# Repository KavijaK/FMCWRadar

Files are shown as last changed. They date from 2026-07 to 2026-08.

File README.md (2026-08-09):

# 6 GHz FMCW Radar

A custom Frequency-Modulated Continuous-Wave radar project for contactless distance, velocity, and breathing-rate measurement.

The project combines a mixed-signal RF PCB, STM32-based high-speed data acquisition, USB streaming, and host-side radar signal processing. The board generates a swept 6 GHz-class RF signal, receives reflections, converts them into a lower-frequency beat signal, digitizes that signal, and sends the raw samples to a computer for analysis.

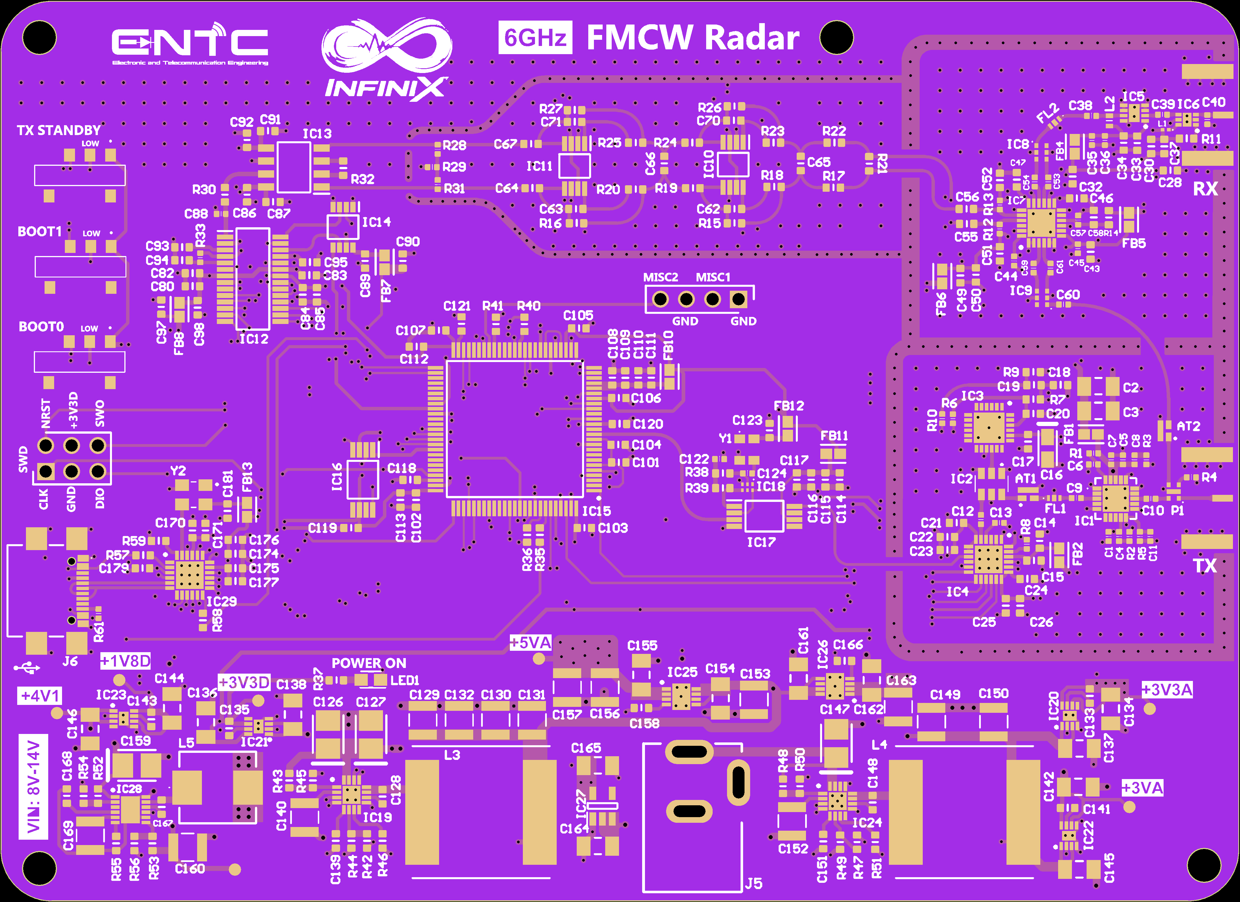
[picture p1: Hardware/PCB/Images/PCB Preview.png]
FMCW radar PCB preview


## What Is FMCW Radar?

FMCW stands for Frequency-Modulated Continuous-Wave.

Instead of transmitting a short pulse, an FMCW radar continuously sends a signal whose frequency changes over time. This frequency sweep is called a chirp. When the transmitted signal reflects from a target and returns to the receiver, the radar mixes the received signal with a copy of the transmitted signal.

The difference between those two frequencies becomes a beat signal. That beat signal can be processed to estimate target distance. By comparing multiple chirps over time, the same radar can also estimate velocity and small periodic motion such as breathing.

```text
Swept RF chirp -> target reflection -> receiver -> mixer beat signal
               -> filtering -> ADC -> USB -> host signal processing
```

## Project Overview

This project is built as a complete radar acquisition platform:

- The RF front end transmits and receives the 6 GHz-class radar signal.
- The mixer converts the received RF signal into an IF beat signal.
- The analog filtering chain prepares the IF signal for digitization.
- A 12-bit high-speed ADC samples the IF waveform.
- An STM32F429 captures the ADC data using hardware peripherals.
- USB High Speed streams raw radar frames to a host computer.
- Host-side DSP can perform range FFTs, velocity estimation, and breathing-rate experiments.
- Custom 15 dBi welded stainless steel horn antenna array with a 3D-printed tripod mount for high-directivity 5.8 GHz FMCW RF capture.

The main design goal is to keep acquisition deterministic. The STM32 does not manually sample the ADC in a software loop. Instead, the radar uses clocked hardware capture, DMA buffering, and USB streaming so the raw waveform can be moved to the computer reliably.

## PCB Design

The board combines RF, analog, digital, power, USB, and debug sections on one PCB.

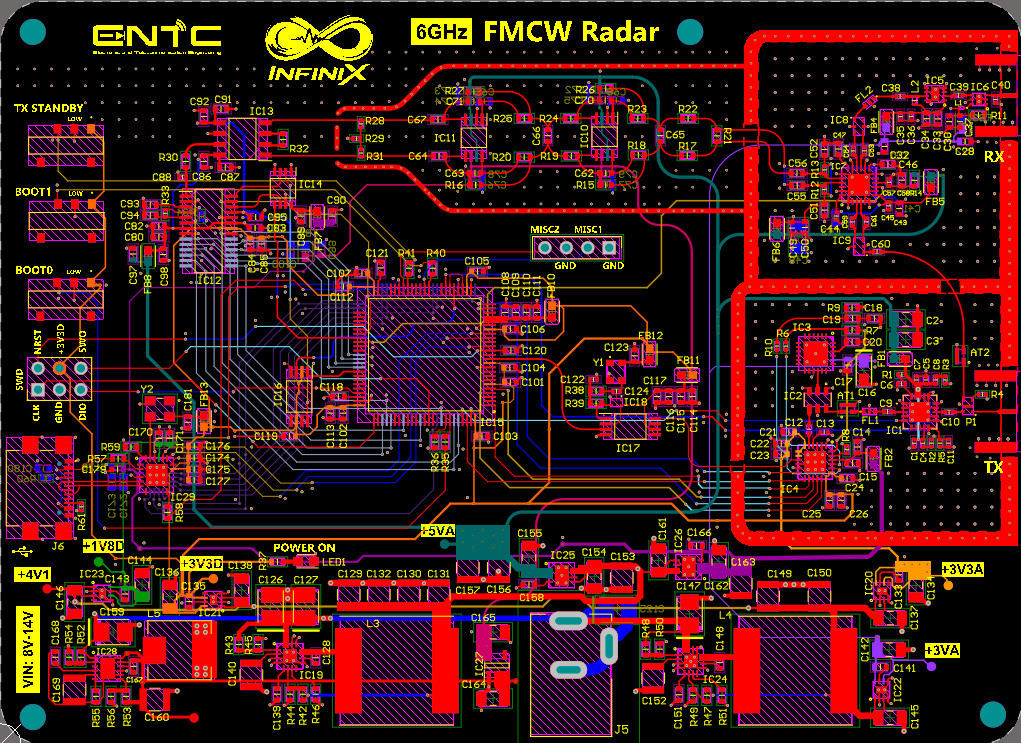
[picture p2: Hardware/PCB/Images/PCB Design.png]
FMCW radar PCB design


The RF transmit and receive sections are separated on the right side of the board. The STM32, ADC, clocking, and digital capture path sit closer to the center. The lower section contains the power supplies and USB-C interface.

## Key Specifications

| Category | Specification |
| --- | --- |
| Radar type | FMCW radar |
| RF class | 6 GHz |
| Main use cases | Distance, velocity, and breathing-rate measurement |
| Chirp / PLL device | ADF4158 |
| ADC | LTC1420 |
| ADC resolution | 12-bit |
| ADC sample rate target | 10 MSps |
| Controller | STM32F429VET6TR |
| Main acquisition interface | DCMI parallel capture |
| Data movement | DMA into SRAM frame buffers |
| USB PHY | USB3317 ULPI |
| Host link | USB 2.0 High Speed |
| Raw payload target | About 20 MB/s |
| Debug interface | SWD and SWO/SWV |
| Host processing | Python / DSP pipeline |

## Hardware Blocks

| Block | Purpose |
| --- | --- |
| Transmitter | Generates and amplifies the swept RF signal. |
| Receiver | Captures and conditions reflected RF energy. |
| Mixer | Converts RF return information into a lower-frequency IF signal. |
| IF filtering | Filters and scales the beat signal for the ADC. |
| ADC | Converts the analog IF waveform into 12-bit digital samples. |
| STM32 controller | Aligns capture timing, frames samples, and streams data. |
| USB interface | Sends raw frames to the host computer. |
| Power system | Generates the analog, digital, RF, ADC, and support rails. |

## Schematic

The full PCB schematic is available here:

[Hardware/PCB/Schematics/FMCWRadar.pdf](Hardware/PCB/Schematics/FMCWRadar.pdf)

The schematic is organized into functional pages:

| Page | Section | Description |
| --- | --- | --- |
| 1 | Transmitter | PLL, VCO, PA, coupler, detector, and RF transmit path. |
| 2 | Receiver | RF receive input, filtering, and gain chain. |
| 3 | Mixer | LO/RF mixing into differential IF outputs. |
| 4 | IF filtering | Differential IF filtering and amplification. |
| 5 | ADC | LTC1420 ADC input stage, clocking, overflow, and parallel data bus. |
| 6 | MCU | STM32F429, clock routing, DCMI bus, debug, and control signals. |
| 7 | Power supply | Regulators and analog/digital power rails. |
| 8 | USB | USB3317 ULPI PHY and USB-C connection. |
| 9 | PCB composite | Board routing and placement overview. |
| 10 | Assembly view | Component placement and reference designators. |
| 11 | BOM | Exported bill of materials. |

## What Has Been Implemented

The hardware design and firmware architecture have been brought together into a working acquisition plan:

- ADF4158-based FMCW chirp generation.
- 10 MHz ADC/DCMI sample-clock path.
- STM32 DCMI capture of the 12-bit ADC bus.
- DMA buffering for continuous high-speed sample movement.
- USB High-Speed streaming to the host computer.
- SWO/SWV debug logs for bring-up.
- Host-side frame parsing and raw capture support.

## Current Status

The project is in firmware bring-up and acquisition validation. The main staged checks are:

1. Power rail validation.
2. Clock validation.
3. USB enumeration.
4. ADF4158 chirp and MUXOUT validation.
5. ADC/DCMI sample capture validation.
6. Continuous USB streaming.
7. Range/velocity/breathing DSP experiments.

One important timing item is still under review: the acquisition architecture assumes one radar slope maps cleanly to one ADC frame. The final ADF4158 slope timing and firmware frame size must be kept consistent before using the captured data for final measurements.

## Repository Areas

| Folder | Contents |
| --- | --- |
| `CAD/` | Mechanical 3D models, horn antenna array, crossbar mounts, and STEP export files. |
| `Docs/` | Supporting documentation and project notes. |
| `DSP/` | Signal-processing work for range, velocity, and breathing-rate estimation. |
| `Firmware/` | STM32 acquisition firmware and host capture tools. |
| `Hardware/` | PCB design, schematic, BOM, and hardware design assets. |

## Goal

The goal is a clear, modular, and debuggable radar platform where each subsystem can be tested independently:

- RF transmit and receive chain
- Mixer and IF path
- ADC sampling
- STM32 capture timing
- USB data streaming
- Host-side radar DSP

That structure makes the project easier to debug, easier to optimize, and easier to hand off for future development.

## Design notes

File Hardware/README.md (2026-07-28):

# Hardware

This directory contains all hardware design files for the FMCW Radar unit.

## Sub-directories

| Directory | Description |
|---|---|
| [`PCB/`](PCB/) | PCB design files including schematics, layout, and bill of materials |
| [`Enclosure/`](Enclosure/) | Mechanical enclosure design files and renderings |
| [`Testing/`](Testing/) | Hardware testing procedures and validation documentation |

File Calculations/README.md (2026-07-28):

## 1. Distance (Range) Measurements and Resolution

In an FMCW radar, distance is measured by calculating the beat frequency ($f_b$) between the transmitted and received signals. To perform this range extraction, the system captures **512 samples per chirp** to build the first dimension of the 2D range-Doppler matrix using a Fast Fourier Transform (FFT).

The system operates with a triangular waveform, sweeping from 5.7 GHz to 5.9 GHz. This provides a total sweep bandwidth ($B$) of 200 MHz. The chirp duration ($T_c$) is 2 ms (0.002 seconds).

**Range Derivation ($R$)**

The target distance is directly proportional to the measured beat frequency. By substituting the speed of light ($c = 3 \times 10^8$ m/s), the 2 ms chirp duration, and the 200 MHz bandwidth into the standard FMCW range equation:

$$
R = \frac{c \cdot T_c \cdot f_b}{2B}
$$

$$
R = \frac{(3 \times 10^8) \cdot 0.002}{2 \cdot (200 \times 10^6)} \cdot f_b
$$

$$
R = 0.0015 \cdot f_b
$$

This coefficient dictates that for every 1 Hz of beat frequency detected by the FFT, the target is 0.0015 meters away. 

**Range Resolution ($\Delta R$)**

The range resolution defines the radar's ability to distinguish between two closely spaced targets in traffic. It is dictated entirely by the 200 MHz bandwidth:

$$
\Delta R = \frac{c}{2B}
$$

$$
\Delta R = \frac{3 \times 10^8}{400 \times 10^6} = 0.75
$$

The system provides a strict range resolution of **0.75 meters**.

**Maximum ADC Limit**

Because the transmitted bandwidth sweeps from 5.7 GHz to 5.9 GHz over 2 ms, the maximum expected beat frequency ($f_b$) for typical traffic targets maxes out at approximately 200 kHz. Since the external ADC operates at a massive 10 MHz sampling frequency, the Nyquist limit (5 MHz) is vastly higher than the 200 kHz beat signal. Therefore, the ADC limit does not constrain or affect the range calculations; the maximum detectable range is strictly limited by the physical transmitting power and environmental losses.

---

## 2. Velocity (Doppler) Measurements and Resolution

Velocity tracking in this architecture employs a dual-method approach to ensure precise slow-speed resolution while accommodating high-speed traffic. The system builds a 2D matrix using **128 chirps** ($N_c$) and 512 samples per chirp to perform a 2D Doppler FFT. For these calculations, the wavelength ($\lambda$) at 5.8 GHz is 0.0517 meters.

**Doppler Velocity Derivation ($v$)**

For micro-Doppler and fine speed measurements, velocity is extracted by analyzing the phase shift ($\Delta \phi$) of the beat signal across consecutive chirps:

$$
v = \frac{\lambda \cdot \Delta \phi}{4\pi T_c}
$$

$$
v = \frac{0.0517 \cdot \Delta \phi}{4\pi \cdot 0.002}
$$

$$
v \approx 2.057 \cdot \Delta \phi
$$

**Velocity Resolution ($\Delta v$)**

The resolution defines the minimum speed difference required to separate two targets moving at the exact same distance. It is defined by the total observation frame time (128 chirps $\times$ 2 ms = 0.256 seconds):

$$
\Delta v = \frac{\lambda}{2 N_c T_c}
$$

$$
\Delta v = \frac{0.0517}{2 \cdot 128 \cdot 0.002}
$$

$$
\Delta v \approx 0.101
$$

The 2D matrix yields a highly sensitive velocity resolution of **0.101 m/s**.

**Maximum Unambiguous Doppler Velocity ($v_{max}$) and Range-Rate Tracking**

To prevent velocity aliasing in the Doppler phase, the phase shift between chirps must remain under 180 degrees. Using the 2 ms chirp time, the theoretical limit is:

$$
v_{max} = \frac{\lambda}{4 T_c} = \frac{0.0517}{4 \cdot 0.002} = 6.4625
$$

Because standard traffic routinely exceeds this **6.46 m/s** Doppler limit, the system utilizes **Range-Rate Tracking** to measure high-speed vehicles. By tracking the absolute movement of a target's range bin ($\Delta R$) across consecutive radar frames ($\Delta t$), the processing backend extracts the true absolute velocity ($v = \frac{\Delta R}{\Delta t}$). This completely bypasses the Doppler aliasing constraint, allowing accurate tracking of vehicles traveling at 20 m/s and beyond.

---

## 3. Power Propagation and The Radar Equation

The physical limit of the radar's detection capabilities relies on how much of the transmitted power makes it back to the receiver. The system transmits at an output power of **23 dBm**, which equates to **0.2 Watts** of linear power. 

**Deriving the Radar Equation**

The journey of the RF signal is mapped using the standard radar range equation:
1.  **Transmission:** The 0.2 W signal is focused by the directional gain ($G$) of the antenna, creating a power density at the target of $\frac{P_t G}{4\pi R^2}$.
2.  **Target Reflection:** The target (e.g., a pedestrian with a Radar Cross Section $\sigma$ of 1 square meter) reflects a portion of this energy back: $\frac{P_t G \sigma}{4\pi R^2}$.
3.  **Capture:** The receiving antenna captures this energy based on its effective aperture ($A_e = \frac{G \lambda^2}{4\pi}$). 

Combining these gives the total received power ($P_r$):

$$
P_r = \frac{P_t G^2 \lambda^2 \sigma}{(4\pi)^3 R^4}
$$

**Real-World Losses and the 100m Detection Threshold**

Power drops off as the inverse fourth power of the distance ($\frac{1}{R^4}$), meaning the returning signal weakens rapidly. Given real-world thermal losses, atmospheric spreading, and a realistic thermal noise floor of roughly -103 dBm for the active bandwidth, we can map the power at the receiver for a 1 square meter target using a 10 dBi antenna.

**Received Power vs. Distance Chart (1 square meter Target)**

| Distance | Received Power (Watts) | Received Power (dBm) |
| :--- | :--- | :--- |
| **10 m** | $2.694 \times 10^{-9}$ | **-55.69 dBm** |
| **20 m** | $1.684 \times 10^{-10}$ | **-67.73 dBm** |
| **30 m** | $3.326 \times 10^{-11}$ | **-74.78 dBm** |
| **40 m** | $1.052 \times 10^{-11}$ | **-79.77 dBm** |
| **50 m** | $4.310 \times 10^{-12}$ | **-83.65 dBm** |
| **60 m** | $2.078 \times 10^{-12}$ | **-86.82 dBm** |
| **70 m** | $1.121 \times 10^{-12}$ | **-89.50 dBm** |
| **80 m** | $6.577 \times 10^{-13}$ | **-91.82 dBm** |
| **90 m** | $4.106 \times 10^{-13}$ | **-93.86 dBm** |
| **100 m** | $2.694 \times 10^{-13}$ | **-95.69 dBm** |

At 100 meters, the returning power is -95.69 dBm. This sits safely above the thermal noise floor, providing a mathematically viable signal-to-noise ratio to detect a person at that distance before requiring extensive digital frame averaging to pull the signal out of the clutter.

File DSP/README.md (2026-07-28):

#  Digital Signal Processing (DSP) Core

This directory contains the complete signal processing pipeline for the FMCW Radar. It transforms raw, time-domain Intermediate Frequency (IF) signals sampled by the ADC into actionable spatial data (Range, Velocity, and Micro-displacement).

## 📂 Sub-Directory Architecture

| Module | Core Function | Output Data Type |
| :--- | :--- | :--- |
| [`/DistanceMeasurement`](DistanceMeasurement/) | Fast-Time 1D-FFT | Range Profile (Spatial distance) |
| [`/VelocityEstimation`](VelocityEstimation/) | Slow-Time 2D-FFT | Range-Doppler Map (Macro-velocity) |
| [`/BreathingPaceMeasurement`](BreathingPaceMeasurement/) | Phase Unwrapping | Micro-Doppler displacement (Vibration/Vitals) |
| [`/Utils`](Utils/) | CFAR, Filters, Windowing | Threshold masks & Filtered arrays |

## 🔄 The Data Processing Pipeline

In FMCW radar, data is processed in a 2D matrix format known as **Fast-Time** (samples within a single chirp) and **Slow-Time** (successive chirps over time).

```text
[Raw ADC Stream] ──(De-interleave)──> M x N Matrix (M chirps, N samples)
                                              │
                                              ▼
┌─────────────────────────────────────────────────────────────┐
│ 1. DISTANCE MEASUREMENT (Fast-Time Processing)              │
│    - DC Offset Removal & Hamming Windowing                  │
│    - 1D FFT across N samples                                │
│    - Output: Range Bins (Where are the targets?)            │
└─────────────────────────────┬───────────────────────────────┘
                              │
                              ▼
┌─────────────────────────────────────────────────────────────┐
│ 2. VELOCITY ESTIMATION (Slow-Time Processing)               │
│    - 1D FFT across M chirps (for each Range Bin)            │
│    - Measures Phase Rotation (Δφ) between chirps            │
│    - Output: Range-Doppler Map (How fast are they moving?)  │
└─────────────────────────────┬───────────────────────────────┘
                              │
                              ▼
┌─────────────────────────────────────────────────────────────┐
│ 3. TARGET EXTRACTION & MICRO-DOPPLER                        │
│    - CFAR (Constant False Alarm Rate) Target Detection      │
│    - Phase Extraction on specific target bins               │
│    - Output: Object Tracking & Sub-millimeter vibrations    │
└─────────────────────────────────────────────────────────────┘
- All algorithms are designed to run on the host processing system receiving data from the STM32 firmware over USB/UART.
- Python (NumPy / SciPy) is the recommended language for prototyping; C/C++ for embedded deployment.

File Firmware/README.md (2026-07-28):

# FMCW Radar Acquisition Firmware

This repository implements the architecture in `c:\Users\karun\Downloads\fmcw_architecture.html` for the STM32F429VET6TR + LTC1420 + ADF4158 + USB3317 board. The CubeMX project at `C:\Users\karun\OneDrive\Desktop\FMCWRadarFirmware` was used as the board pin source for this merge.

The firmware is built as an STM32Cube/HAL project with register-level setup for the timing-critical path:

- HSE 20 MHz bypass clock, PLL to 168 MHz, MCO1 = HSE / 2 = 10 MHz
- DCMI in 12-bit continuous mode with PA4 held as static active-high HSYNC
- DMA2 Stream 1 Channel 1 in double-buffer mode, extended to a 4-frame SRAM ring
- TIM9 input capture/reset mode on PE5 for one-shot alignment and MUXOUT diagnostics
- USB OTG HS ULPI vendor-specific bulk IN endpoint with internal DMA enabled
- Host-side Python receiver/parser with resync, stats, raw save, and optional FFT preview

## Start Here

Read these in order:

1. `README.md` for the system overview and build commands.
2. `docs/board_configuration.md` for board-specific pins and options.
3. `docs/bringup.md` for the scope/checklist sequence.
4. `firmware/Core/Inc/fmcw_board_config.h` for the actual pins compiled into firmware.
5. `firmware/Core/Src/main.c`, then `fmcw_hardware.c`, then `fmcw_capture.c` for the runtime flow.

## Layout

- `firmware/` - STM32F429 firmware sources, linker script, and CMake build metadata.
- `host/` - Python host receiver and protocol parser.
- `tests/` - Host-side protocol tests that run without USB hardware.
- `docs/` - Bring-up notes and board-configuration notes.

## Build Firmware

Install Arm GNU Toolchain and STM32CubeF4, then configure with:

```powershell
cmake -S firmware -B build/firmware `
  -DCMAKE_TOOLCHAIN_FILE=firmware/cmake/arm-none-eabi-gcc.cmake `
  -DSTM32_CUBE_F4_PATH=C:/Users/karun/STM32Cube/Repository/STM32Cube_FW_F4_V1.28.3
cmake --build build/firmware
```

The project expects the standard STM32CubeF4 layout containing `Drivers/` and `Middlewares/ST/STM32_USB_Device_Library/`.

## Board Configuration

All PCB-dependent choices live in `firmware/Core/Inc/fmcw_board_config.h`. Review that file before flashing:

- DCMI pins imported from CubeMX: D0=PA9, D1=PC7, D2=PC8, D3=PC9, D4=PC11, D5=PD3, D6=PB8, D7=PB9, D8=PC10, D9=PC12, D10=PD6, D11=PD2, PIXCLK=PA6, VSYNC=PB7, HSYNC drive=PA4, HSYNC feedback=PA7.
- ULPI pins imported from CubeMX: CK=PA5, STP=PC0, DIR=PC2, NXT=PC3, D0=PA3, D1=PB0, D2=PB1, D3=PB10, D4=PB11, D5=PB12, D6=PB13, D7=PB5.
- USB3317 reset is `USB_RESET` on PE13, active low.
- ADF4158 pins imported from CubeMX: SPI4 SCK=PE2, MOSI=PE6, LE=PA1, CE=PE1, MUXOUT=PE5.
- RF transmit control: `TX_STDBY` on PE11 is active high. When it is high, firmware drives `MIXER_EN` on PD13 and `PA_EN` on PE0 high. When it is low, both outputs are driven low.
- Whether capture waits for USB enumeration before enabling TIM9/alignment

Two generated CubeMX choices were intentionally not copied:

- CubeMX generated `SYSCLK=180 MHz`; the firmware keeps `168 MHz` because the architecture's TIM9 alignment uses 13 ticks at a 42 MHz timer count rate, approximately the LTC1420 3-cycle/300 ns pipeline delay.
- DCMI now samples on the falling PIXCLK edge per board bring-up request, while keeping active-high HSYNC with PA4 driven high once after the first MUXOUT alignment event. PA7 is read back as the routed HSYNC feedback signal.

The ADF4158 frequency/ramp register values are necessarily board/application-specific. The driver and call order are implemented, but the register table must be filled with the final PLL plan for your RF center frequency and deviation.

## Firmware Flow

- `main.c`: Initializes HAL, clocks, GPIO, USB, DCMI, DMA, TIM9, then continuously services TX standby, USB streaming, and the MUXOUT watchdog.
- `fmcw_hardware.c`: Owns clocks, GPIO modes, USB PHY reset, DCMI, DMA2 Stream 1, TIM9, NVIC, and TX standby gating.
- `fmcw_capture.c`: Owns the 4-buffer SRAM ring, slope sequence numbers, MUXOUT timestamps, DMA completion handling, and USB queue handoff.
- `fmcw_adf4158.c`: Optional SPI programming path for ADF4158. It is disabled until `FMCW_ENABLE_ADF4158_AUTOPROGRAM` is set and real register values are added.
- `usb_stream.c` and `usbd_vendor_stream.c`: Expose a vendor-specific USB HS bulk IN stream.

## Host Capture

```powershell
pip install -r host/requirements.txt
python host/fmcw_capture.py --frames 1000 --raw out_frames.bin --stats
```

Run protocol tests:

```powershell
python -m unittest discover -s tests
```

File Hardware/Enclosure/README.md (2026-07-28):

# Enclosure Design

This directory contains all mechanical enclosure design files for the FMCW Radar unit.

## Sub-directories

| Directory | Description |
|---|---|
| [`CAD/`](CAD/) | 3D CAD model files (e.g., `.step`, `.stl`, `.f3d`, FreeCAD projects) |
| [`Renders/`](Renders/) | Rendered images of the enclosure design |

## Design Notes

- The enclosure is designed to house the FMCW Radar PCB
- Provisions for antenna apertures and cable routing are included
- Suitable for 3D printing or CNC fabrication

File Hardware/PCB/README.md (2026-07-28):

# PCB Design

This directory contains all PCB design files for the FMCW Radar unit based on the STM32 microcontroller.

## Sub-directories

| Directory | Description |
|---|---|
| [`Schematics/`](Schematics/) | Circuit schematics (e.g., KiCad `.sch` / `.kicad_sch` files, PDF exports) |
| [`Layout/`](Layout/) | PCB layout files (e.g., KiCad `.kicad_pcb`, Gerber files) |
| [`BOM/`](BOM/) | Bill of Materials (component lists and part references) |

## Design Notes

- Target MCU: STM32
- RF front-end interfaces with the STM32 via ADC/SPI
- Radar transmit and receive paths are on-board

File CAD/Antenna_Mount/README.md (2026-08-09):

# Antenna & Mount Mechanical Assembly

This directory contains the CAD models, part files, and physical specifications for the dual 5.8 GHz FMCW pyramidal horn antenna array and crossbar mount assembly.

---

## Design & Physical Hardware Preview

| CAD Model Render | Real-World Field Setup |
| :---: | :---: |
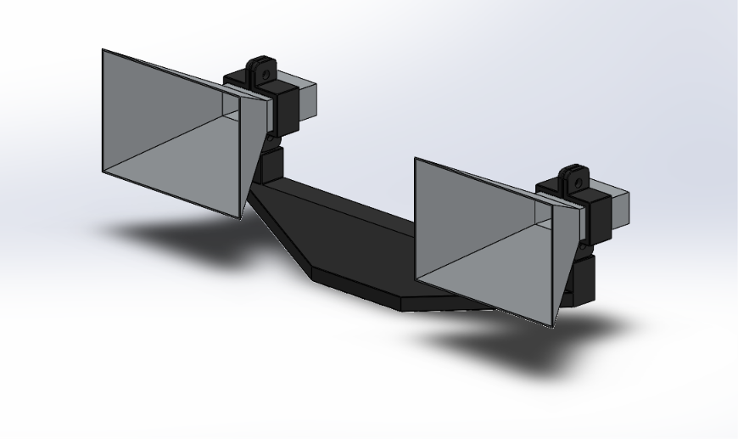
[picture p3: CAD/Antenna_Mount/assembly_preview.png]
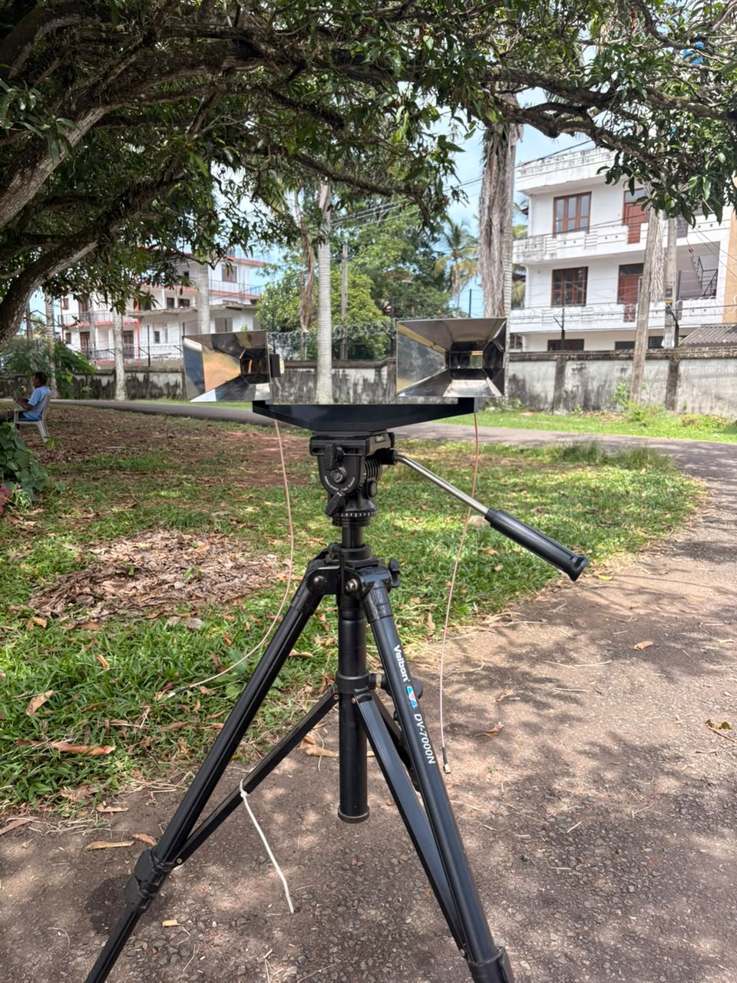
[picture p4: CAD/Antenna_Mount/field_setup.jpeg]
|  |  |
| *Figure 1: SolidWorks CAD assembly model.* | *Figure 2: Physical hardware mounted on tripod during outdoor testing.* |
---

## Assembly & Mounting Setup

* **Fasteners:** Waveguide clips and crossbar attachments are securely fastened using standard **nuts and bolts** for rigid mechanical alignment.
* **Support Base:** The crossbar assembly features a tripod adapter mount, allowing the entire dual-horn structure to be mounted on a **Velbon DV-7000N tripod** for flexible height and tilt adjustments during field testing.

---

## File Inventory

### 1. SolidWorks Native Files (`.SLDASM` / `.SLDPRT`)
* **`Final_Assy.SLDASM`** – Full dual-antenna array and crossbar assembly.
* **`Horn_Antenna_Single_Assy.SLDASM`** – Sub-assembly for a single horn antenna with waveguide mount clip.
* **`Horn_Antenna_15dBi.SLDPRT`** – 15 dBi pyramidal horn antenna body.
* **`Antenna_Mount_Crossbar.SLDPRT`** – Main structural crossbar mounting frame.
* **`Waveguide_Mount_Clip.SLDPRT`** – Waveguide retaining clip for mechanical stability.

### 2. Universal Formats (`.STEP`)
* **`STEP/Final_Assy.STEP`** – Universal AP214 / AP242 STEP export for cross-platform CAD software and manufacturing.

---

## Fabrication & Manufacturing Specs

| Component | Fabrication Method / Material | Key Notes |
| :--- | :--- | :--- |
| **Horn Antenna Body** | Handmade (Welded Stainless Steel) | Custom sheet metal fabrication; designed for **15 dBi target gain** @ 5.8 GHz |
| **Crossbar Mount** | 3D-Printed (PLA/PETG) | Structural frame aligning dual horn antennas with fixed spacing |
| **Waveguide Mount Clip** | 3D-Printed (PLA/PETG) | Custom clip securing stainless steel horns to crossbar support via nuts & bolts |

---

## Usage Notes
1. **Opening in SolidWorks:** Open **`Final_Assy.SLDASM`** directly. Keep all `.SLDPRT` files in the same directory to prevent missing component references.
2. **Cross-Platform / Viewing:** Open **`STEP/Final_Assy.STEP`** in non-SolidWorks software (such as Fusion 360, FreeCAD, or web viewers) to inspect 3D geometry and colors.

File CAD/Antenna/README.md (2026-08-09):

# Antenna Mechanical Models

This folder contains the CAD files, and physical specifications for the antenna.

## Design Preview & Dimensions

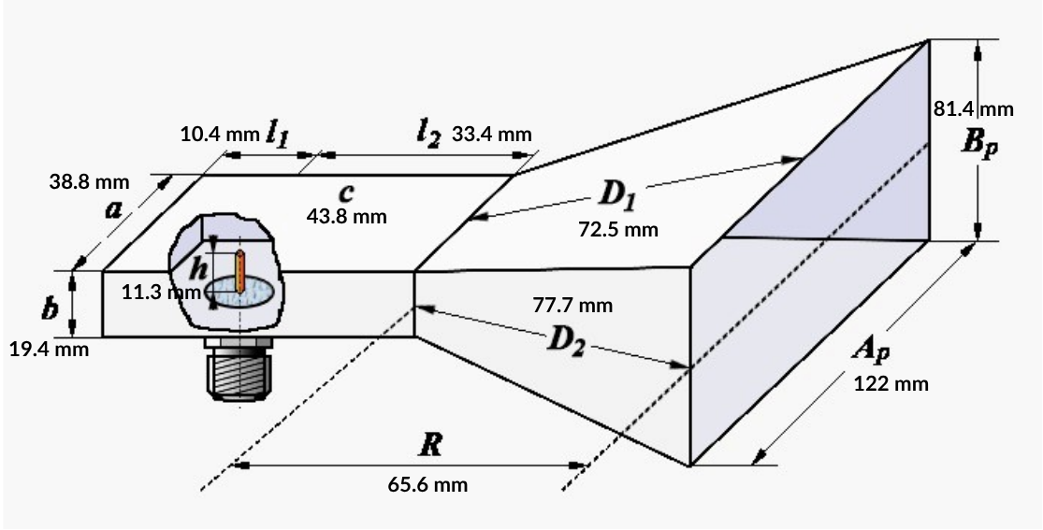
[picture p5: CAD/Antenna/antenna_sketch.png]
Antenna Design Sketch

*Figure 1: Antenna geometry and key dimensions.*

---

## Files
* `Horn_Antenna_15dBi.SLDPRT` – Native SolidWorks part file.
* `Horn_Antenna_15dBi.STEP` – Universal CAD format for cross-platform compatibility.

## Manufacturing Specs
* **Material:** Stainless Steel
* **Feed Point Location:** 11.3 mm from edge

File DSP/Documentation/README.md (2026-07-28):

## 1. The High-Bandwidth Bottleneck & USB Bulk Transfer Design

**The Engineering Challenge:**
The radar utilizes a 10 MHz sampling rate. At 16 bits per sample, the ADC generates 20 Megabytes of data per second. Traditional microcontroller-to-PC interfaces (such as Virtual COM/CDC over Full-Speed USB) are physically limited to roughly 1.5 MB/s and rely on unstructured, continuous byte streams. This causes OS-level buffer overflows, dropped bytes, and catastrophic phase misalignment in the radar data.

**The Design Choice: Packetized USB Bulk Transfers**
To guarantee zero data loss, the architecture abandons Virtual COM ports entirely in favor of raw USB High-Speed (480 Mbps) Bulk Transfers. Rather than streaming data continuously, the STM32 microcontroller's Direct Memory Access (DMA) accumulates an exact predefined block of data (e.g., 20,480 bytes). The USB hardware then transmits this entire block as one atomic "packet." The host operating system guarantees that USB Bulk packets arrive exactly as packaged, meaning the host software never has to guess where a radar sweep begins or ends. The physical packet boundary *is* the sweep boundary.

## 2. Hardware-Level Synchronization & Header Processing

**The Engineering Challenge:**
A triangular FMCW radar alternates between sweeping the frequency UP and sweeping it DOWN. To process this mathematically, the host computer must perfectly separate the UP sweeps from the DOWN sweeps. Relying on software to analyze the analog wave to find the turning point is computationally expensive and highly susceptible to noise.

**The Design Choice: Explicit Hardware State Injection**
Synchronization is handled entirely on the silicon. Before the STM32 transmits a 20,000-byte ADC payload, it prefixes it with a 64-byte metadata header. This header contains two critical pieces of information:

*   **The Magic Word (`0x52444152`):** A static 32-bit hexadecimal anchor. If the host PC does not see this exact sequence at the start of a packet, the packet is instantly discarded. This makes the system immune to cable noise or initialization glitches.
*   **The Slope ID:** A binary state indicator (`0` for UP, `1` for DOWN) generated directly by the hardware timer that controls the radar's VCO.

By injecting the hardware's internal state machine directly into the data stream, the host computer performs zero alignment calculations. It simply reads the Slope ID, routes the attached payload to the corresponding UP or DOWN memory bank, and waits for a matching pair.

## 3. Data Unpacking and Analog Signal Reconstruction

**The Engineering Challenge:**
The ADC generates 12-bit samples. Storing a 12-bit sample in a standard 16-bit integer wastes 4 bits (25% of the total bandwidth). Furthermore, radar beat signals are AC waveforms (swinging above and below a central zero-point). The ADC outputs these as raw unsigned values (e.g., 0 to 4095), which distorts the mathematical phase required for Fourier analysis.

**The Design Choice: 32-bit Bit-Packing and Two's Complement Extension**
To maximize the 20 MB/s USB bandwidth, the STM32 packs two 12-bit ADC samples into a single 32-bit word before transmission.

On the host side, extracting this data requires high-speed bitwise manipulation:
*   **Masking:** A bitmask isolates the lower 12 bits for Sample A, and a right-shift isolates the upper 12 bits for Sample B.
*   **Sign Extension:** Because the 12-bit ADC values represent an alternating current, the 12th bit is actually the "sign bit." The host software uses arithmetic bit-shifting to force this 12th bit into the 16th-bit position. This mathematically converts the raw unsigned ADC readings into perfect signed 16-bit integers, restoring the true negative and positive voltage swings of the physical waveform without requiring heavy floating-point math during extraction.

## 4. Matrix Arrangement: Fast-Time vs. Slow-Time

To extract a target's velocity, a single radar sweep is insufficient. The radar must observe the target over a Coherent Processing Interval (CPI).

**The Design Choice: The Radar Data Cube (2D Matrix)**
The host collects exactly 128 UP/DOWN pairs to form one CPI (representing ~256 milliseconds of observation). The data is arranged into two distinct matrices (one for UP sweeps, one for DOWN sweeps).
*   **The X-Axis (Fast-Time):** Contains the 10,000 samples collected during a single 1 ms sweep. This axis captures the instantaneous beat frequency, which corresponds to the target's distance.
*   **The Y-Axis (Slow-Time):** Contains the 128 individual sweeps. This axis captures how the target moves from one sweep to the next, which corresponds to the target's velocity.

## 5. The Mathematics of the Dual 2D Fourier Transform

The core of the digital signal processing pipeline transforms these matrices from the time domain into the frequency domain to isolate targets.

**Step A: Windowing (Suppressing Spectral Leakage)**
Because the radar only observes the target for finite intervals (1 ms sweeps), the edges of the time-domain signal are abruptly cut off. In the frequency domain, this sudden cut-off convolves with the signal, creating a Sinc function ($\frac{\sin(x)}{x}$) that leaks noise across the spectrum. Before processing, the data is multiplied by a **Hann Window**—a bell-shaped curve that smoothly tapers the edges of the signal to zero, ensuring sharp, narrow frequency peaks.

**Step B: The Range FFT (Fast-Time Analysis)**
A 1D FFT is applied across the X-axis of the matrix. For a transmitted frequency $f_T$ and received frequency $f_R$, the beat frequency $f_b = |f_T - f_R|$. The FFT identifies the dominant beat frequencies in the sweep, yielding the target's apparent range.

**Step C: The Doppler FFT (Slow-Time Analysis)**
As a target moves a microscopic distance $\Delta d$ between sweeps, the reflected wave undergoes a phase shift:
$$ \Delta\phi = \frac{4\pi \Delta d}{\lambda} $$
A second 1D FFT is applied vertically across the Y-axis. This mathematical operation isolates the rate of change of $\Delta\phi$ across the 128 sweeps, separating targets based entirely on their radial velocity.

**Step D: The Zero-Velocity Shift**
Because standard FFT algorithms output frequencies starting from zero and wrapping around, the matrix is mathematically shifted to place $0$ Hz in the exact center. This maps approaching vehicles to the positive upper-half of the matrix, and receding vehicles to the negative lower-half.

## 6. Target Detection and Range-Doppler Decoupling

**The Engineering Challenge (Range-Doppler Coupling):**
In FMCW radar, a target's velocity imposes a Doppler shift on the returning wave.
*   If a vehicle is driving towards the radar, the wave is compressed (higher frequency).
*   During an UP sweep, this higher frequency makes the vehicle appear *closer* than it is.
*   During a DOWN sweep, this same higher frequency makes the vehicle appear *further* than it is.

**The Design Choice: Triangular Averaging**
This is the primary reason the system utilizes a triangular waveform and processes two separate matrices. By running the 2D FFT on both the UP matrix and the DOWN matrix, the system generates two separate Range-Doppler heatmaps.

The detection algorithm identifies the target's peak frequency in the UP heatmap ($f_{up}$) and its peak in the DOWN heatmap ($f_{down}$). Because the Doppler shift pushes these two peaks in exactly opposite directions by the exact same amount, the true, error-free range frequency ($f_{true}$) is isolated by simply averaging them:
$$ f_{true} = \frac{f_{up} + f_{down}}{2} $$

**Final Physical Conversion:**
With the exact, uncoupled beat frequency isolated, the absolute distance to the target ($R$) is calculated using the speed of light ($c$), the sweep bandwidth ($BW$), and the sweep duration ($T_c$):
$$ R = f_{true} \times \left( \frac{c \cdot T_c}{2 \cdot BW} \right) $$
The velocity ($v$) is extracted directly from the target's Y-axis position (the Doppler bin) on the heatmap, calculated as:
$$ v = f_{doppler} \times \frac{\lambda}{2} $$

Through this architecture, hardware-enforced synchronization and dual-matrix fourier mathematics combine to produce a high-resolution, uncoupled telemetry feed capable of tracking multiple high-speed targets simultaneously.

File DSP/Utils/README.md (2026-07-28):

#  DSP Utilities & Helper Functions

This directory contains shared mathematical and structural tools utilized across the DSP pipeline. Centralizing these functions ensures consistency between the Range and Doppler processing stages.

## Core Components

### 1. CFAR (Constant False Alarm Rate)
Simple thresholding (e.g., "detect any peak over 50 dB") fails in dynamic environments due to fluctuating noise floors. We implement **CA-CFAR (Cell-Averaging CFAR)**:
* The algorithm slides a window across the FFT output.
* It calculates the average noise level in the "Training Cells" surrounding the "Target Cell."
* A detection is only triggered if the Target Cell exceeds the local noise average by a predefined threshold factor ($\alpha$).

### 2. Windowing Functions
Wrappers for standard DSP windows applied to raw data to mitigate spectral leakage.
* **Hamming Window:** Used for Range processing to suppress strong sidelobes from large targets (e.g., walls) that might mask smaller targets (e.g., pedestrians).

### 3. I/Q Matrix Reshaping
Functions to correctly slice the raw 1D serial byte-stream from the STM32 ADC into the proper $M \times N$ (Chirps $\times$ Samples) matrices required for 2D processing.

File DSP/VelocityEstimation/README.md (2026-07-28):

#  Velocity Estimation (Doppler FFT)

This module processes the **Slow-Time** data. It uses the "Double FFT" architecture to extract velocity information independently of the range measurement.

##  The Mathematics

The Doppler frequency ($f_d$) is the derivative of the phase over time:
$$f_d = \frac{1}{2\pi} \cdot \frac{d\phi}{dt}$$

Once $f_d$ is extracted via the second FFT, radial velocity ($v$) is calculated as:
$$v = \frac{f_d \cdot \lambda}{2}$$

### The Nyquist Velocity Limit ($v_{max}$)
If a target moves so fast that the phase rotates more than $180^\circ$ ($\pi$ radians) between two chirps, the system experiences velocity aliasing. The maximum measurable speed is constrained by the Chirp Repetition Interval ($T_{pri}$):
$$v_{max} = \frac{\lambda}{4 \cdot T_{pri}}$$

To measure faster targets (e.g., highway traffic), $T_{pri}$ must be minimized in the hardware configuration.

##  The "Phase Shift" Concept
The Range FFT (Fast-Time) is not precise enough to measure the tiny distance a target moves during a single chirp ($T_c$). However, because the radar wavelength ($\lambda$) is very small, even a millimeter of movement causes a massive shift in the **Phase ($\phi$)** of the reflected signal.

By analyzing the same Range Bin across $M$ consecutive chirps, we track the rate of phase rotation.

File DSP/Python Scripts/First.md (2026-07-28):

import serial
import numpy as np
import time
from multiprocessing import Process, Queue
from queue import Full
import matplotlib.pyplot as plt

# physical parameters
C = 3e8                   # Speed of light
FC = 5.8e9                # Carrier frequency (5.8 GHz)
BW = 200e6                # Bandwidth (200 MHz)
TC = 1e-3                 # Chirp time (1 ms)
IDLE_TIME = 0.1e-3
CHIRP_PERIOD = TC + IDLE_TIME
LAMBDA = C / FC           # Wavelength

# Hardware & Radar Constants
SAMPLING_FREQ = 5e6
SAMPLES_PER_CHIRP = int(SAMPLING_FREQ * TC)
CHIRPS_PER_FRAME = 256
BYTES_PER_CHIRP = SAMPLES_PER_CHIRP * 2       # 16 bit samples

def data_producer(queue, port, baud):
    """Thread 1: Hunts for the Sync Header and pushes complete single chirps."""

    # 1. Define the connection loop inside the producer
    def connect_to_radar():
        while True:
            try:
                # Timeout must stay 0.1 for the sliding window buffer to work smoothly
                s = serial.Serial(port, baud, timeout=0.1) 
                print("\n[PRODUCER] Radar Hardware Detected and Connected.")
                return s
            except serial.SerialException:
                print("[PRODUCER] Waiting for Radar PCB to be plugged in...")
                time.sleep(2)
    
    # 2. Initial Connection
    ser = connect_to_radar()

    SYNC_WORD = b'\xff\xff\xff\xff' 
    buffer = bytearray()

    while True:
        try:
            # Try to read incoming bytes
            incoming = ser.read(max(1, ser.in_waiting))
            if incoming:
                buffer.extend(incoming)
            
            # --- The rest of your Sync Hunter logic remains exactly the same ---
            sync_index = buffer.find(SYNC_WORD)
            if sync_index != -1:
                target_length = sync_index + len(SYNC_WORD) + BYTES_PER_CHIRP
                if len(buffer) >= target_length:
                    start_data = sync_index + len(SYNC_WORD)
                    end_data = start_data + BYTES_PER_CHIRP
                    pure_data = buffer[start_data:end_data]
                    
                    try:
                        queue.put_nowait(pure_data)
                    except Full:
                        pass
                    
                    buffer = buffer[end_data:]
            else:
                if len(buffer) > BYTES_PER_CHIRP * 3:
                    buffer = buffer[-BYTES_PER_CHIRP:] 
                    
        # 3. Handle Mid-Operation Disconnections
        except serial.SerialException:
            print("\n[PRODUCER] ERROR: Connection lost! (Cable unplugged?)")
            ser.close()             # Close the broken port
            buffer.clear()          # Delete partial/corrupt data
            ser = connect_to_radar() # Block and wait until it's plugged back in
            
        except KeyboardInterrupt:
            break
            
    if ser.is_open:
        ser.close()

def data_consumer(queue):
    """Thread 2: Stacks chirps into a Matrix and performs the 2D FFT."""
    
    # Pre-compute windows for efficiency
    range_window = np.hanning(SAMPLES_PER_CHIRP)
    doppler_window = np.hanning(CHIRPS_PER_FRAME)
    
    # Reshape doppler window to column vector for matrix multiplication
    doppler_window = doppler_window.reshape(-1, 1) 

    # ----- NEW CODE: SETUP THE VISUAL MAP (Run once before the loop) ----------------
    plt.ion() 
    fig, ax = plt.subplots(figsize=(8, 6))
    
    range_step = (SAMPLING_FREQ / SAMPLES_PER_CHIRP) * (C * TC / (2 * BW))
    max_range = (SAMPLES_PER_CHIRP // 2) * range_step
    vel_step = ((1 / CHIRP_PERIOD) / CHIRPS_PER_FRAME) * (LAMBDA / 2)
    max_vel = (CHIRPS_PER_FRAME // 2) * vel_step
    
    plot_extent = [0, max_range, -max_vel, max_vel]
    empty_data = np.zeros((CHIRPS_PER_FRAME, SAMPLES_PER_CHIRP // 2))
    
    # --- CHANGED: 'turbo' colormap and 'gaussian' blending for realistic radar look ---
    img = ax.imshow(empty_data, extent=plot_extent, aspect='auto', origin='lower', 
                    cmap='turbo', interpolation='gaussian')
    
    ax.set_title("Live Range-Doppler Heatmap")
    ax.set_xlabel("Range (Meters)")
    ax.set_ylabel("Velocity (m/s)")
    
    # --- LIMIT THE X-AXIS TO 100 METERS ---
    ax.set_xlim(0, 100) 
    
    fig.colorbar(img, ax=ax, label="Magnitude (dB)")
    plt.show()
    # -----------------------------------------------------------------------

    while True:
        frame_data = []
        
        # 1. Collect enough chirps to build one Frame (Matrix)
        while len(frame_data) < CHIRPS_PER_FRAME:
            raw_bytes = queue.get()
            # signal = np.frombuffer(raw_bytes, dtype=np.uint16)
            signal = np.frombuffer(raw_bytes, dtype=np.uint16).astype(np.float32)
            
            # Remove DC offset immediately
            signal = signal - np.mean(signal)
            frame_data.append(signal)
            
        # 2. Convert list of arrays into a 2D Numpy Matrix # Shape: (128 rows, 500 columns)
        radar_matrix = np.vstack(frame_data) 
        
        # 3. RANGE FFT (Horizontal) # Apply window to every row, then FFT along the rows (axis=1)
        matrix_windowed_1d = radar_matrix * range_window
        range_fft = np.fft.fft(matrix_windowed_1d, axis=1)
        
        # Take only the positive frequencies (first half of columns)
        range_fft = range_fft[:, :SAMPLES_PER_CHIRP // 2]
        
        # 4. DOPPLER FFT (Vertical) # Apply window to every column, then FFT down the columns (axis=0)
        matrix_windowed_2d = range_fft * doppler_window
        doppler_fft = np.fft.fft(matrix_windowed_2d, axis=0)
        
        # 5. Shift Zero-Velocity to the center
        # By default, FFT puts 0 Hz at index 0. For velocity, we want # negative speeds on the left, 0 in the middle, positive on the right.
        range_doppler_map = np.fft.fftshift(doppler_fft, axes=0)
        
        # 6. Extract Magnitude for Visualization/Detection
        rd_magnitude = np.abs(range_doppler_map)

        # -----NEW CODE: PUSH DATA TO THE MAP (Runs every frame) -------------
        rd_db = 20 * np.log10(rd_magnitude + 1e-10) # Convert to decibels
        img.set_data(rd_db)                         # Push to graph
        img.set_clim(vmin=np.max(rd_db) - 60, vmax=np.max(rd_db)) # Adjust colors
        fig.canvas.flush_events()                   # Redraw screen
        #----------------------------------------------------------------------

        # --- DETECTION LOGIC ---
        # Find the coordinates (row, col) of the brightest pixel in the 2D map
        target_idx = np.unravel_index(np.argmax(rd_magnitude), rd_magnitude.shape)
        doppler_bin = target_idx[0]
        range_bin = target_idx[1]
        
        # Convert bins to actual physical units
        range_res = C / (2 * BW)
        range_freq = range_bin * (SAMPLING_FREQ / SAMPLES_PER_CHIRP)
        target_range = range_freq * (C * TC / (2 * BW))
        
        # Velocity = (Lambda / 2) * (Doppler_Freq)  # Doppler bin ranges from -128 to +128 (because of fftshift)
        doppler_shifted_idx = doppler_bin - (CHIRPS_PER_FRAME // 2)
        prf = 1 / CHIRP_PERIOD              # Pulse Repetition Frequency
        doppler_freq = doppler_shifted_idx * (prf / CHIRPS_PER_FRAME)
        target_velocity = doppler_freq * (LAMBDA / 2)
        
        print(f"Target Detected -> Range: {target_range:.2f} m | Velocity: {target_velocity:.2f} m/s")

if __name__ == '__main__':
    data_queue = Queue(maxsize=512) 
    producer_process = Process(target=data_producer, args=(data_queue, 'COM3', 115200))
    producer_process.start()
    
    try:
        data_consumer(data_queue)
    except KeyboardInterrupt:
        producer_process.terminate()

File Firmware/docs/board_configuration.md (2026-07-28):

# Board Configuration Notes

The implementation keeps PCB-specific choices in `firmware/Core/Inc/fmcw_board_config.h`. The current values were merged from the CubeMX project at `C:\Users\karun\OneDrive\Desktop\FMCWRadarFirmware`.

## CubeMX Pin Choices

The active DCMI data map is:

| Signal | Pin |
| --- | --- |
| DCMI_PIXCLK | PA6 |
| DCMI_HSYNC | PA4 GPIO output, driven high by TIM9 alignment ISR |
| DCMI_HSYNC feedback | PA7 GPIO input, routed from PA4 on the PCB |
| DCMI_VSYNC | PB7 AF13, expected tied to GND |
| D0..D4 | PA9, PC7, PC8, PC9, PC11 |
| D5..D7 | PD3, PB8, PB9 |
| D8..D9 | PC10, PC12 |
| D10..D11 | PD6, PD2 |
| MUXOUT | PE5 AF3 TIM9_CH1 |

The default ULPI map is:

| Signal | Pin |
| --- | --- |
| CK | PA5 |
| STP | PC0 |
| DIR | PC2 |
| NXT | PC3 |
| D0..D2 | PA3, PB0, PB1 |
| D3..D7 | PB10, PB11, PB12, PB13, PB5 |

The RF control map is:

| Signal | Pin | Firmware behavior |
| --- | --- | --- |
| TX_STDBY | PE11 input | Active high TX-enable request |
| MIXER_EN | PD13 output | High when TX_STDBY is high |
| PA_EN | PE0 output | High when TX_STDBY is high |
| USB_RESET | PE13 output | Active-low USB3317 reset pulse at boot |
| PLL_LE | PA1 output | ADF4158 latch enable, low when idle |
| PLL_CE | PE1 output | ADF4158 chip enable, high by default |
| PLL_CLK / PLL_DATA | PE2 / PE6 | SPI4 SCK/MOSI when autoprogramming is enabled |

## Intentional CubeMX Overrides

The CubeMX-generated `main.c` is useful as a pin reference, but the acquisition firmware intentionally overrides these generated settings:

- `SYSCLK` stays at 168 MHz instead of the generated 180 MHz so TIM9's `PSC=3, CCR2=13` alignment delay remains about 309 ns.
- DCMI uses falling PIXCLK per bring-up request and active-high HSYNC because PA4 is held high after the first MUXOUT alignment event. PA7 is the routed-back HSYNC feedback check.
- PE5 is configured as `TIM9_CH1 AF3`, not a plain GPIO input, because MUXOUT must reset/capture TIM9.
- USB HS internal DMA is enabled for zero-copy bulk transfers; CubeMX generated it disabled.

## Header Correction

The HTML architecture document says the USB header struct is 64 bytes, but its sample C struct uses `reserved[2]`, which makes it 56 bytes. The implementation uses `reserved[4]` and enforces the real 64-byte header in both C and Python tests.

## ADF4158

The SPI driver and register write order are implemented, but autoprogramming is disabled by default because the final center frequency, INT/FRAC values, deviation words, and exact SPI pins are not in the HTML handoff. To enable it:

1. Set `FMCW_ENABLE_ADF4158_AUTOPROGRAM` to `1`.
2. Confirm or change the SPI/LE/CE pin macros.
3. Replace `FMCW_ADF4158_INIT_REGISTERS` with the final R7-to-R0 register words.

If the PLL is programmed externally during bring-up, leave autoprogramming disabled. TIM9 still aligns on the first MUXOUT pulse.

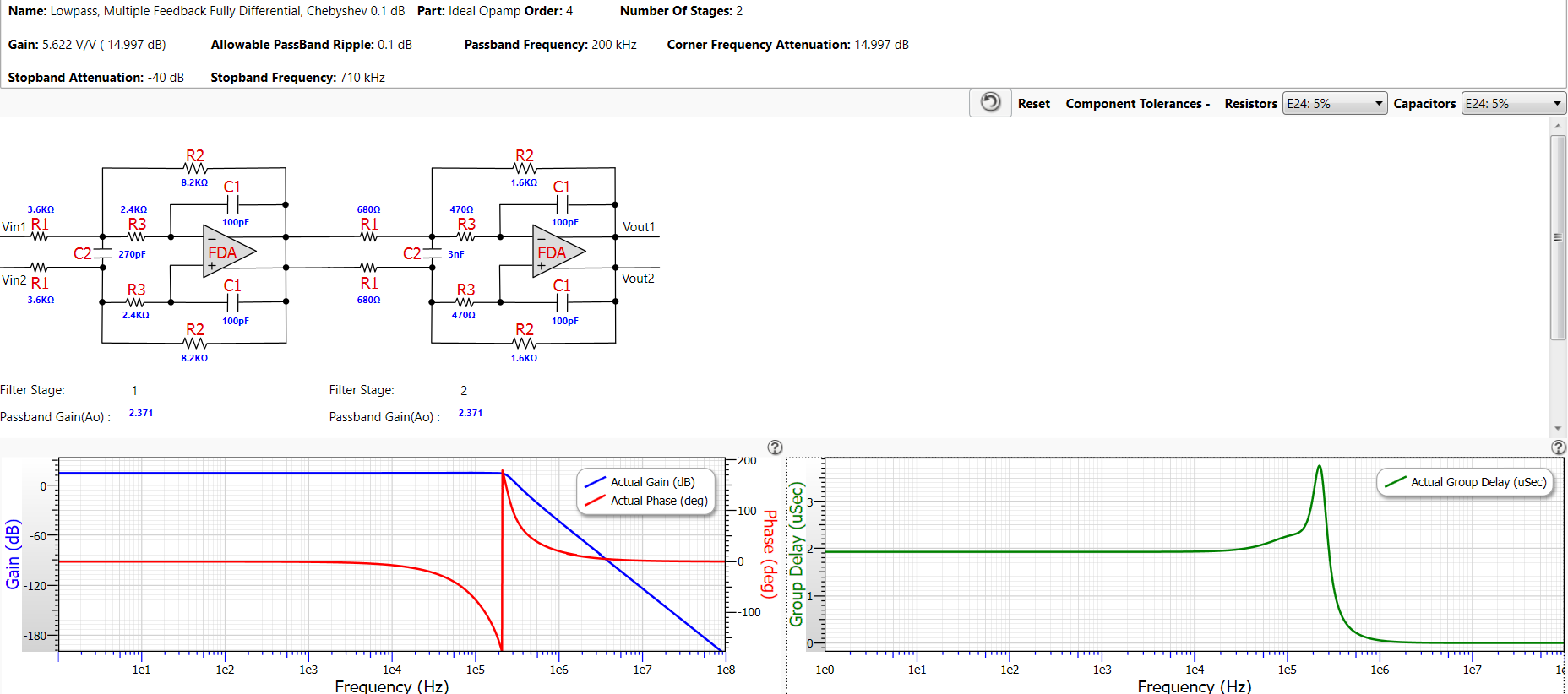
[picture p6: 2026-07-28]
Simulations/Video Filtering/images/Low_pass_filter_design.png

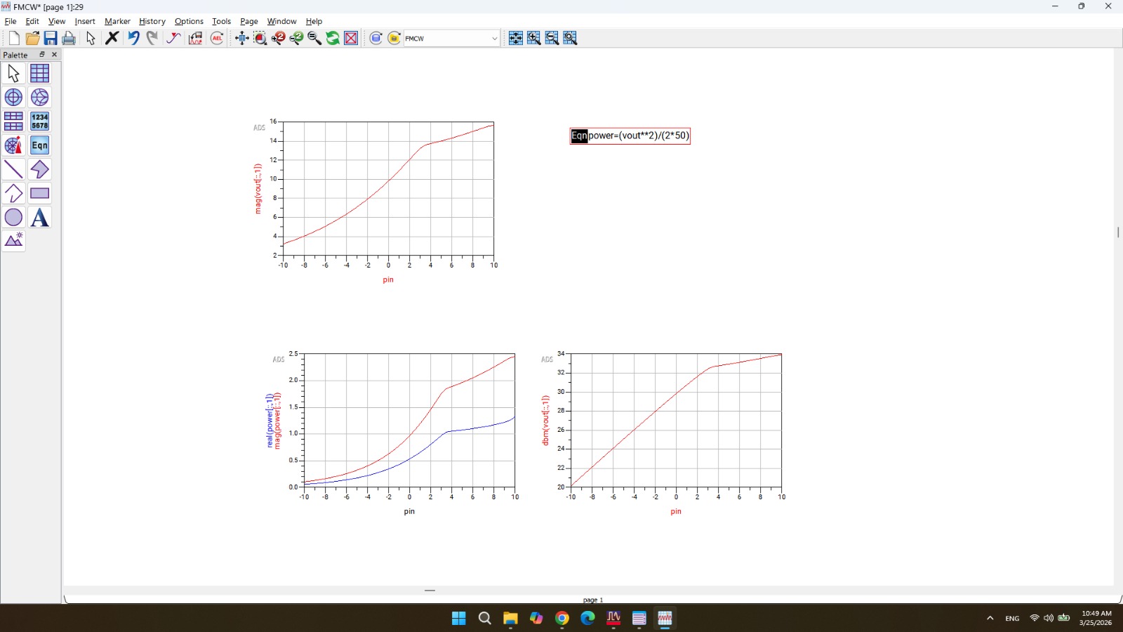
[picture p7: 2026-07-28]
Simulations/Keysight ADS Simulations/Images/Power Input vs Power Output from Cascaded badpass filter-power amplifier- splitter -antenna.jpeg

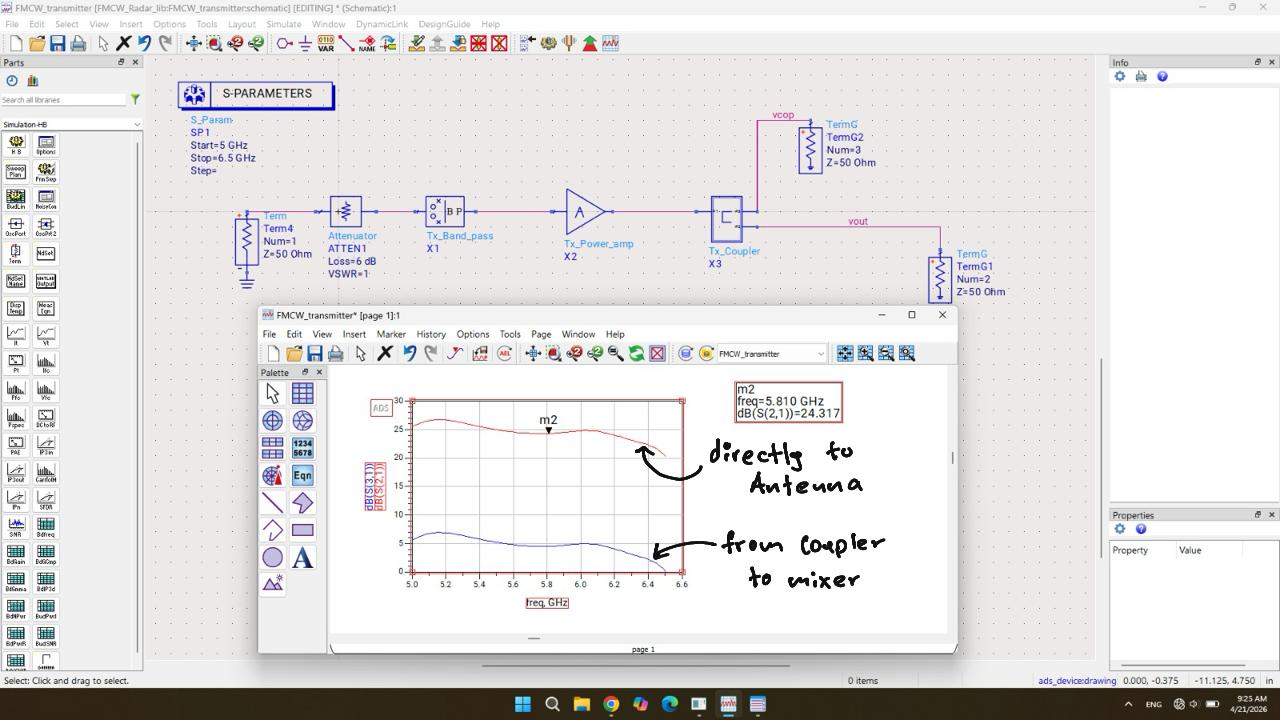
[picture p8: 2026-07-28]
Simulations/Keysight ADS Simulations/Images/Transmitter.jpeg

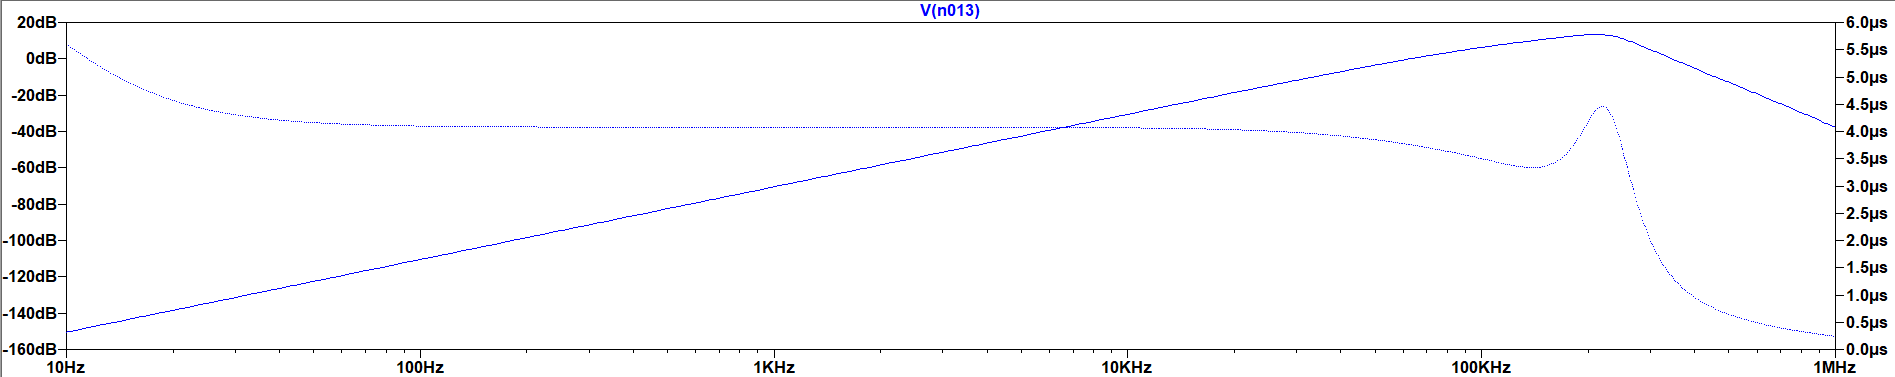
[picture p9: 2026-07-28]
Simulations/Video Filtering/images/freq_and_phase_response.png

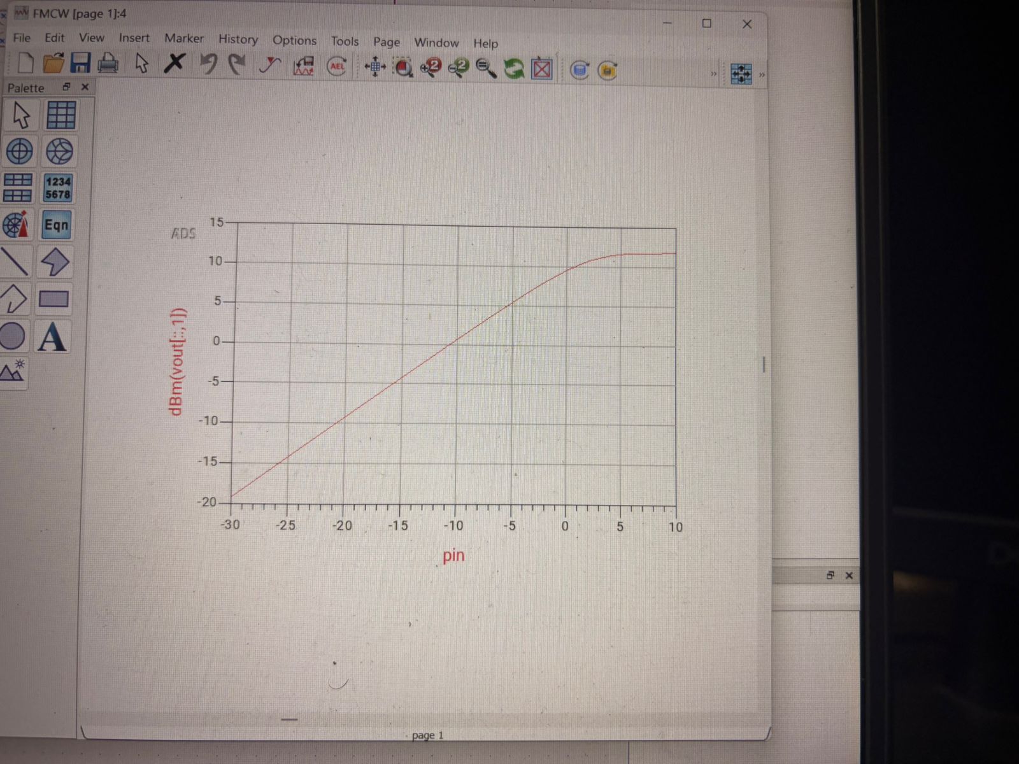
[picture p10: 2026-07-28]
Simulations/Keysight ADS Simulations/Images/LNA amplifier.jpeg

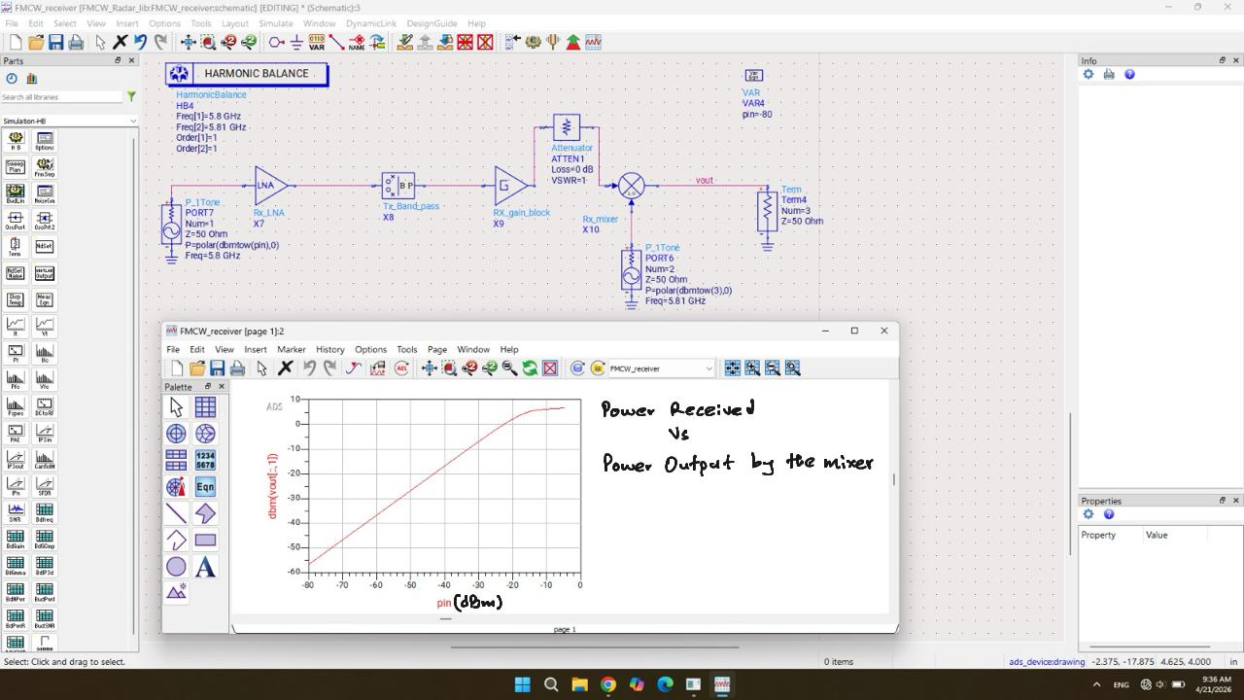
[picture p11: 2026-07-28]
Simulations/Keysight ADS Simulations/Images/Reciever.jpeg

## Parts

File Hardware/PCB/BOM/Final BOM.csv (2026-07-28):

Designator | Mouser Part No | Manufacturer Part No | Quantity
AT1 | 588-TFA16C06DBER | TFA16C06DBER | 1
AT2 | 588-TFA16C03DBER | TFA16C03DBER | 1
C1, C5 | 581-04024D106MAT2A | 04024D106MAT2A | 2
C2, C3, C48, C134, C136, C137, C138, C142, C144, C145, C146, C154, C155, C161, C162, C164, C165 | 603-CC1206KFX7R9B475 | CC1206KFX7R9BB475 | 17
C4, C8, C11 | 77-VJ0402A221KXAAC | VJ0402A221KXAAC | 3
C6, C7 | 581-04023C104KAT2A62 | 04023C104KAT2A-62 | 2
C9, C10, C12, C38, C39, C53, C54, C59, C60, C61 | 81-GJM1555C1H1R8CB1J | GJM1555C1H1R8CB01J | 10
C13, C44, C45, C57 | 581-0402X7R101KT2AT | 0402X7R101KT2AT | 4
C14, C21, C22, C24, C25, C28, C30, C32, C37, C42, C43, C46, C47, C51, C52, C58, C74, C75, C78, C79, C82, C83, C84, C86, C89, C92, C95, C101, C102, C103, C104, C105, C106, C107, C108, C109, C116, C117, C119, C120, C123, C128, C148, C167, C171, C173, C175, C177, C179, C181 | 791-0603X104K250CT | 0603X104K250CT | 50
C15, C23, C26 | 77-VJ0603A100JXBAP | VJ0603A100JXBAP | 3
C16 | 80-T491A475K020 | T491A475K020AT | 1
C17, C133, C135, C141, C143 | 77-V0603Y103KXJAC31X | VJ0603Y103KXJAC31X | 5
C18 | 80-C0603C123F4TACTU | C0603C123F4TACTU | 1
C19 | 581-0603ZC154JAT2A | 0603ZC154JAT2A | 1
C20 | 581-06033C562J | 06033C562JAT2A | 1
C27, C29, C31, C34, C41, C49, C50, C72, C73, C76, C77, C114, C115, C118, C121, C170, C172, C176, C180 | 77-VJ0603G225KXQCWBC | VJ0603G225KXQCW1BC | 19
C33, C62, C63, C70, C71 | 581-06033A101GAT2A | 06033A101GAT2A | 5
C35 | 603-CQ0402FRNPO9BN10 | CQ0402FRNPO9BN100 | 1
C36, C88, C122 | 77-VJ0402Y103JXJAC | VJ0402Y103JXJAC | 3
C40 | 581-04025A0R5BAT4A | 04025A0R5BAT4A | 1
C55, C56 | 80-C0603C823J3R | C0603C823J3RACTU | 2
C64, C67 | 77-VJ0603Y332JXBAC | VJ0603Y332JXBAC | 2
C65 | 80-C0603C271J1GAUTO | C0603C271J1GACAUTO | 1
C66 | 80-C0603C302K5G | C0603C302K5GACTU | 1
C68, C69, C80, C81, C85, C87, C91, C93, C94, C96, C110, C111, C174, C178 | 581-0603YC105KAZ2A | 0603YC105KAZ2A | 14
C90, C97, C98, C99, C100 | 581-06033D475KAT2A | 06033D475KAT2A | 5
C112, C113 | 80-C0603C475K8P7867 | C0603C475K8PAC7867 | 2
C124 | 81-GRM155R71E223KA6D | GRM155R71E223KA61D | 1
C125, C126 | 581-TAJB106K020SNJ | TAJB106K020SNJ | 2
C127, C147, C159 | 581-TAJB475K020 | TAJB475K020RNJ | 3
C129, C130, C131, C132, C149, C150, C153, C156, C157, C160, C163 | 80-C1210C106K6P | C1210C106K6PACTU | 11
C139, C151, C168 | 77-V0603Y153KXJAC31X | VJ0603Y153KXJAC31X | 3
C140, C152, C169 | 80-C1210C225J1RAUTO | C1210C225J1RACAUTO | 3
C158, C166 | 581-06035C102J4T4A | 06035C102J4T4A | 2
FB1, FB5 | 710-742792625 | 742792625 | 2
FB2, FB6, FB7, FB8, FB9 | 710-742792662 | 742792662 | 5
FB3, FB4 | 81-BLM18PG181SN1D | BLM18PG181SN1D | 2
FB10, FB11, FB12, FB13 | 710-742863122 | 742863122 | 4
FL1, FL2 | 810-DEA16555BT223C2H | DEA165550BT-2230C2-H | 2
IC1 | 772-QPA9501TR13 | QPA9501TR13 | 1
IC2 | 139-SCN-2-65 | SCN-2-65+ | 1
IC3 | 584-HMC431LP4E | HMC431LP4E | 1
IC4 | 584-ADF4158CCPZ | ADF4158CCPZ-RL7 | 1
IC5 | 595-TRF37A73IDSGR | TRF37A73IDSGR | 1
IC6 | 873-SKY65404-31 | SKY65404-31 | 1
IC7 | 584-ADL5801ACPZ-R7 | ADL5801ACPZ-R7 | 1
IC8, IC9 | 609-5400BL15B0050001 | 5400BL15B0050001E | 2
IC10, IC11 | 595-THS4561IDGKT | THS4561IDGKT | 2
IC12 | 584-LTC1420IGN#PBF | LTC1420IGN#PBF | 1
IC13 | 595-INA849DR | INA849DR | 1
IC14 | 771-AHCT2G125DP125 | 74AHCT2G125DP,125 | 1
IC15 | 511-STM32F429VET6TR | STM32F429VET6TR | 1
IC16, IC17 | 595-LMK1C1102PWR | LMK1C1102PWR | 2
IC18 | 595-SN74LVC1G04DRY2 | SN74LVC1G04DRY2 | 1
IC19 | 700-MAX17632CATE+ | MAX17632CATE+ | 1
IC20, IC21, IC22, IC23 | 700-MAX38902AATA+T | MAX38902AATA+T | 4
IC24 | 700-MAX17630CATE+ | MAX17630CATE+ | 1
IC25 | 584-ADM7172ACPZ5.0R7 | ADM7172ACPZ-5.0-R7 | 1
IC26 | 584-ADM7170ACPZ5.0R7 | ADM7170ACPZ-5.0-R7 | 1
IC27 | 584-ADP7182AUJZ5.0R7 | ADP7182AUJZ-5.0-R7 | 1
IC28 | 700-MAX17579ATC+ | MAX17579ATC+ | 1
IC29 | 886-USB3317C-CP-TR | USB3317C-CP-TR | 1
J1, J2 | 710-60312202114514 | 60312202114514 | 2
J3 |  | PZ254V-11-04P | 1
J4 | 200-HTSW10307GD | HTSW-103-07-G-D | 1
J5 | 710-694106301002 | 694106301002 | 1
J6 | 640-USB4940-00-A | USB4940-00-A | 1
L1 | 81-LQP03HQ0N6C02D | LQP03HQ0N6C02D | 1
L2 | 81-LQW15AN9N9J80D | LQW15AN9N9J80D | 1
L3 | 70-IHLP5050FDR7R8M5A | IHLP5050FDER7R8M5A | 1
L4 | 70-IHLP5050FDR4R7M5A | IHLP5050FDER4R7M5A | 1
L5 | 810-SPM7054VC-6R8M-D | SPM7054VC-6R8M-D | 1
LED1 | 859-LTST-C171KRKT | LTST-C171KRKT | 1
P1 | 620-X4C60J1-20G | X4C60J1-20G | 1
R1 | 71-CRCW0402J-27-E3 | CRCW040227R0JNED | 1
R2, R3 | 667-ERJ-PA2J2R0X | ERJ-PA2J2R0X | 2
R4, R12, R13, R28, R29, R31 | 603-RT0402BRE0749R9L | RT0402BRE0749R9L | 6
R5 | 667-ERA-2VPB2742X | ERA-2VPB2742X | 1
R6 | 71-CRCW040245R3FKEDC | CRCW040245R3FKEDC | 1
R7 | 603-RC0603FR-10200RL | RC0603FR-10200RL | 1
R8, R60, R61 | 71-CRCW0402-5.1K-E3 | CRCW04025K10FKED | 3
R9, R11 | 710-560112116009 | 560112116009 | 2
R10 | 71-CRCW0402J-27 | CRCW040227R0JNTD | 1
R14 | 603-RT0603BRD07665RL | RT0603BRD07665RL | 1
R15, R26 | 652-CR0603FX-8201ELF | CR0603-FX-8201ELF | 2
R16, R27 | 603-RT0603BRE071K6L | RT0603BRE071K6L | 2
R17, R22 | 71-CRCW0603-3.6K | CRCW06033K60FKTA | 2
R18, R23 | 603-RC0603FR-7W2K4L | RC0603FR-7W2K4L | 2
R19, R24 | 652-CR0603JW-681ELF | CR0603-JW-681ELF | 2
R20, R25 | 652-CR0603JW-471ELF | CR0603-JW-471ELF | 2
R21 | 652-CR0603JW-361ELF | CR0603-JW-361ELF | 1
R30 | 603-RT0603BRD0727RL | RT0603BRD0727RL | 1
R32 | 652-CR0603-JW-152ELF | CR0603-JW-152ELF | 1
R33, R34 | 603-AC0402JR-7D0RL | AC0402JR-7D0RL | 2
R35, R36, R40, R41 | 603-AT0603BRD0740KL | AT0603BRD0740KL | 4
R37 | 71-TNPW06031K00FHTA | TNPW06031K00FHTA | 1
R38, R39 | 652-CR0603JW-474ELF | CR0603-JW-474ELF | 2
R42, R47 | 652-CR0603FX-7502ELF | CR0603-FX-7502ELF | 2
R43, R48, R52 | 603-AF0603FR-073M3L | AF0603FR-073M3L | 3
R44 | 603-RT0603BRE0713K7L | RT0603BRE0713K7L | 1
R45, R50, R54 | 71-CRCW0603511KFKEAC | CRCW0603511KFKEAC | 3
R46 | 603-AF0603FR-0733K2L | AF0603FR-0733K2L | 1
R49 | 652-CR0603FX-2102ELF | CR0603-FX-2102ELF | 1
R51 | 603-RT0603DRE0719K6L | RT0603DRE0719K6L | 1
R53, R59 | 279-RN73C1J8K06BTDF | RN73C1J8K06BTDF | 2
R55 | 603-RT0603DRE0743K2L | RT0603DRE0743K2L | 1
R56 | 71-CRCW0603-44.2K | CRCW060344K2FKTA | 1
R57 | 652-CRT0603FY1002ELF | CRT0603-FY-1002ELF | 1
R58 | 71-CRCW060339R0FKEAC | CRCW060339R0FKEAC | 1
S1, S2, S3 | 113-SS3NPMSVT/R | SS3NP-MS-V-T/R | 3
Y1 | 732-TG252S2MCGNNM3 | TG2520SMN 20.0000M-MCGNNM3 | 1

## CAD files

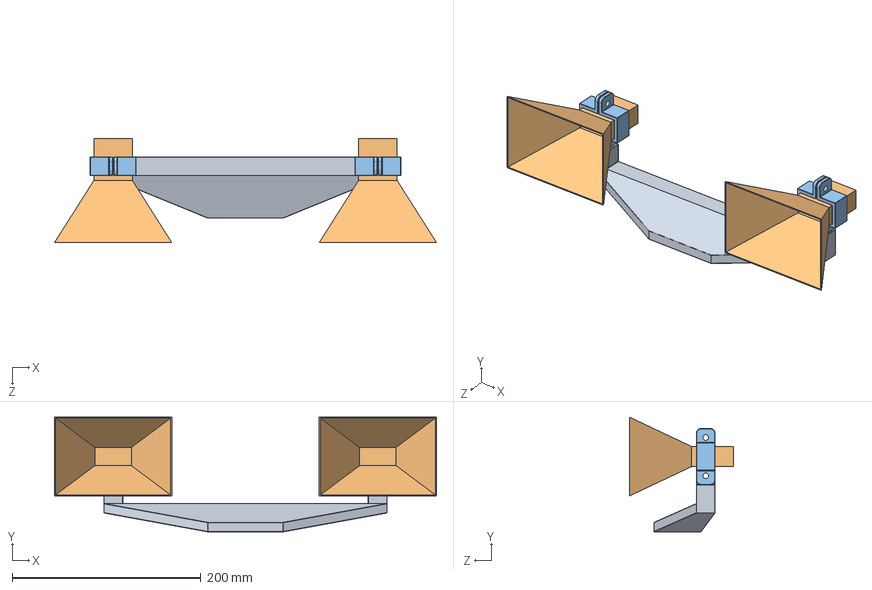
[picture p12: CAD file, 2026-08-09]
CAD/Antenna_Mount/STEP/Final_Assy.SLDASM
405.2 x 121.7 x 110.4 mm
Antenna_Mount_Crossbar
Horn_Antenna_15dBi x 2
Waveguide_Mount_Clip x 4

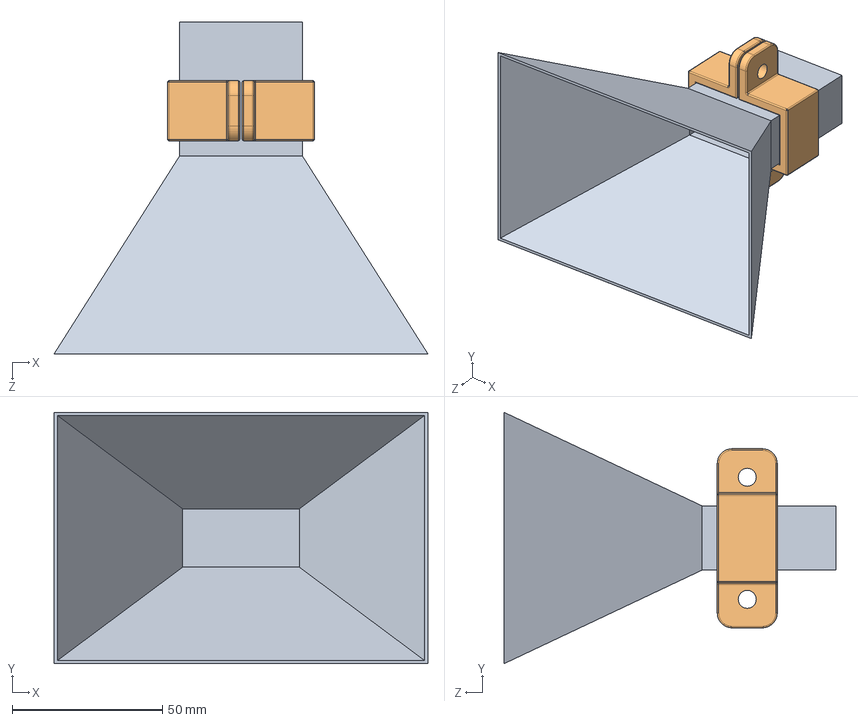
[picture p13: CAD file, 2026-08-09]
CAD/Antenna_Mount/Horn_Antenna_Single_Assy.SLDASM
124.4 x 83.6 x 110.4 mm
Horn_Antenna_15dBi
Waveguide_Mount_Clip x 2

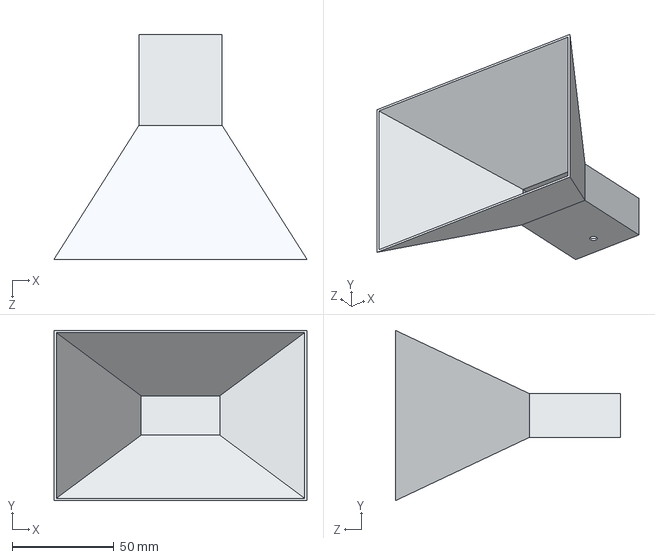
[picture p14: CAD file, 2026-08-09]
CAD/Antenna/STEP/Horn_Antenna_15dBi.STEP
124.4 x 83.6 x 110.4 mm

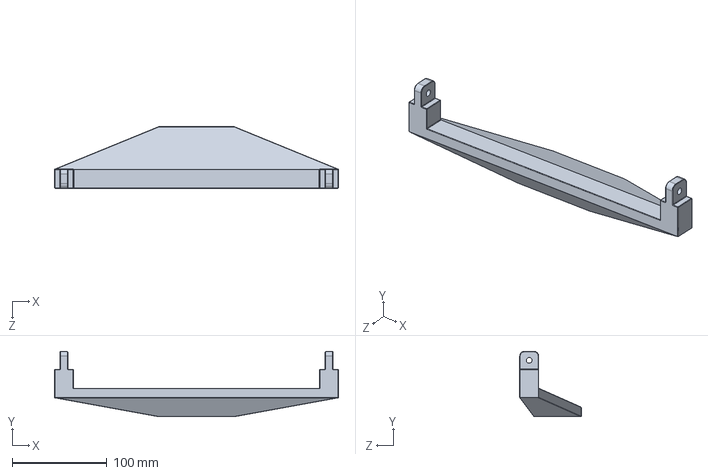
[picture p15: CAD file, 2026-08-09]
CAD/Antenna_Mount/Antenna_Mount_Crossbar.SLDPRT
300.0 x 69.0 x 65.0 mm

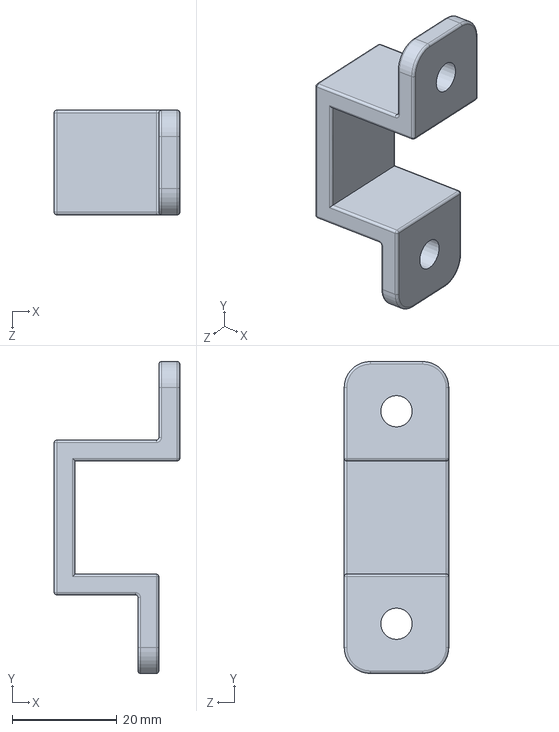
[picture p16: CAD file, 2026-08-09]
CAD/Antenna_Mount/Waveguide_Mount_Clip.SLDPRT
24.0 x 59.6 x 20.0 mm

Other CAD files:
FinalEnclosure.SLDASM
CAD/Antenna_Mount/Horn_Antenna_15dBi.SLDPRT
CAD/Antenna/Horn_Antenna_15dBi.SLDPRT
CAD/Antenna_Mount/Final_Assy.SLDASM

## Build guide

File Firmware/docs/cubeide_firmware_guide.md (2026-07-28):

---
title: "FMCW Radar Firmware Guide"
subtitle: "CubeIDE build, flash, and source-code map"
author: "Generated for the STM32F429 FMCW radar firmware"
date: "2026-05-19"
geometry: margin=0.8in
fontsize: 10pt
---

# 1. What You Have

This firmware is for an STM32F429VETx board that captures FMCW radar ADC samples and streams them to a PC over USB High Speed.

The important hardware chain is:

```text
ADF4158 ramp + RF chain
        -> LTC1420 12-bit ADC
        -> STM32 DCMI peripheral
        -> DMA2 Stream 1 double-buffer capture
        -> SRAM frame ring
        -> USB OTG HS bulk IN endpoint
        -> Host PC
```

The CubeMX project at `C:\Users\karun\OneDrive\Desktop\FMCWRadarFirmware` was used as the pin map source. The actual firmware you should build is in:

```text
C:\Users\karun\Downloads\FMCWCode\firmware
```

# 2. Can You Use STM32CubeIDE?

Yes. You can open the `firmware` folder in CubeIDE.

This repo is not a normal CubeMX-generated project where CubeMX owns `main.c`. It is a hand-written firmware project that uses STM32 HAL/CMSIS, plus a small `Makefile` wrapper so CubeIDE can build it.

Do not press "Generate Code" from CubeMX into this folder. CubeMX would overwrite important architecture choices.

The important CubeMX choices that were intentionally overridden are:

| CubeMX generated | Firmware uses | Why |
| --- | --- | --- |
| 180 MHz SYSCLK | 168 MHz SYSCLK | Keeps TIM9 alignment math simple and matched to the architecture |
| DCMI HSYNC low | DCMI HSYNC high | PA4 is held high after alignment |
| DCMI falling PIXCLK | Falling PIXCLK | Updated per board bring-up request |
| PE5 as GPIO input | PE5 as TIM9_CH1 AF3 | Needed to align capture to ADF4158 MUXOUT |
| USB DMA disabled | USB DMA enabled | Needed for high-speed streaming |

# 3. The File You Build and Flash

Build from:

```text
C:\Users\karun\Downloads\FMCWCode\firmware
```

CubeIDE or `make` will produce:

```text
C:\Users\karun\Downloads\FMCWCode\build\firmware-cubeide\fmcw_radar_f429.elf
C:\Users\karun\Downloads\FMCWCode\build\firmware-cubeide\fmcw_radar_f429.bin
C:\Users\karun\Downloads\FMCWCode\build\firmware-cubeide\fmcw_radar_f429.hex
```

For CubeIDE debug/flash, use the `.elf` file:

```text
build\firmware-cubeide\fmcw_radar_f429.elf
```

The ELF contains both the program and debug symbols, so CubeIDE can step through source code if you create a debug configuration.

# 4. CubeIDE Build Steps

## Option A: Build After Importing the Firmware Folder

1. Open STM32CubeIDE.
2. Use `File -> Import`.
3. Choose an existing C/C++ project or Makefile project.
4. Select:

```text
C:\Users\karun\Downloads\FMCWCode\firmware
```

5. Build the project.

The `firmware\Makefile` runs CMake/Ninja behind the scenes and writes output to `build\firmware-cubeide`.

## Option B: Build From CubeIDE Terminal

In a CubeIDE terminal, run:

```powershell
cd C:\Users\karun\Downloads\FMCWCode\firmware
make all
```

To flash with ST-LINK from the wrapper:

```powershell
make flash
```

The flash target uses STM32CubeProgrammer CLI and writes the ELF through SWD.

# 5. Folder Map

| Path | Purpose |
| --- | --- |
| `firmware\Makefile` | CubeIDE-friendly wrapper. Runs CMake configure/build and optional flash. |
| `firmware\CMakeLists.txt` | The real firmware build recipe: source files, HAL files, include paths, linker script. |
| `firmware\cmake\arm-none-eabi-gcc.cmake` | CMake toolchain file for ARM GCC. |
| `firmware\linker\STM32F429VETx_FLASH.ld` | Linker memory map. Places code in Flash and buffers in SRAM. |
| `firmware\startup\startup_stm32f429xx.s` | Reset vector and interrupt vector table startup code. |
| `firmware\Core\Inc` | Firmware header files. |
| `firmware\Core\Src` | Firmware C source files. |
| `host` | Python PC-side capture/parser tools. |
| `tests` | Host protocol tests. |
| `docs` | Bring-up and board configuration notes. |

# 6. Important Header Files

| File | What it contains |
| --- | --- |
| `Core\Inc\main.h` | Minimal global include for STM32 HAL. |
| `Core\Inc\fmcw_board_config.h` | Board-specific pins and build-time options. Start here when checking hardware mapping. |
| `Core\Inc\fmcw_protocol.h` | USB frame format: magic number, header size, payload size, sample rate, flags. |
| `Core\Inc\fmcw_capture.h` | Capture buffer sizes and capture-state function declarations. |
| `Core\Inc\fmcw_hardware.h` | Hardware initialization and TX standby function declarations. |
| `Core\Inc\fmcw_adf4158.h` | Optional ADF4158 SPI programming API. |
| `Core\Inc\usb_stream.h` | USB streaming API. |
| `Core\Inc\usbd_vendor_stream.h` | Vendor-specific USB class declarations. |
| `Core\Inc\stm32f4xx_hal_conf.h` | Enables the HAL modules used by this firmware. |

# 7. Important Source Files

## `Core\Src\main.c`

This is the application entry point.

It does this in order:

1. Calls `HAL_Init()`.
2. Configures clocks with `fmcw_clock_config()`.
3. Starts the microsecond timestamp system.
4. Initializes capture state.
5. Configures GPIO pins.
6. Resets the USB3317 PHY.
7. Initializes DCMI, DMA, USB, TIM9, and interrupts.
8. Optionally waits for USB enumeration.
9. Optionally programs the ADF4158.
10. Starts TIM9 alignment.
11. Runs the forever loop.

The forever loop calls:

```c
fmcw_tx_service();
usb_stream_poll();
fmcw_capture_watchdog_poll();
```

So the main loop keeps TX enable updated, feeds USB frames to the host, and checks that ADF4158 MUXOUT pulses are still arriving.

## `Core\Src\fmcw_hardware.c`

This file owns direct hardware setup.

Important functions:

| Function | What it does |
| --- | --- |
| `fmcw_clock_config()` | Sets HSE bypass, PLL, bus clocks, and MCO1 = HSE / 2 = 10 MHz. |
| `fmcw_gpio_init()` | Applies the CubeMX pin map, sets safe output levels, and samples TX_STDBY. |
| `fmcw_usb_phy_reset()` | Pulses USB3317 reset on PE13. |
| `fmcw_tx_service()` | Reads TX_STDBY on PE11. If high, sets MIXER_EN PD13 and PA_EN PE0 high. |
| `fmcw_dcmi_init()` | Configures DCMI for 12-bit continuous capture. |
| `fmcw_dma2_stream1_init()` | Configures DMA2 Stream 1 Channel 1 double-buffer capture. |
| `fmcw_tim9_init()` | Configures TIM9 to watch ADF4158 MUXOUT on PE5. |
| `fmcw_nvic_init()` | Enables DMA, DCMI, USB, and TIM9 interrupts. |

## `Core\Src\fmcw_capture.c`

This file owns the capture buffer ring.

The firmware has four frame buffers. DMA writes into two of them using hardware double-buffer mode. The other two are used as spare/USB buffers.

When DMA finishes one slope:

1. The DMA interrupt calls `fmcw_capture_dma_tc_isr()`.
2. The completed buffer gets a 64-byte frame header.
3. The buffer is queued for USB.
4. A free buffer is attached back to DMA.
5. The slope sequence number increments.

## `Core\Src\stm32f4xx_it.c`

This file contains interrupt handlers.

| Interrupt | What happens |
| --- | --- |
| `DMA2_Stream1_IRQHandler` | One slope buffer has completed, or DMA fault occurred. |
| `DCMI_IRQHandler` | DCMI overrun/sync errors become frame flags. |
| `TIM1_BRK_TIM9_IRQHandler` | First MUXOUT starts aligned capture; later MUXOUT edges update heartbeat count. |
| `OTG_HS_IRQHandler` | USB HAL interrupt handler. |
| `SysTick_Handler` | HAL tick. |

## `Core\Src\usb_stream.c`

This file moves completed frame buffers to USB.

It checks whether USB is configured and whether EP1 IN is idle. If a frame is ready, it starts one bulk IN transfer. When USB reports completion, the buffer is returned to the free pool.

## `Core\Src\usbd_vendor_stream.c`

This is the vendor-specific USB class.

It creates one interface and one bulk IN endpoint:

```text
Endpoint: 0x81
Direction: IN, device to host
High-speed packet size: 512 bytes
```

## `Core\Src\fmcw_frame.c`

This writes the 64-byte frame header before each ADC payload.

The host uses the header to read:

- frame magic
- protocol version
- slope sequence
- triangle sequence
- slope direction id
- error flags
- sample rate
- timestamp
- MUXOUT count

## `Core\Src\fmcw_adf4158.c`

This is optional ADF4158 SPI programming support.

Right now autoprogramming is disabled:

```c
#define FMCW_ENABLE_ADF4158_AUTOPROGRAM 0u
```

That is intentional because the real ADF4158 register values for center frequency and ramp settings must be filled in first.

# 8. Board Pin Summary

## TX Control

| Signal | Pin | Behavior |
| --- | --- | --- |
| TX_STDBY | PE11 input | Active high TX-enable request |
| MIXER_EN | PD13 output | High when TX_STDBY is high |
| PA_EN | PE0 output | High when TX_STDBY is high |

If TX_STDBY is normally high on your board, the firmware starts transmitting after GPIO initialization.

## ADF4158

| Signal | Pin |
| --- | --- |
| PLL_CLK / SPI4_SCK | PE2 |
| PLL_DATA / SPI4_MOSI | PE6 |
| PLL_LE | PA1 |
| PLL_CE | PE1 |
| PLL_MUXOUT | PE5 / TIM9_CH1 |

## DCMI ADC Bus

| Signal | Pin |
| --- | --- |
| D0 | PA9 |
| D1 | PC7 |
| D2 | PC8 |
| D3 | PC9 |
| D4 | PC11 |
| D5 | PD3 |
| D6 | PB8 |
| D7 | PB9 |
| D8 | PC10 |
| D9 | PC12 |
| D10 | PD6 |
| D11 | PD2 |
| PIXCLK | PA6 |
| HSYNC | PA4, driven by firmware |
| HSYNC feedback | PA7, routed from PA4 on the PCB |
| VSYNC | PB7, expected tied low |

# 9. How Capture Starts

At boot, DCMI is configured but not capturing yet.

TIM9 watches MUXOUT from the ADF4158 on PE5. On the first MUXOUT edge, TIM9 waits a small delay for the LTC1420 pipeline offset. Then the TIM9 interrupt drives PA4 HSYNC high, checks the routed PA7 feedback signal, and sets the DCMI capture bit.

After that, HSYNC stays high. The firmware does not toggle HSYNC every slope.

One DMA buffer equals one slope:

```text
10,000 samples per slope
2 samples packed per 32-bit DCMI word
5,000 DMA words per slope
20,000 payload bytes per slope
64 header bytes per USB frame
20,064 total bytes per frame
```

# 10. What To Check On The Board

Start with these checks:

1. PA8 should output 10 MHz MCO1.
2. USB3317 should have its 26 MHz reference and ULPI 60 MHz clock.
3. USB should enumerate as a vendor-specific device.
4. PE11 TX_STDBY high should make PD13 MIXER_EN and PE0 PA_EN go high.
5. PE5 should receive ADF4158 MUXOUT pulses every slope.
6. PA4 HSYNC should go high after the first MUXOUT alignment event.
7. PA7 should also read high because it is the routed-back HSYNC feedback signal.
8. Host capture should receive frames with valid magic and increasing slope sequence.

# 11. Common Beginner Mistakes

Do not edit generated files in the CubeMX folder and expect this firmware to change. The active firmware is under `C:\Users\karun\Downloads\FMCWCode\firmware`.

Do not regenerate CubeMX code into this folder unless you are ready to manually re-merge the architecture.

Do not flash the CubeMX-generated empty application from `C:\Users\karun\OneDrive\Desktop\FMCWRadarFirmware`. It configures pins, but it does not implement the radar pipeline.

Do not flash the `.bin` from an arbitrary address unless you know the flash base address. In CubeIDE, use the `.elf`.

# 12. Quick Reference

Build:

```powershell
cd C:\Users\karun\Downloads\FMCWCode\firmware
make all
```

Flash through ST-LINK:

```powershell
make flash
```

ELF to use in CubeIDE debug configuration:

```text
C:\Users\karun\Downloads\FMCWCode\build\firmware-cubeide\fmcw_radar_f429.elf
```

Most important source files to read first:

```text
firmware\Core\Src\main.c
firmware\Core\Src\fmcw_hardware.c
firmware\Core\Src\fmcw_capture.c
firmware\Core\Src\stm32f4xx_it.c
firmware\Core\Inc\fmcw_board_config.h
```

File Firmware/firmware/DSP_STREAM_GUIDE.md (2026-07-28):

# FMCW Stream DSP Guide

This firmware streams one USB frame per FMCW slope. The PC-side DSP should
parse fixed-size frames, verify sequence continuity, decode 12-bit ADC samples,
then run range/Doppler processing.

## Current Stream

- USB VID/PID: `1209:4158`
- Bulk IN endpoint: `0x81`
- Start stream command: vendor control request `bmRequestType=0x40`, `bRequest=0x30`
- Frame size: `20480` bytes
- Header size: `64` bytes
- ADC payload: `20000` bytes
- Padding: `416` bytes, ignore
- ADC sample rate: `10 MHz`
- Samples per slope: `10000`
- DCMI words per slope: `5000`
- ADC format: 12-bit two's-complement, 1 LSB = 1 mV

## Header

Little-endian Python format:

```python
HEADER = struct.Struct("<IHHIIIHHIIHHIIIIIII")
```

| Field | Meaning |
|---|---|
| `magic` | Must be `0x52444152` |
| `version` | Currently `1` |
| `header_len` | Must be `64` |
| `frame_len` | Must be `20480` |
| `slope_seq` | Monotonic slope counter |
| `triangle_seq` | `slope_seq / 2` |
| `slope_id` | Alternates `0, 1, 0, 1...` |
| `flags` | Stream health flags |
| `sample_rate_hz` | `10000000` |
| `samples_per_slope` | `10000` |
| `adc_bits` | `12` |
| `words_per_slope` | `5000` |
| `timestamp_us` | Coarse firmware timestamp |
| `muxout_count` | ADF4158 MUXOUT edge count |
| `dropped_frames` | Cumulative firmware drops |
| `dcmi_risr` | DCMI status snapshot |
| `dma_lisr` | DMA status snapshot |

Flags:

```text
0x0001  dropped frame occurred
0x0002  USB/host was late returning buffers
0x0004  MUXOUT alignment timeout
0x0008  DMA error
0x0010  DCMI error
0x0020  DCMI overrun
```

## ADC Decode

Each 32-bit payload word contains two ADC samples:

```python
word = uint32_little_endian
sample0_raw = word & 0x0FFF
sample1_raw = (word >> 16) & 0x0FFF
```

Sign extension:

```python
def sign_extend_12(x):
    x &= 0x0FFF
    return x - 0x1000 if x & 0x0800 else x
```

Voltage:

```python
sample_mV = sign_extend_12(raw)
sample_V = sample_mV / 1000.0
```

## Current RF Preset

Normal firmware preset:

- One-way chirp time: `1.000 ms`
- Triangle period: `2.000 ms`
- Start frequency: `5.700000000 GHz`
- Stop frequency: `5.900271606 GHz`
- Center frequency: `5.800135803 GHz`
- One-way bandwidth: `200.271606 MHz`
- Chirp slope: `200.271606 GHz/s`

Range conversion from beat frequency:

```python
range_m = c * beat_freq_hz / (2 * chirp_slope_hz_per_s)
```

With the current preset:

```python
chirp_slope_hz_per_s = 200.271606e6 / 1.0e-3
```

## Recommended DSP Workflow

1. **Frame validation**
   - Check `magic`, `version`, `header_len`, and `frame_len`.
   - Check `slope_seq` increments by 1. If it jumps, mark missing slopes.
   - Check `flags == 0` for clean data.

2. **ADC decode**
   - Decode 5000 words into 10000 signed samples.
   - Convert to volts if needed.
   - Remove DC offset per chirp.

3. **Range FFT per chirp**
   - Apply a Hann or Blackman window.
   - Use `rfft` on the real ADC samples.
   - Convert FFT bin frequency to range using chirp slope.
   - Keep only useful range bins.

4. **Slope handling**
   - `slope_id` alternates between the two halves of the triangle.
   - Initially process only one `slope_id` for a stable range-time plot.
   - Once verified, compare both slope phases for range/Doppler refinement.

5. **Range-time visualization**
   - Stack range FFT magnitudes over time.
   - This shows stationary targets as horizontal bright bands.

6. **Doppler processing**
   - For each range bin, collect complex or magnitude values across many chirps.
   - Run a slow-time FFT across chirps.
   - If using only real ADC magnitude spectra, Doppler sign/quality is limited.
   - For better Doppler, preserve complex FFT bins from each chirp before taking magnitude.

7. **Calibration**
   - Measure known target distances.
   - Verify slope polarity for `slope_id=0` and `slope_id=1`.
   - Estimate/remove static clutter from range bins.
   - Apply range-bin scaling and any front-end gain calibration.

## Visualization Tool

Install dependencies:

```powershell
python -m pip install pyusb libusb-package numpy matplotlib
```

Run:

```powershell
python .\tools\fmcw_dsp_view.py
```

Useful options:

```powershell
python .\tools\fmcw_dsp_view.py --slope-id 0 --max-range-m 100 --process-every 10
python .\tools\fmcw_dsp_view.py --slope-id all --max-range-m 200
python .\tools\fmcw_dsp_view.py --save-raw capture.bin
```

The live viewer is intentionally decimated. It is for visual bring-up, not
lossless DSP validation.

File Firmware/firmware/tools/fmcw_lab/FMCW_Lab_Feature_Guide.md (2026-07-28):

# FMCW Lab Feature Guide

Project: STM32 FMCW radar PC-side processing tools  
Application folder: `tools/fmcw_lab`  
Firmware stream used: existing USB HS stream, VID/PID `1209:4158`, bulk IN endpoint `0x81`

## 1. What Was Built

The `tools/fmcw_lab` application is a PC-side radar workbench. It does not change
the STM32 firmware. It connects to the radar over the same USB stream that was
already tested with `fmcw_stream_read.py`, decodes each streamed ADC slope frame,
and runs the radar DSP on the PC.

The implemented modules are:

| File | Purpose |
|---|---|
| `usb_stream.py` | Opens the USB HS device, starts streaming, parses frame headers, and decodes 12-bit ADC samples. |
| `dsp.py` | Range FFT, range-Doppler, peak range detection, phase tracking, breathing/heartbeat analysis. |
| `sar.py` | Experimental SAR aperture FFT and monostatic backprojection helpers. |
| `app.py` | PyQtGraph GUI with connect/disconnect control and live visualizations. |
| `run.py` | Launch script for the app. |

Run:

```powershell
python .\tools\fmcw_lab\run.py
```

Dependencies:

```powershell
python -m pip install pyusb libusb-package numpy pyqtgraph PyQt6
```

Only one PC program can own the USB interface at a time. Close other readers
before opening this app.

## 2. Input Data Format

The current firmware sends one USB frame per captured DCMI/DMA slope frame.

Important constants from `Core/Inc/fmcw_stream.h`:

| Field | Value |
|---|---:|
| USB frame size | `20480` bytes |
| Header size | `64` bytes |
| ADC payload | `5000` 32-bit DCMI words |
| ADC samples per frame | `10000` samples |
| ADC sample rate | `10 MHz` |
| ADC format | 12-bit two's-complement |

Each 32-bit DCMI word contains two ADC samples:

```text
sample0 = word[11:0]
sample1 = word[27:16]
```

The PC app sign-extends each 12-bit value. Since the LTC1420 was treated as
4.096 V reference bipolar output, the current convention is:

```text
1 ADC code ~= 1 mV
full-scale input range ~= +/-2.048 V
```

## 3. Range Measurement

### How It Is Produced

For each selected chirp/slope frame:

1. Decode `10000` ADC samples.
2. Remove the per-chirp mean to suppress DC/leakage.
3. Apply a Hann window.
4. Run a real FFT.
5. Convert FFT beat frequency to range.

The range equation is:

```text
range_m = c * beat_frequency_hz / (2 * chirp_slope_hz_per_s)
chirp_slope_hz_per_s = bandwidth_hz / chirp_time_s
```

For the normal preset:

```text
bandwidth = 200.271606 MHz
chirp time = 1.000 ms
slope = 200.271606 GHz/s
```

Range resolution is approximately:

```text
delta_R = c / (2 * bandwidth)
```

For 200.271606 MHz, this is about `0.75 m`.

### Suitable Chirp Settings

| Goal | Recommended Chirp |
|---|---|
| General range bring-up | 1 ms, 200 MHz |
| Better range resolution | Increase bandwidth |
| Lower noise floor per FFT bin | Longer chirp, if hardware timing supports it |
| Very close-range debugging | 1 ms is fine; reduce displayed range window |
| Fast motion experiments | Shorter chirp can help, but must match firmware capture length |

For range measurement, bandwidth mainly sets range resolution. Chirp time mainly
sets beat-frequency scaling, FFT bin width, and how much time you integrate per
range profile.

## 4. Range-Doppler Processing

### How It Is Produced

The app processes one slope direction at a time, usually `slope_id = 0`.

1. Run range FFT for many consecutive selected-slope chirps.
2. Keep the complex range FFT values, not just magnitudes.
3. Stack them into a CPI.
4. Optionally subtract the slow-time mean to suppress stationary clutter.
5. Apply a slow-time window.
6. Run FFT across chirps for each range bin.
7. Display Doppler bins versus range.

Velocity is estimated from Doppler frequency:

```text
velocity_m_s = doppler_hz * wavelength_m / 2
```

At 5.8 GHz:

```text
wavelength ~= 51.7 mm
```

### Suitable Chirp Settings

| Goal | Recommended Chirp |
|---|---|
| Slow human/body motion | 1 ms chirp, CPI 128-512 selected slopes |
| Faster targets | Shorter chirp or shorter triangle period |
| Better Doppler resolution | More chirps per CPI |
| Less latency | Fewer chirps per CPI |

The tradeoff is simple:

```text
Doppler resolution improves with longer CPI time.
Maximum unambiguous velocity improves with faster chirp repetition.
```

Because the firmware alternates slope directions, processing only one slope means
the slow-time spacing is approximately one triangle period.

## 5. Range Waterfall

### How It Is Produced

The waterfall is an integrated range profile history.

1. Collect recent complex range FFT frames.
2. Average power across a short CPI.
3. Convert to dB.
4. Append each integrated profile as a new row.

This is useful for seeing targets moving over range without needing to interpret
Doppler velocity.

### Suitable Chirp Settings

Use the same settings as ordinary range measurement. For human motion and indoor
debugging, the normal 1 ms / 200 MHz chirp is a good starting point.

## 6. Phase-Based Micromotion

### How It Is Produced

Micromotion uses the phase of one complex range FFT bin. It does not use raw ADC
time-domain samples directly.

Pipeline:

```text
ADC chirp -> range FFT -> choose target range bin -> complex phase
-> unwrap phase over slow time -> convert phase to displacement
```

The displacement equation is:

```text
displacement_m = unwrapped_phase_rad * wavelength_m / (4*pi)
```

This is why the app needs a stable range bin. If the selected bin jumps between
clutter and the body, the phase becomes meaningless.

### Suitable Chirp Settings

| Goal | Recommended Chirp |
|---|---|
| Breathing/micromotion | 1 ms, 200 MHz |
| Better target isolation | Higher bandwidth |
| Better phase SNR | Stable chirp, coherent PLL, longer observation time |
| Fast vibration | Faster chirp repetition helps |

For phase sensing, chirp coherence and range-bin stability matter more than raw
bandwidth. Bandwidth still helps isolate the target from nearby clutter.

## 7. Breathing Monitoring

### How It Is Produced

Breathing is extracted from the micromotion displacement trace.

1. Track one target range bin.
2. Convert phase to displacement.
3. Remove slow drift.
4. Analyze the low-frequency band:

```text
breathing band = 0.10 Hz to 0.70 Hz
               = 6 to 42 breaths/min
```

The app estimates the strongest spectral peak in this band and reports breaths
per minute.

### Suitable Chirp Settings

| Goal | Recommended Chirp |
|---|---|
| First breathing demo | 1 ms, 200 MHz, one slope direction |
| Stable display | Process decimated slow-time stream, about 20-100 Hz |
| Close-range chest tracking | Set target range manually if auto-target locks to clutter |

Breathing is slow. You do not need to process every chirp for the breathing
rate. The app decimates the slow-time phase stream by default.

## 8. Heartbeat Monitoring

### How It Is Produced

Heartbeat uses the same phase-derived displacement trace, but analyzes a higher
frequency band:

```text
heartbeat band = 0.80 Hz to 2.50 Hz
               = 48 to 150 beats/min
```

Heartbeat is much weaker than breathing. It is easily hidden by body motion,
breathing harmonics, poor target-bin selection, and RF/phase instability.

### Suitable Chirp Settings

| Goal | Recommended Chirp |
|---|---|
| First heartbeat attempt | 1 ms, 200 MHz |
| Better heartbeat SNR | Stable stationary chest target, strong return, low clutter |
| Reduce latency | 10-20 s analysis window |
| Improve confidence | Suppress breathing motion before heartbeat extraction |

The current app implements a first useful heartbeat view. It is not yet a
medical-grade heartbeat algorithm. The practical next step is breathing
suppression/adaptive filtering after the breathing demo works reliably.

## 9. SAR Imaging Experiments

### How It Is Produced

SAR needs many coherent range profiles while the radar moves along a known
aperture.

The app implements two experimental views:

1. Aperture FFT quicklook.
2. Simple monostatic backprojection.

The capture process:

```text
move radar along a straight path -> collect complex range FFTs
-> estimate platform step from speed and chirp spacing
-> backproject range profiles onto an x/range grid
```

This is useful for checking whether phase coherence and aperture motion are
present. It is not a replacement for a controlled rail/encoder setup.

### Suitable Chirp Settings

| Goal | Recommended Chirp |
|---|---|
| First SAR experiment | 1 ms, 200 MHz |
| Better cross-range image | Stable slow platform motion and known position |
| Better range resolution | Higher bandwidth |
| Better focus | Encoder/IMU position metadata or autofocus |

SAR quality depends heavily on position knowledge. Approximate hand motion will
produce a rough image or a smeared image. A rail or encoder is strongly preferred.

## 10. Firmware Timing: Is Variable Chirp Time Doable?

Short answer:

```text
The ADF4158 can be programmed for variable chirp times,
but the current streaming firmware flow is effectively fixed around a
10000-sample / 1 ms capture frame at 10 MHz.
```

### Why It Is Currently Fixed

The firmware stream constants are compile-time definitions:

```c
#define FMCW_STREAM_SAMPLE_RATE_HZ     10000000UL
#define FMCW_STREAM_SAMPLES_PER_SLOPE  10000UL
#define FMCW_STREAM_WORDS_PER_SLOPE    5000UL
#define FMCW_STREAM_FRAME_BYTES        20480U
```

The DCMI DMA is also armed with:

```c
DMA2_Stream1->NDTR = FMCW_STREAM_WORDS_PER_SLOPE;
```

That means every frame captures exactly `5000` DCMI words, or `10000` ADC
samples. At 10 MHz, this is exactly:

```text
10000 samples / 10 MHz = 1.000 ms
```

The USB parser, headers, buffer size, and PC app all assume this fixed frame
shape.

### What Happens If The PLL Chirp Time Does Not Match?

If the PLL chirp is shorter than 1 ms but firmware still captures 10000 samples:

```text
one USB frame contains more than one chirp
range FFT becomes invalid for a single chirp
phase tracking and Doppler axes become wrong
```

If the PLL chirp is longer than 1 ms:

```text
one USB frame only captures the first 1 ms of the chirp
bandwidth used by DSP is not the full programmed bandwidth
range scaling becomes wrong unless corrected
```

Important observation from the current code snapshot:

```c
ADF4158_ProgramFastChirpTest();
```

appears in the streaming branch of `main.c`. That fast test preset is documented
as a `0.08 ms` chirp. If the firmware is run exactly like that, the stream
capture length no longer matches the chirp. For the PC app defaults, use the
normal 1 ms preset or change the PC/firmware timing together.

### Is Variable Chirp Time Possible Later?

Yes, but it needs a firmware-level refactor. The design should become
configuration-driven:

1. Program the ADF4158 chirp preset.
2. Compute:

```text
samples_per_slope = sample_rate_hz * chirp_time_s
words_per_slope = samples_per_slope / 2
payload_bytes = words_per_slope * 4
frame_bytes = header + payload + USB alignment padding
```

3. Reconfigure DMA `NDTR` for the selected chirp.
4. Update headers with the actual sample count and chirp parameters.
5. Make the PC parser accept variable frame sizes or a negotiated mode.
6. Ensure USB throughput can handle the selected frame rate.
7. Recheck MUXOUT alignment and HSYNC/VSYNC timing for every mode.

So, variable chirp time is technically doable, but it is not currently an
on-demand GUI setting. Right now it should be treated as fixed by the firmware
build/preset.

## 11. Chirp Recommendations By Feature

| Feature | Good Starting Chirp | Notes |
|---|---|---|
| Range measurement | 1 ms, 200 MHz | Current normal preset; about 0.75 m resolution. |
| Range waterfall | 1 ms, 200 MHz | Good for live bring-up and target movement. |
| Range-Doppler | 1 ms, 200 MHz, CPI 128-512 | More CPI improves velocity resolution but adds latency. |
| Micromotion | 1 ms, 200 MHz | Stable phase and target-bin selection are most important. |
| Breathing | 1 ms, 200 MHz | Decimate phase stream to 20-100 Hz. |
| Heartbeat | 1 ms, 200 MHz | Needs strong stable chest return; heartbeat is weak. |
| SAR | 1 ms, 200 MHz | Needs known aperture motion; bandwidth controls range resolution. |
| Fast motion tests | shorter chirp possible | Firmware capture length must be changed to match. |
| High range resolution | higher bandwidth | Requires corresponding ADF4158 values and front-end bandwidth. |
| Long-range low-noise tests | longer chirp can help | Firmware buffer length and USB rate must be updated. |

## 12. Practical Bring-Up Order

Recommended order:

1. Use the normal 1 ms PLL preset.
2. Verify USB stream has no or low dropped-frame count.
3. Open the Range tab and confirm a stable peak.
4. Force the target range manually if auto-pick chooses leakage/clutter.
5. Check micromotion displacement.
6. Confirm breathing peak before attempting heartbeat.
7. Use range-Doppler once range FFT and stream health are good.
8. Treat SAR as a separate controlled experiment with known motion.

## 13. Reference Basis

This work was guided by:

- The local STM32 firmware stream implementation in `Core/Inc/fmcw_stream.h` and
  `Core/Src/fmcw_stream.c`.
- The local ADF4158 presets in `Core/Src/adf4158.c`.
- The `ckflight/FMCW3` project description, which lists the target feature set:
  range, range-Doppler, SAR, micromotion, breathing/heartbeat, USB streaming.
- The companion `ckflight/FMCW_RADAR_2v2` Python scripts, which use the same
  conceptual processing flow: range FFT, CPI range-Doppler, phase-bin tracking,
  and SAR experiments.

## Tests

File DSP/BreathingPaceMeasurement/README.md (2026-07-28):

# Breathing Pace Measurement

This module implements contactless breathing rate detection using micro-Doppler analysis of FMCW radar returns.

## Principle

A stationary person's chest wall moves slowly (~0.2–1 Hz) during breathing. This periodic displacement modulates the phase of the received radar signal. By tracking the phase of the dominant range bin over time and applying spectral analysis, the breathing rate can be extracted.

```
f_breathing  ≈  phase_variation_frequency  (typically 0.1 – 0.5 Hz)
```

Processing steps:
1. Perform range FFT to locate the stationary subject.
2. Extract the phase of the dominant range bin across successive chirps.
3. Apply a band-pass filter (e.g., 0.1 – 1.0 Hz) to isolate breathing motion.
4. Estimate the dominant frequency (peak of FFT) as the breathing rate.

## Files

| File | Description |
|---|---|
| *(to be added)* | Phase extraction from range bins |
| *(to be added)* | Band-pass filtering |
| *(to be added)* | Breathing rate spectral estimation |

## References

- C. Li and J. Lin, "Random Body Movement Cancellation in Doppler Radar Vital Sign Detection," *IEEE Trans. Microw. Theory Tech.*, vol. 56, no. 12, pp. 3143–3152, 2008.

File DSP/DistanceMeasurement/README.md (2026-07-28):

#  Distance Measurement (Range FFT)

This module handles the **Fast-Time** signal processing. Its goal is to locate the physical distance of targets by extracting the beat frequency ($f_b$) from the raw IF signal.

##  The Mathematics

Distance ($R$) is directly proportional to the beat frequency ($f_b$) generated by the mixer:
$$R = \frac{c \cdot T_c \cdot f_b}{2B}$$

* $c$: Speed of Light
* $T_c$: Chirp Duration
* $B$: Swept Bandwidth

### Range Resolution ($\Delta R$)
The absolute precision of this module is dictated entirely by the hardware bandwidth ($B$). Targets closer than $\Delta R$ will merge into a single FFT bin.
$$\Delta R = \frac{c}{2B}$$

##  Algorithmic Flow

1. **DC Mean Subtraction:** Raw ADC data contains a large DC bias and static TX-RX leakage. If left uncorrected, this creates a massive peak at 0 Hz (0 meters) that blinds the radar to close targets.
   $$x_{clean}[n] = x[n] - \mu_x$$
2. **Windowing:** A standard Hanning or Hamming window is applied to the time-domain data to reduce spectral leakage (sidelobes) before the FFT.
3. **The Fast Fourier Transform (FFT):** Converts the time-domain waveform into the frequency domain.

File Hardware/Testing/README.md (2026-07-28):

# Hardware / Testing

This folder contains GNU Radio Companion (GRC) test flows and notes used during hardware bring-up and verification of the FMCW radar front-end. Tests were performed with a bladeRF micro 2.0, a spectrum analyzer, and GRC flows included below.

## Overview / Goals
- Verify bladeRF TX/RX functionality and expected waterfall/FFT signatures.
- Detect and measure the 5.8 GHz chirp transmitted by the FMCW transmitter.
- Use bladeRF as a reference source and the spectrum analyzer for accurate power/frequency measurements.
- Use H near-field probes to compare relative power from bladeRF and the FMCW transmitter and to localize faults.
- Debug and fix transmitter faults, LNA(s), and mixer behavior on the receiver chain.
- Test antennas with controlled frequency offsets to avoid LO/DC leakage.

## Equipment
- bladeRF micro 2.0 (TX and RX)
- GNU Radio Companion (GRC)
- Spectrum analyzer (centered at 5.8 GHz)
- H near-field probes (for near-field relative power measurement)
- Directional couplers / SMA cables / attenuators
- Transmitter horn antenna (for TX-to-PCB coupling during antenna tests)
- Splitter for distributing LO/reference as needed

## Test flows (what each .grc does)
1. Self-test: bladerf_self_test.grc
   - Purpose: Confirm bladeRF functionality and GRC plotting behavior.
   - What to check: bladeRF TX -> bladeRF RX loop, waterfall and FFT sinks, adjustable chirp time so time-varying frequencies are clear.
   - Implementation note: Include a chirp generator (or tone source) with a GUI slider for chirp time and amplitude so you can quickly change sweep parameters and observe how the waterfall reacts.

2. Receiver check: rx_5p8Ghz_check.grc
   - Purpose: Receiver chain verification and antenna testing.
   - What to check: Probe LNA outputs with H near-field probe, verify which LNAs are active or faulty. Feed a bladeRF transmitter directly into the RX SMA input for a controlled reference signal.
   - Mixer check: Observe mixer output and beat/difference frequencies when LO/reference is offset slightly from the transmitter. Log the IF/beat frequency and confirm expected behavior.

3. Transmitter check: tx_5p8Ghz_check.grc
   - Purpose: Verify FMCW radar transmitter output and waterfall plots.
   - What to check: Observe the 5.8 GHz chirp on waterfall and spectrum analyzer, use adjustable center-frequency slider (smooth ±300 kHz) and chirp time control to visualize the sweep clearly.
   - Implementation note: Focus on waterfall diagrams. Set chirp time, sweep range, and sample rate so the chirp appears as a clear slanted line across the waterfall.

4. Antenna test: bladerf_antenna_test_5p8GHz.grc
   - Purpose: Measure transmitted power into the horn antenna and received levels on bladeRF.
   - What to check: Set transmitter to constant 5.800 GHz and set bladeRF receiver/horn to 5.799 GHz (small offset) to avoid DC/LO spike and observe received power and beat frequency.
   - Implementation note: Use attenuators and possibly an anechoic/coupled setup to protect RX and get repeatable power readings.

## Quick test checklist (run in order)
1. Self-test: Run bladerf_self_test.grc to confirm bladeRF and GRC sinks behave as expected (waterfall/FFT). Adjust chirp time until the chirp is clearly visible.
2. TX check: Run tx_5p8Ghz_check.grc connected to the FMCW transmitter (or bladeRF acting as TX) and confirm stable 5.8 GHz chirp on waterfall and spectrum analyzer.
3. Antenna test: Run bladerf_antenna_test_5p8GHz.grc with TX set to constant 5.800 GHz and bladeRF RX to 5.799 GHz. Record received power at horn antenna and note any LO/DC leakage effects.
4. RX check: Run rx_5p8Ghz_check.grc. Probe LNA stages with H-probe while driving the RX SMA with bladeRF. Verify LNA outputs and mixer IF/beat frequency. Replace/repair failed LNAs and re-test.

## How to run (high-level)
- Open the .grc file in GNU Radio Companion.
- Set sample rate to the rate supported by bladeRF for operation near 5.8 GHz.
- Set center frequency (default: 5.8e9) and chirp parameters as appropriate for the flow.
- Use GUI sliders to vary chirp time, small center-frequency offsets, transmitter gain, and/or receiver gain.
- Always use attenuators when connecting TX to RX or spectrum analyzer to avoid damage.

## Recommended default parameters
- Center frequency: 5.8e9 (5.8 GHz)
- Sweep range for transmitter-check: ±300e3 (±300 kHz)
- Chirp time slider: 1e-3 to 8 s (1 ms to 8 s)
- FFT size / waterfall resolution: 2048 or 4096 bins (tune as needed)

## Measurement & safety notes
- Use attenuators if needed when connecting TX to RX or to the spectrum analyzer.
- Limit bladeRF TX output power to avoid damaging the receiver front-end or LNAs.
- Ensure antennas are properly oriented and maintain safe RF exposure distances.

## Observed issues & fixes (from this test campaign)
- Transmitter faults were discovered and iteratively fixed until stable chirp output was observed on the spectrum analyzer and waterfall plots.
- Receiver debug using bladeRF reference showed a failed first LNA (no output) while the second LNA was functional. Replacing the first LNA restored expected mixer output.
- Using a small offset between the LO-fed transmitter and the bladeRF reference helped visualize the beat frequency and confirmed proper LO splitting and mixer response.
- Near-field H-probe testing was instrumental in locating faulty components and in interpreting spectrum analyzer power readings.

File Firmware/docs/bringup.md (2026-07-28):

# Bring-Up Checklist

1. Verify HSE bypass operation and PLL: `SYSCLK=168 MHz`, `APB1=42 MHz`, `APB2=84 MHz`.
2. Scope PA8. It should output `10.000000 MHz` from `MCO1 = HSE / 2`.
3. Confirm USB3317 26 MHz reference and ULPI 60 MHz clock before enumeration.
4. Enumerate USB. The device should expose one vendor-specific interface and one bulk IN endpoint.
5. Validate DCMI packing with a known digital pattern before enabling the RF ramp.
6. Confirm PE5 MUXOUT pulses every 1 ms from the ADF4158.
7. Scope PA4 during first MUXOUT. It should rise about 309 ns after the first edge.
8. Check PA7 at the same time. It should follow PA4 because it is the routed-back HSYNC feedback signal.
9. Confirm captured ADC data looks correct with DCMI sampling on the falling PIXCLK edge.
10. Run `python host/fmcw_capture.py --frames 1000 --stats`.
11. Watch for nonzero flags. `USB_LATE` means the host is not draining quickly enough; `DROPPED`, `DCMI_OVR`, or `ALIGN_LOST` means discard affected data.

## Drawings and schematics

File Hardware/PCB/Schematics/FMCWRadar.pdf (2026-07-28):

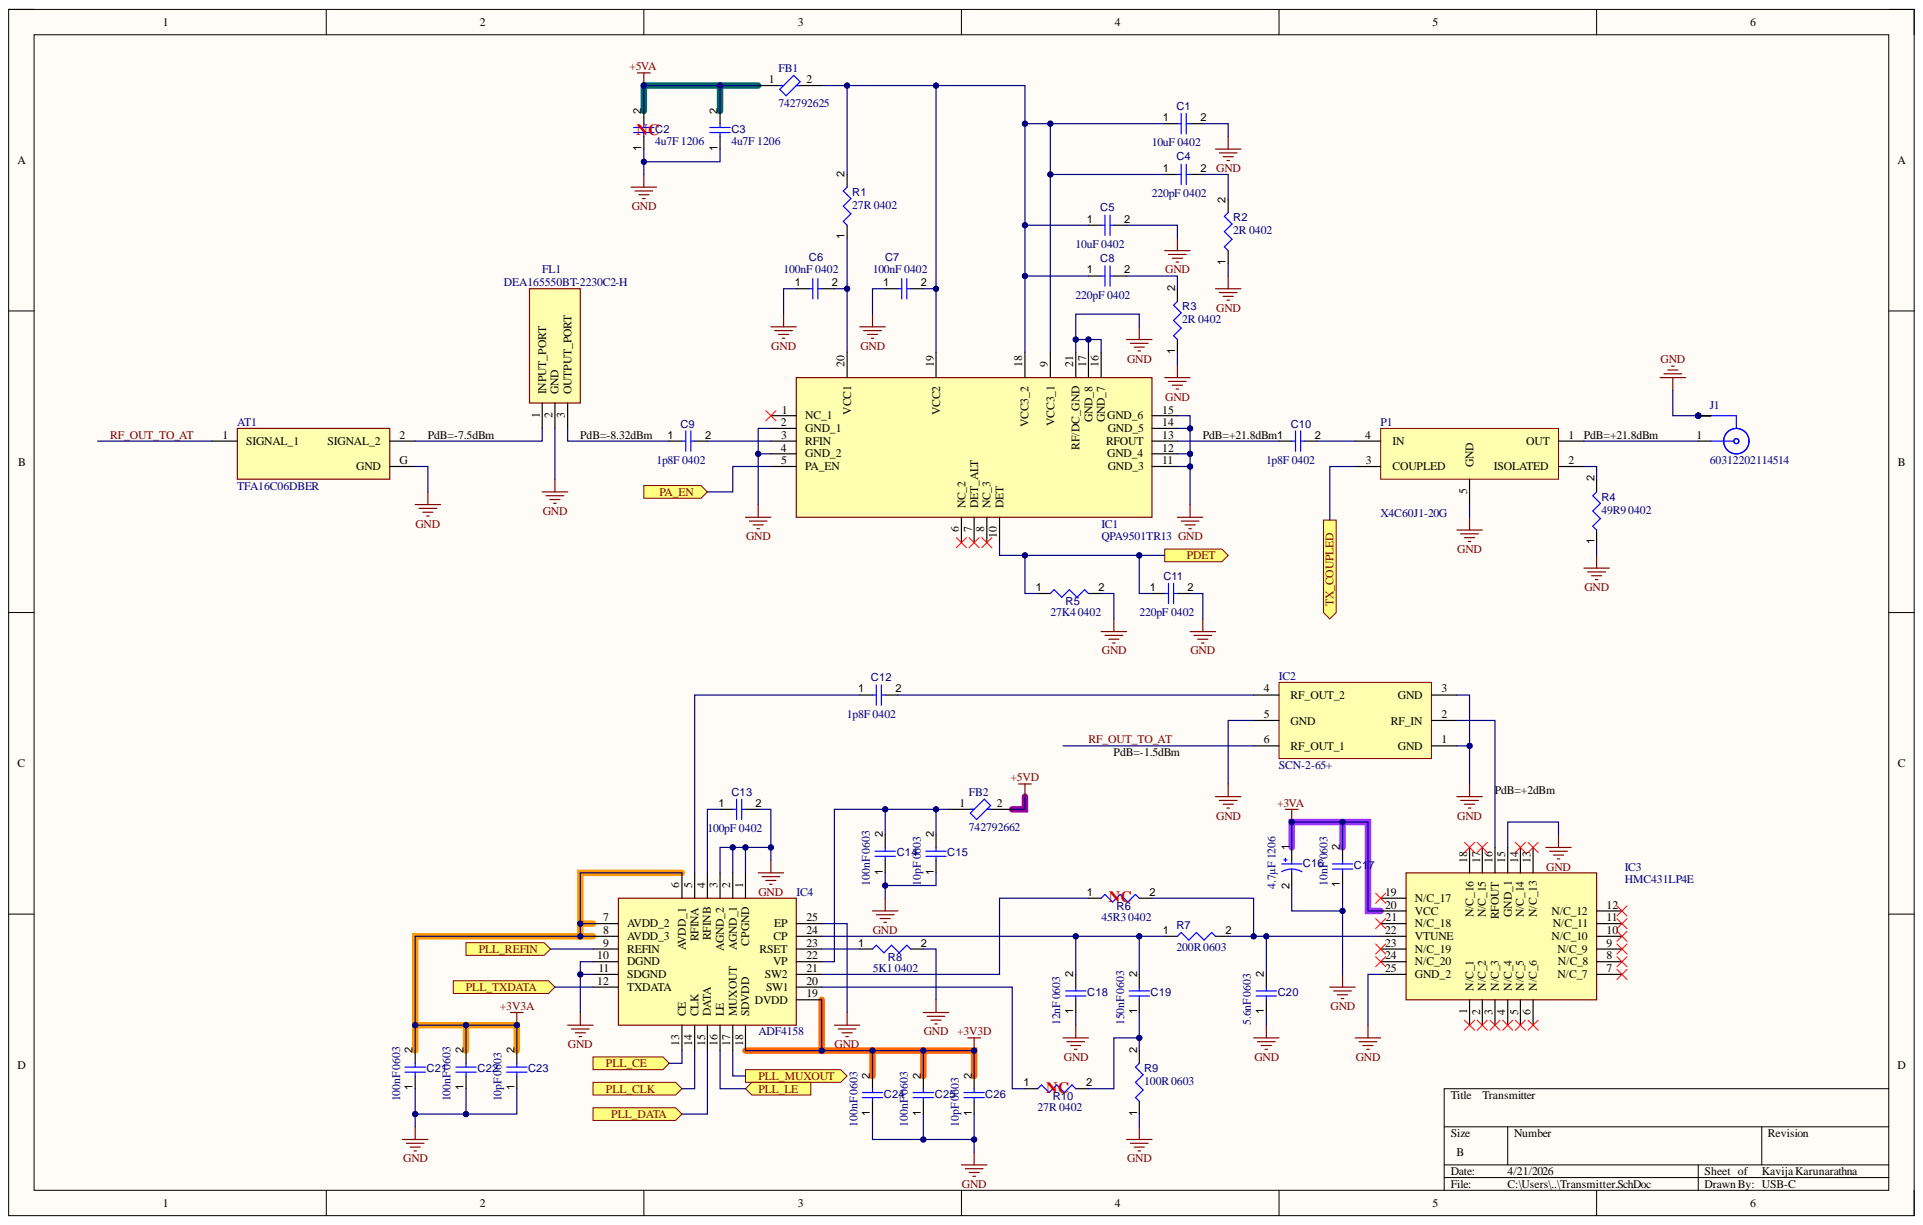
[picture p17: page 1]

GND_2 4 | IC2
PA_EN 5

SDVDD 18 MUXOUT 17 LE 16 DATA 15 CLK 14 CE 13

Size B | Number | Revision

Date: 4/21/2026 | Sheet of Kavija Karunarathna

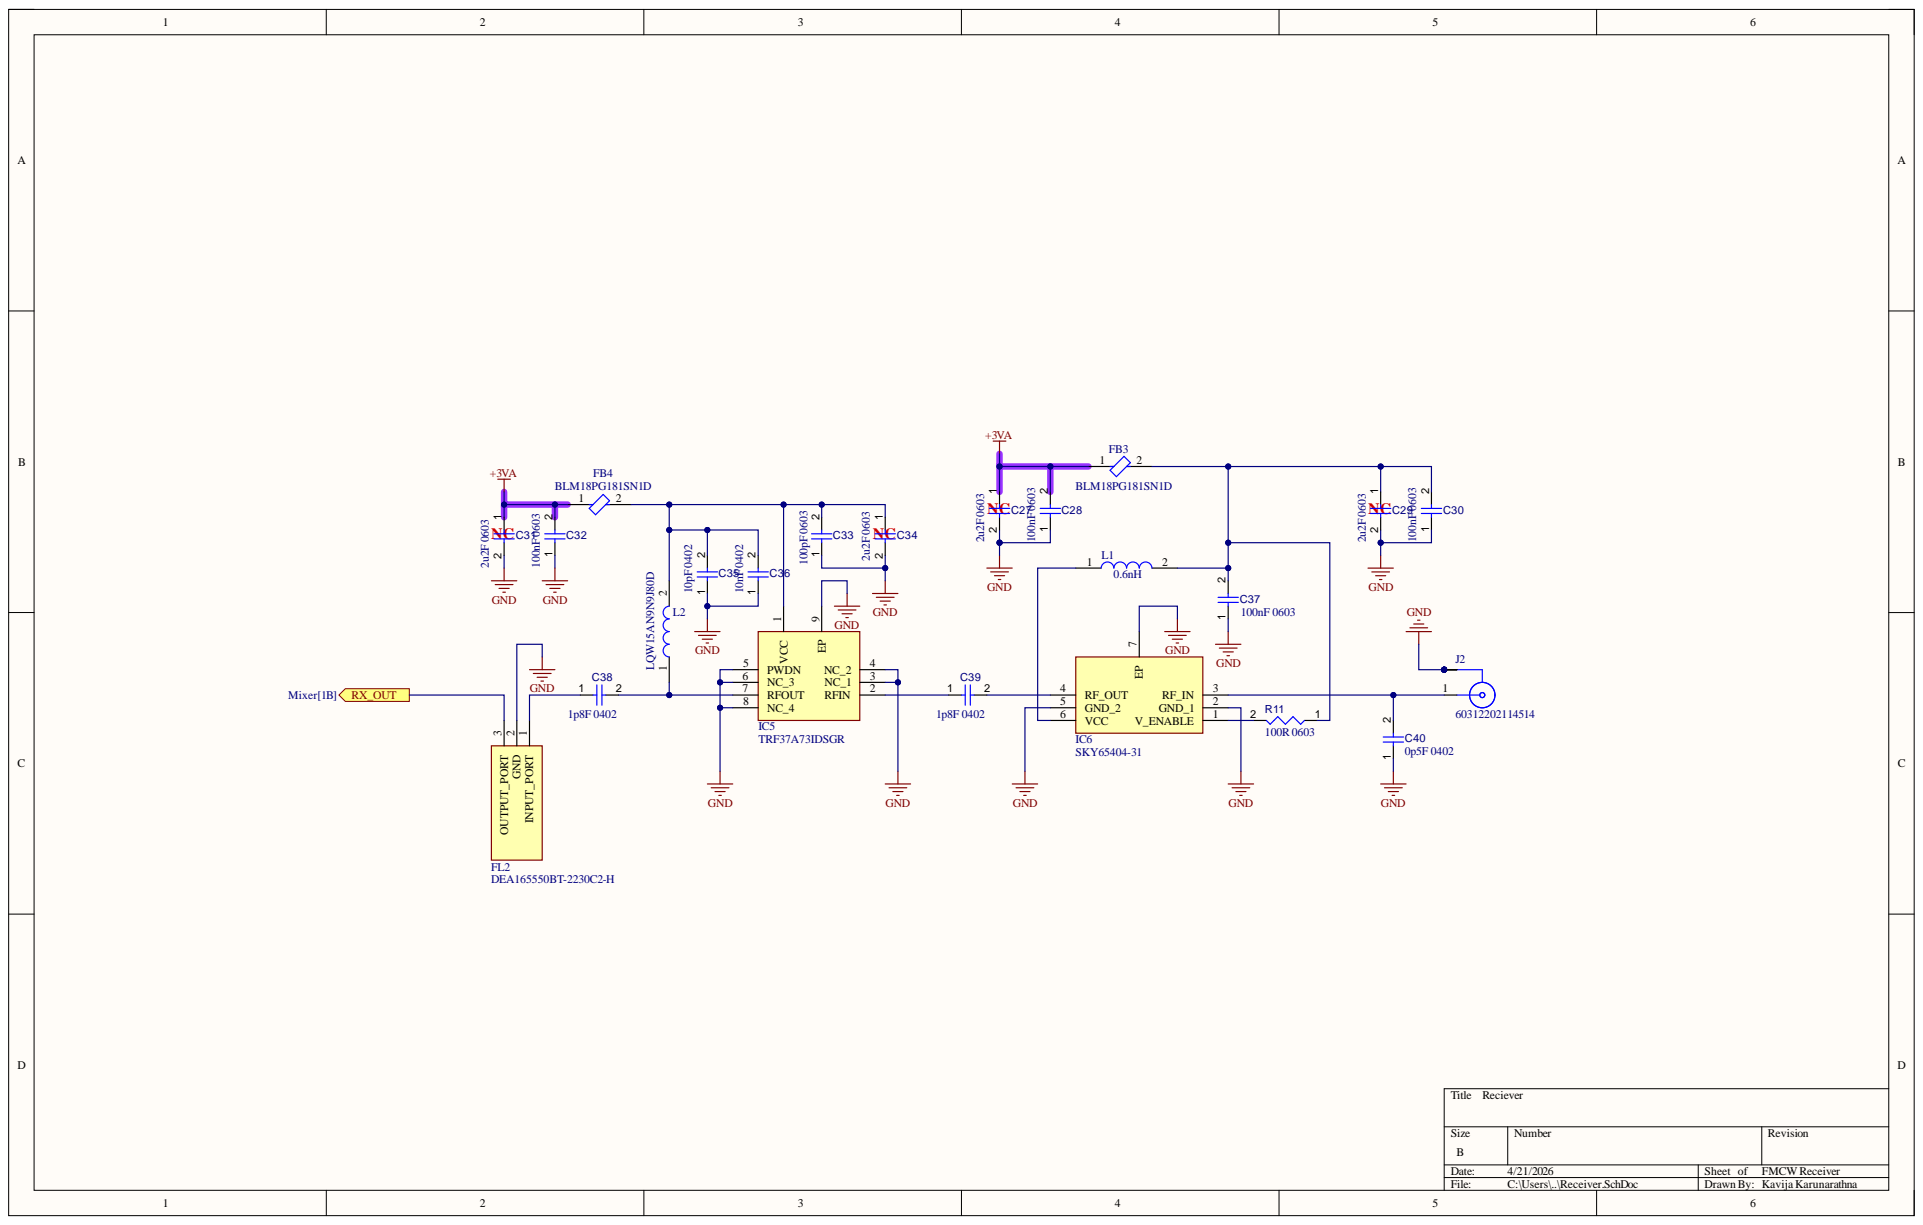
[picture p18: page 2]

Size B | Number | Revision

Date: 4/21/2026 | Sheet of FMCW Receiver
File: C:\Users\..\Receiver.SchDoc | Drawn By: Kavija Karunarathna

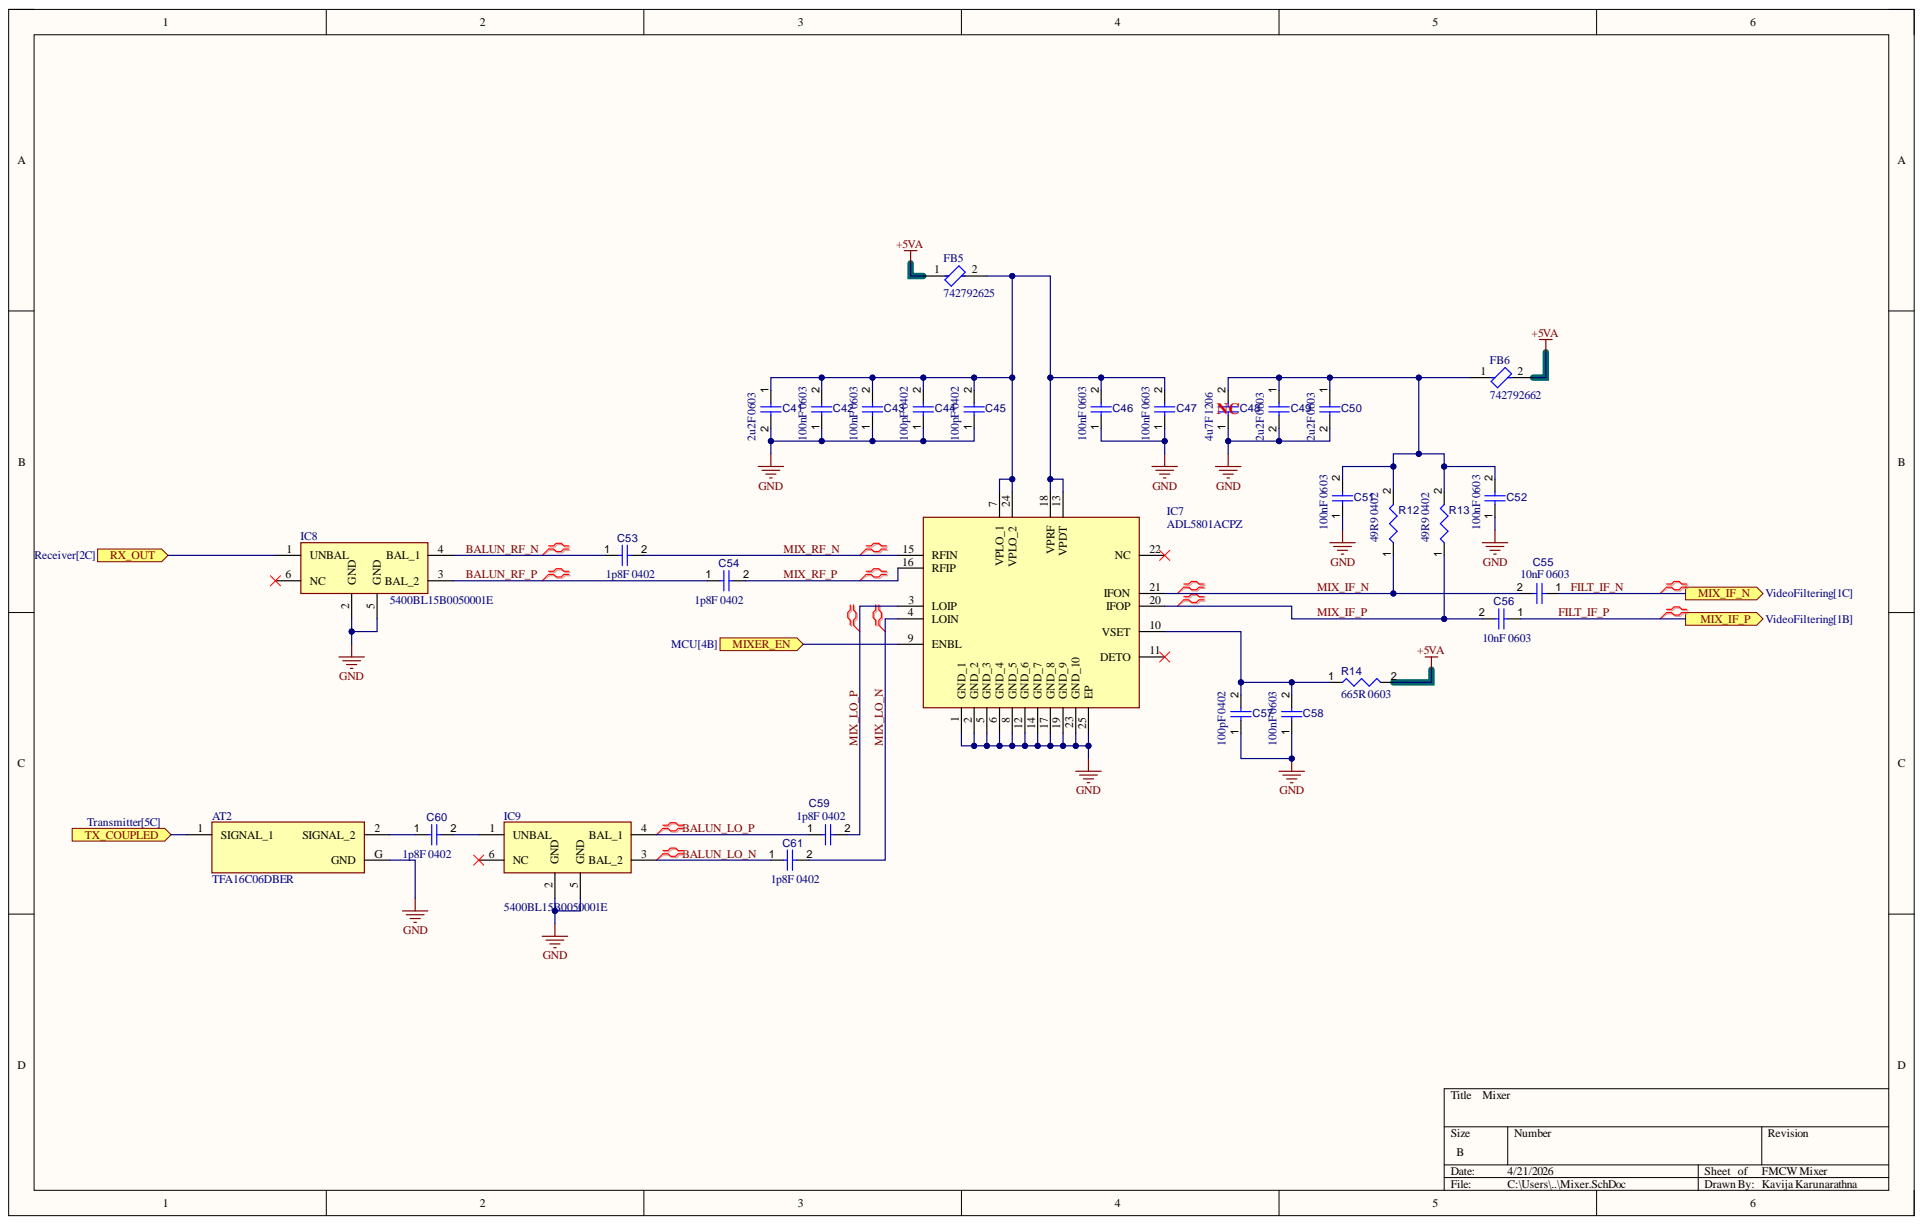
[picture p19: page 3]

Size B | Number | Revision

Date: 4/21/2026 | Sheet of FMCW Mixer
File: C:\Users\..\Mixer.SchDoc | Drawn By: Kavija Karunarathna

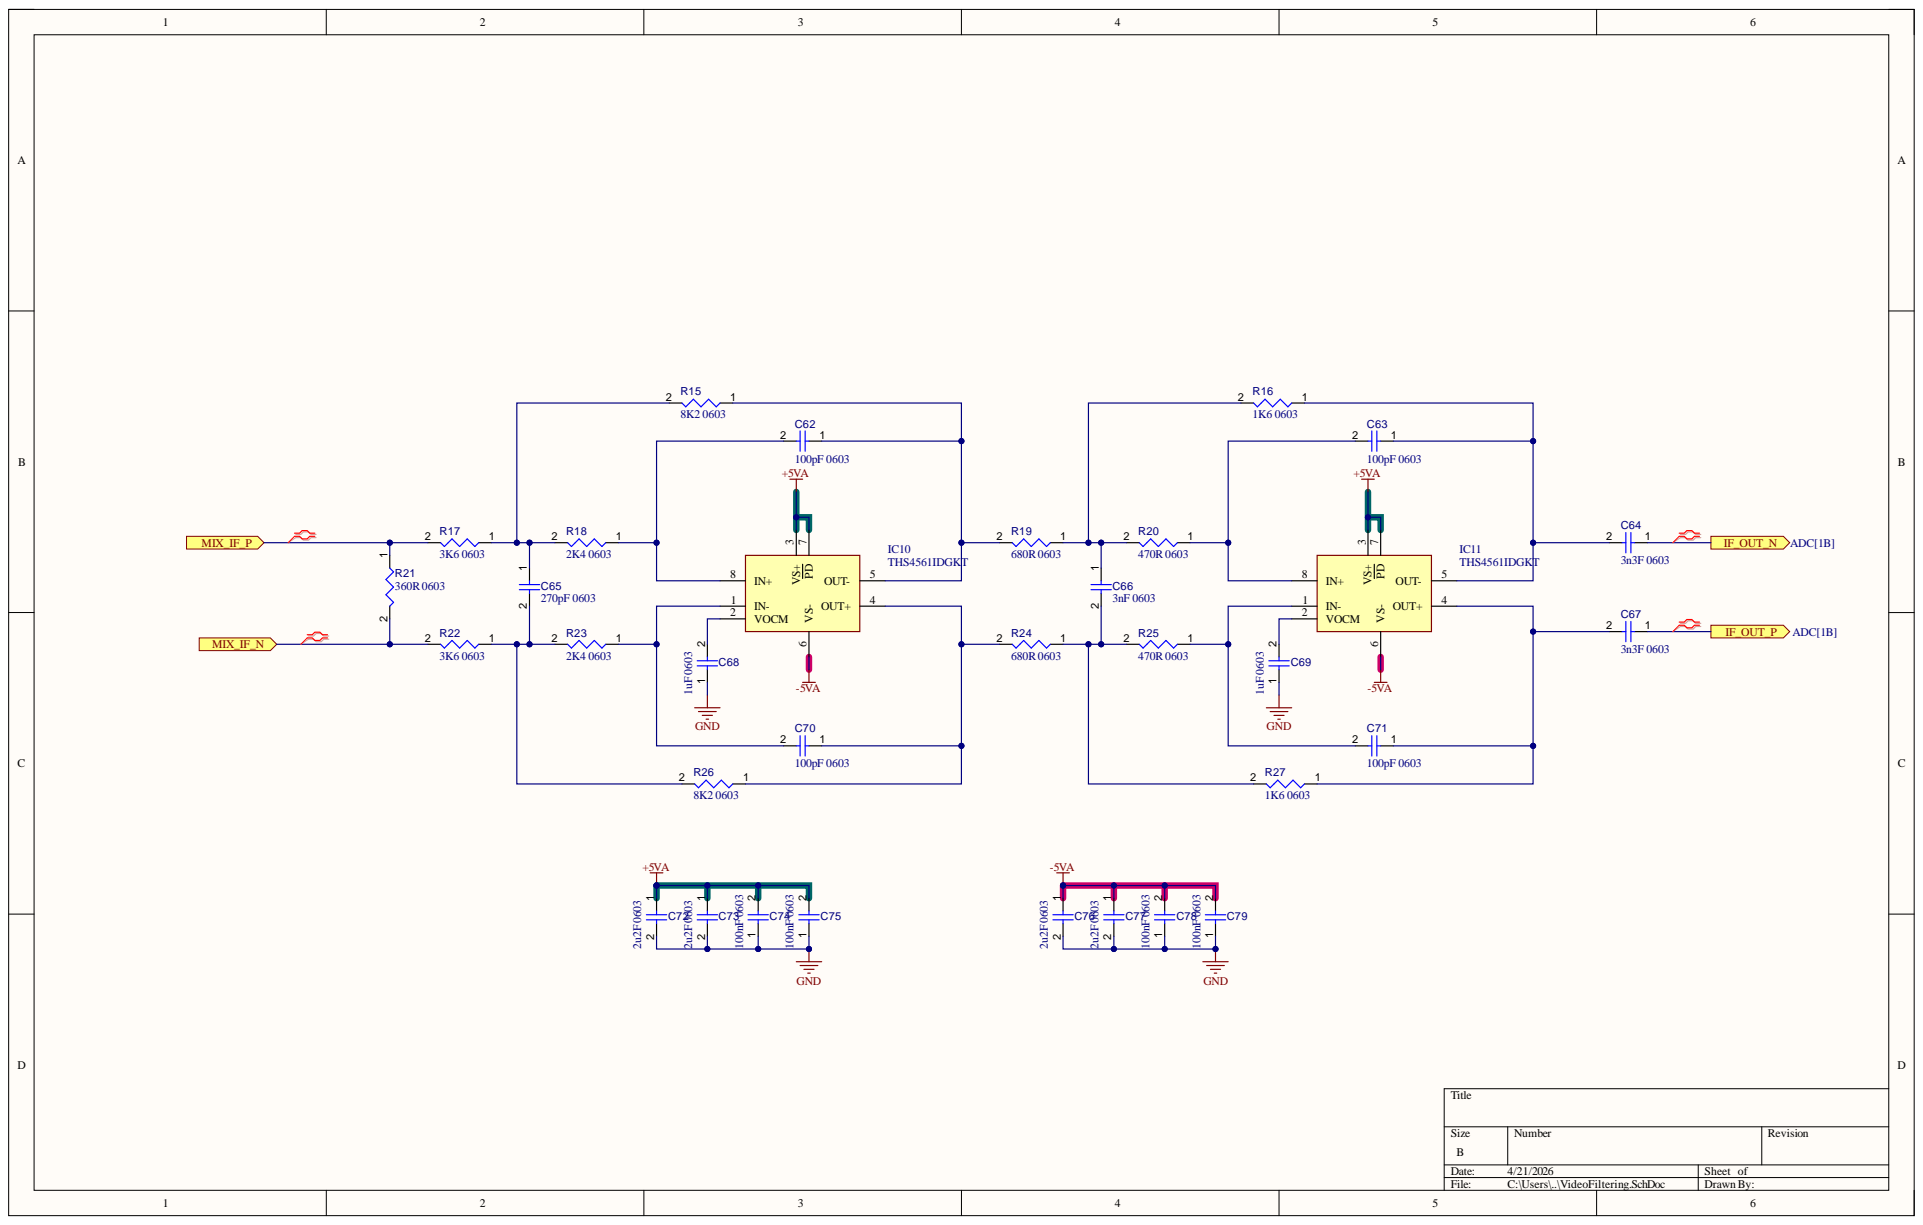
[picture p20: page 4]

Size B | Number | Revision

Date: 4/21/2026 | Sheet of
File: C:\Users\..\VideoFiltering.SchDoc | Drawn By:

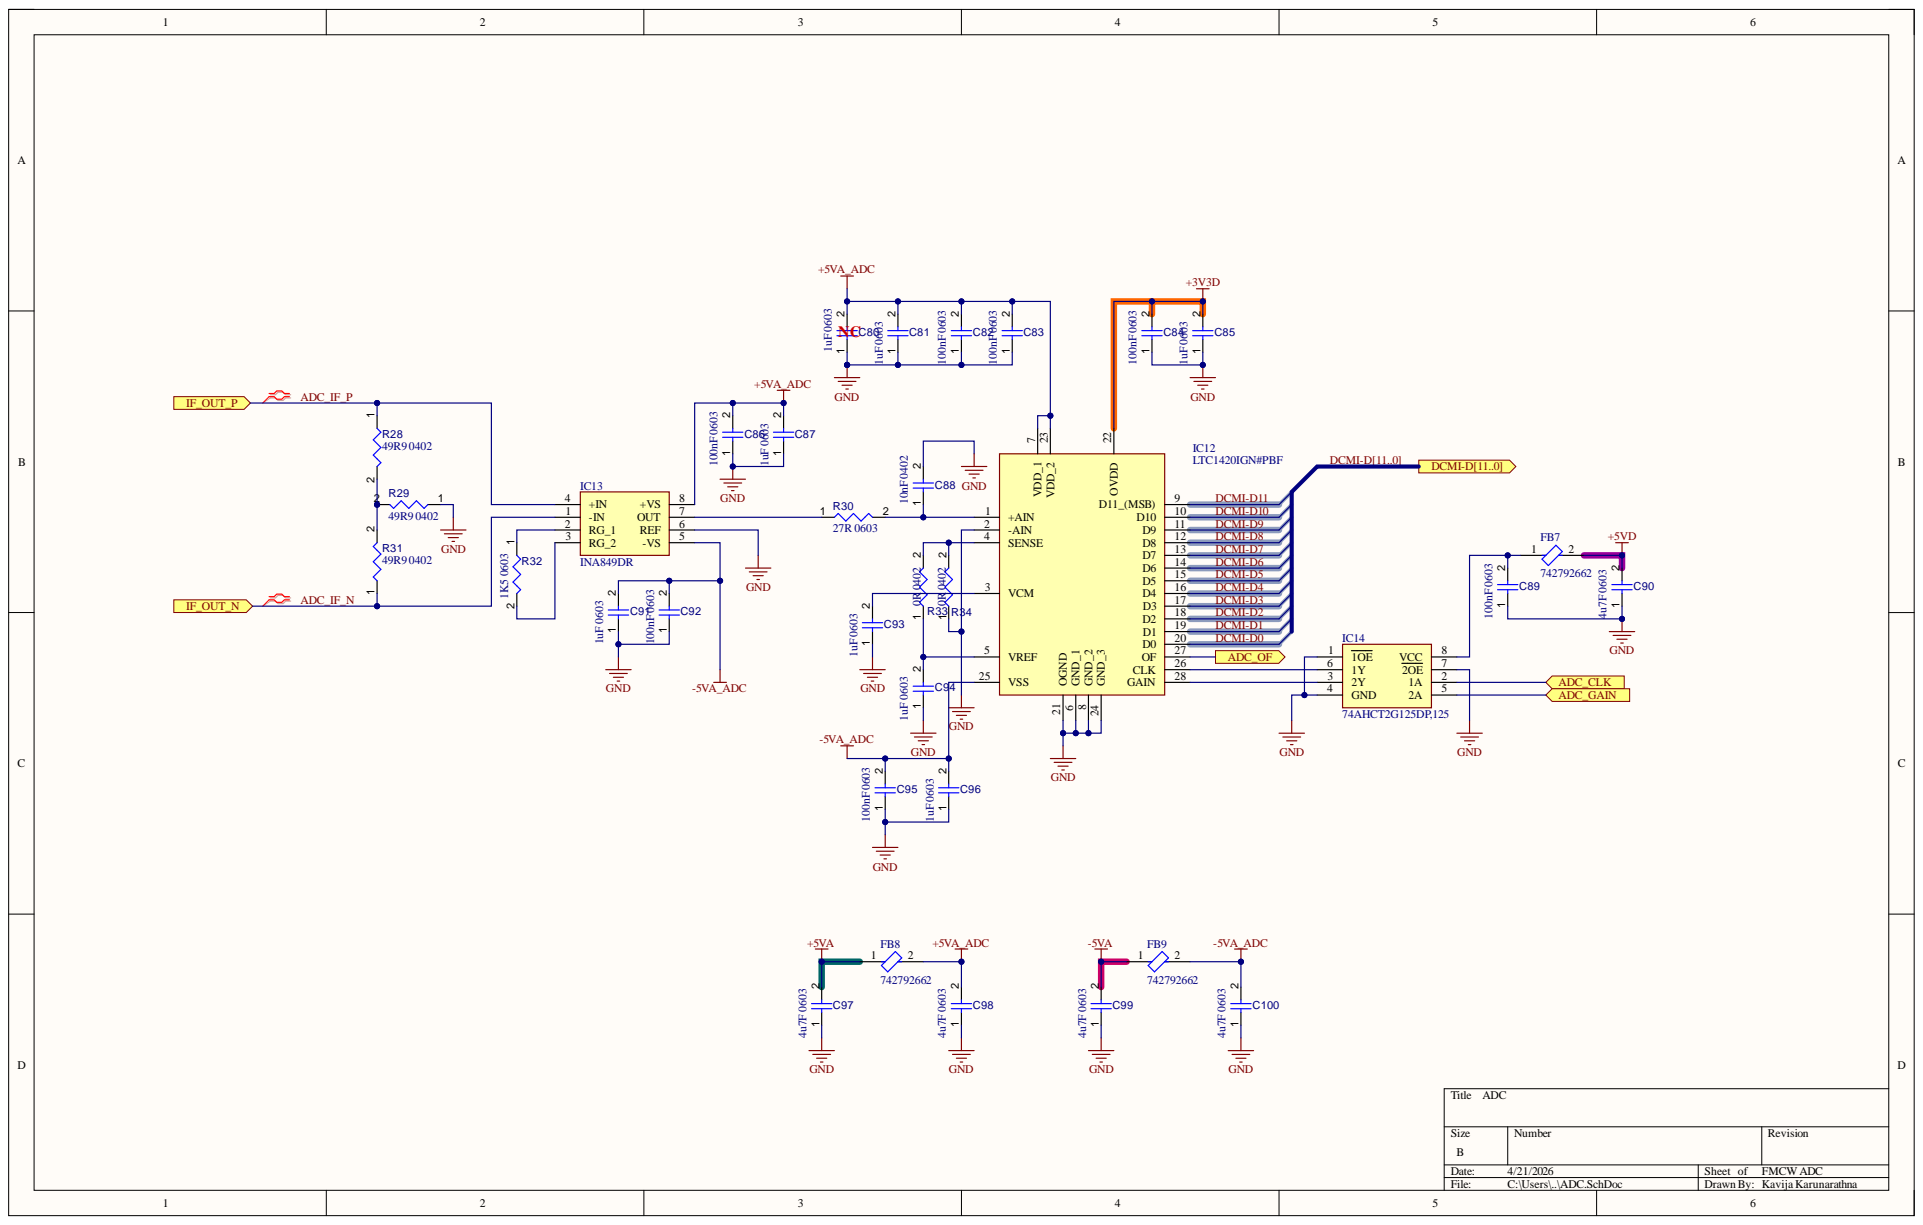
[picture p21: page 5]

Size B | Number | Revision

Date: 4/21/2026 | Sheet of FMCW ADC
File: C:\Users\..\ADC.SchDoc | Drawn By: Kavija Karunarathna

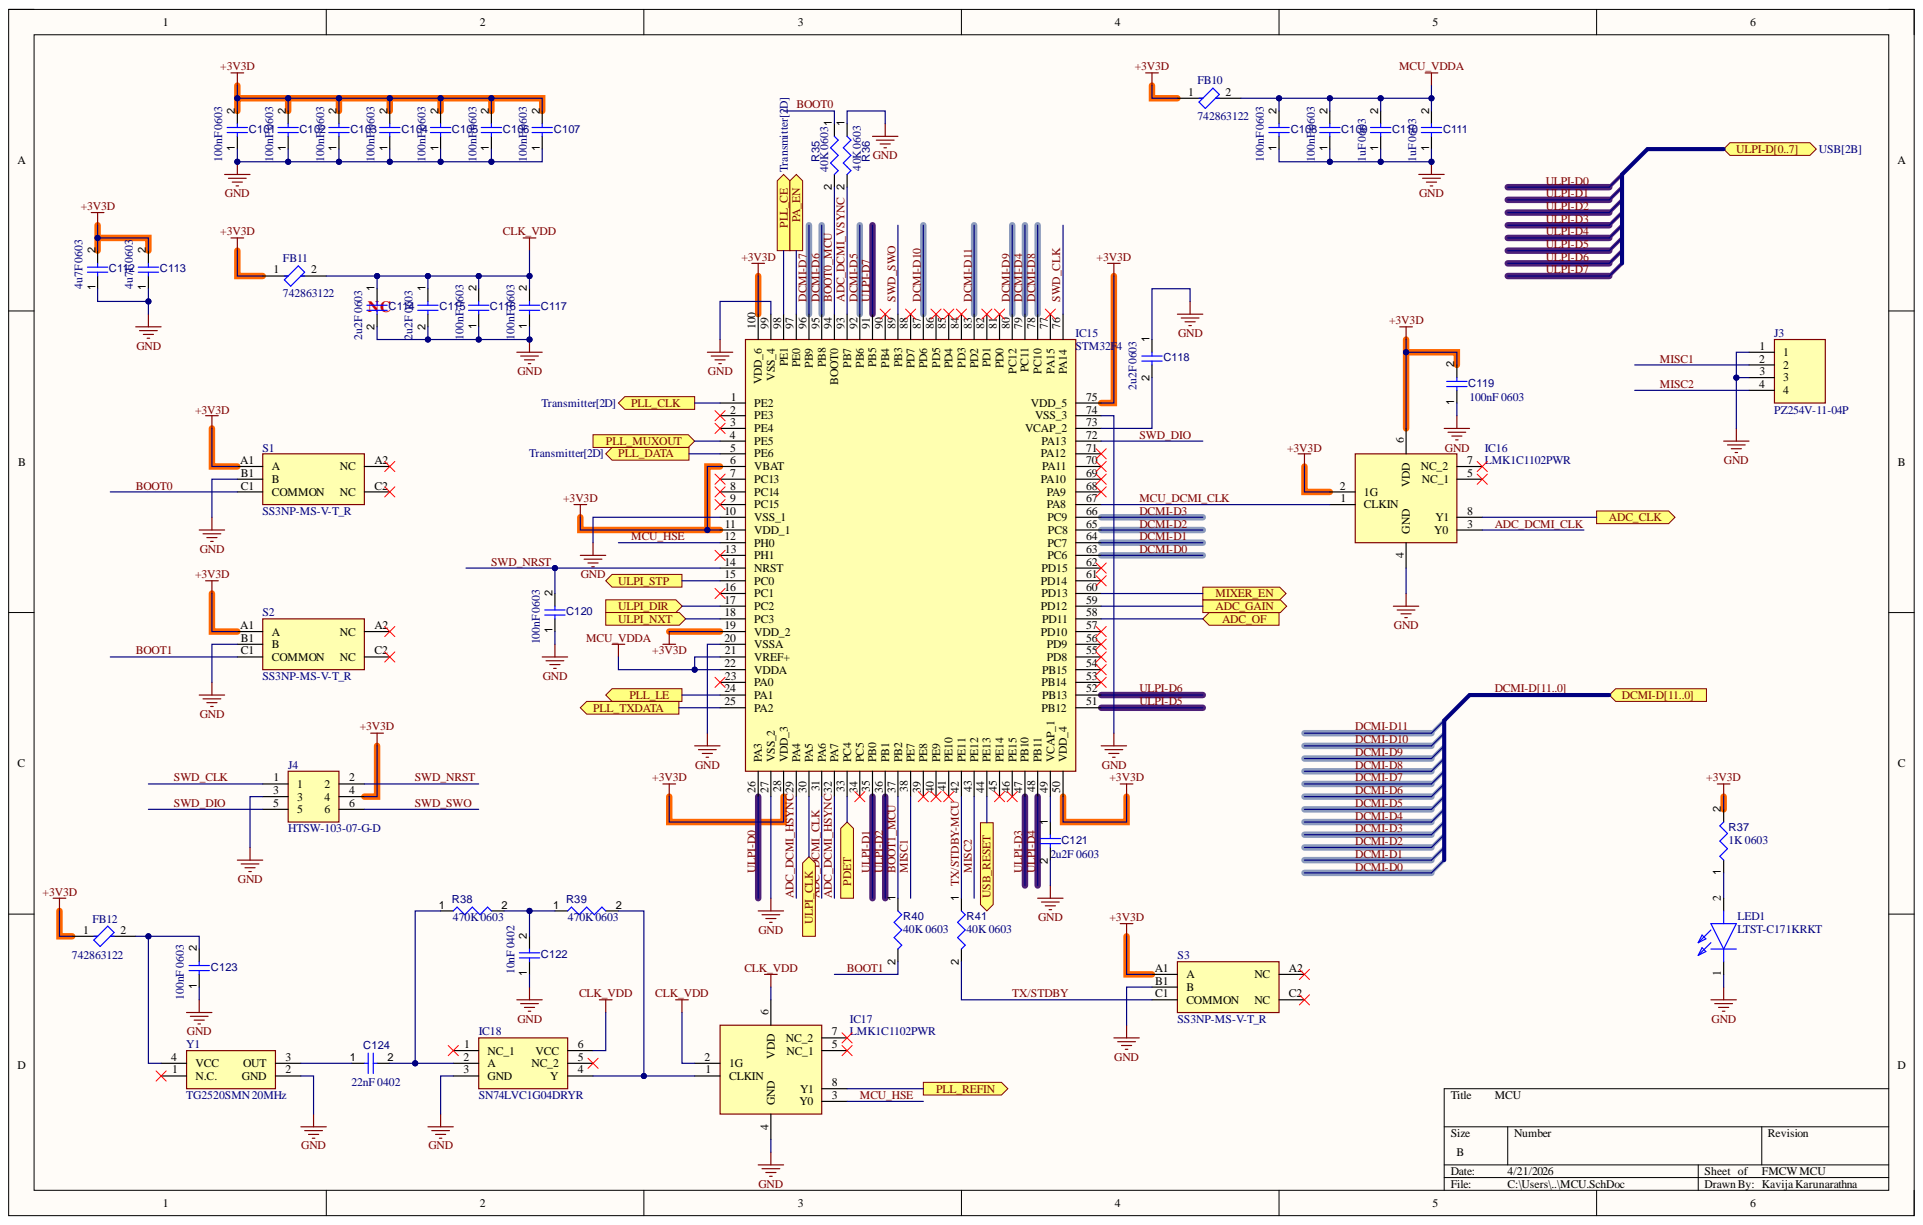
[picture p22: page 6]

VDD_1 11

MCU_HSE | PH0 12

Size B | Number | Revision

Date: 4/21/2026 | Sheet of FMCW MCU

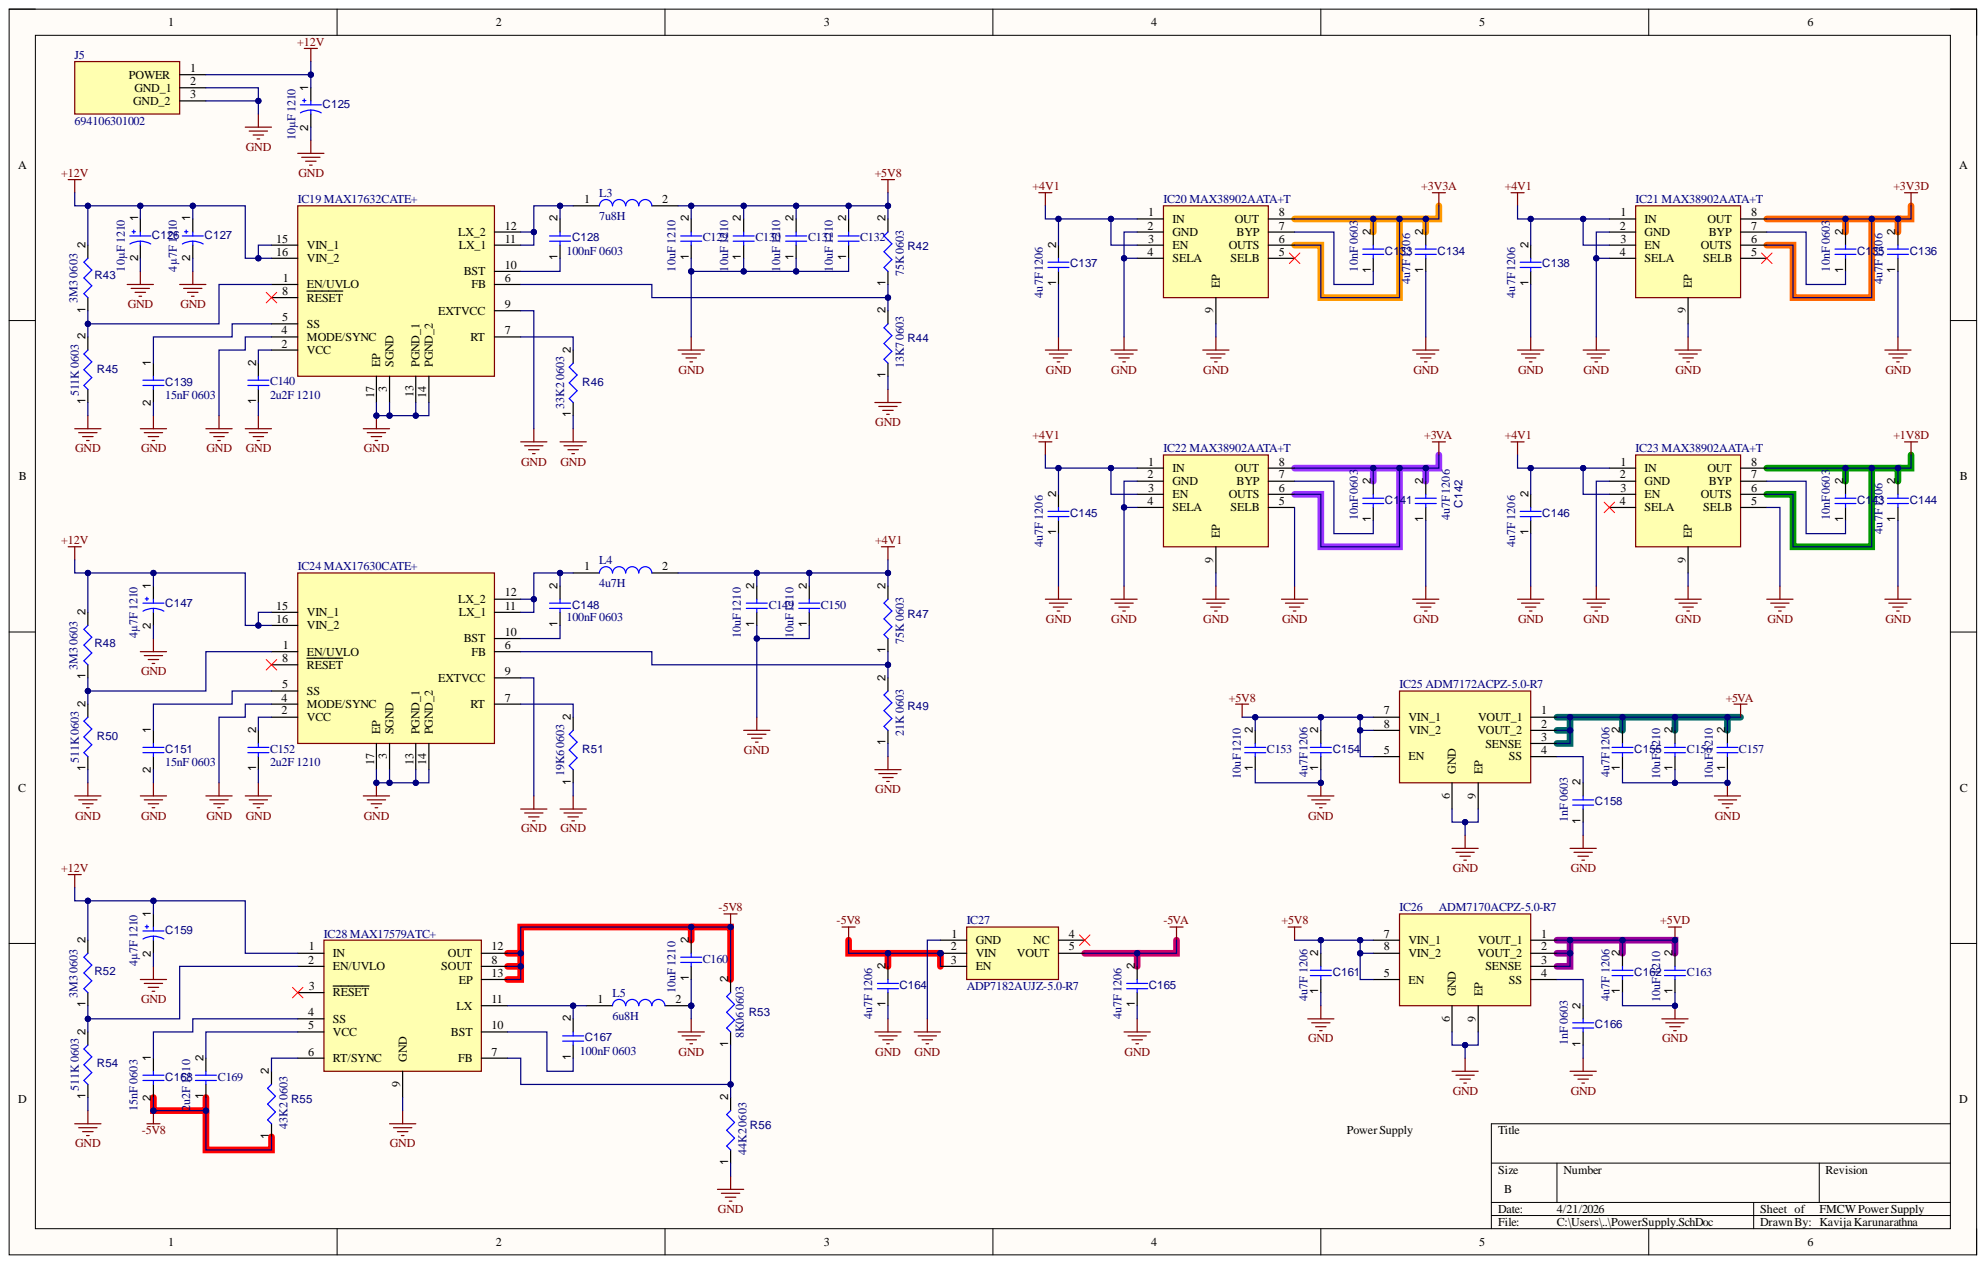
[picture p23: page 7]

POWE R G N D_1 G N D_2 | +12V1 2

8 | 2 | C 1 5 5 | C15 6

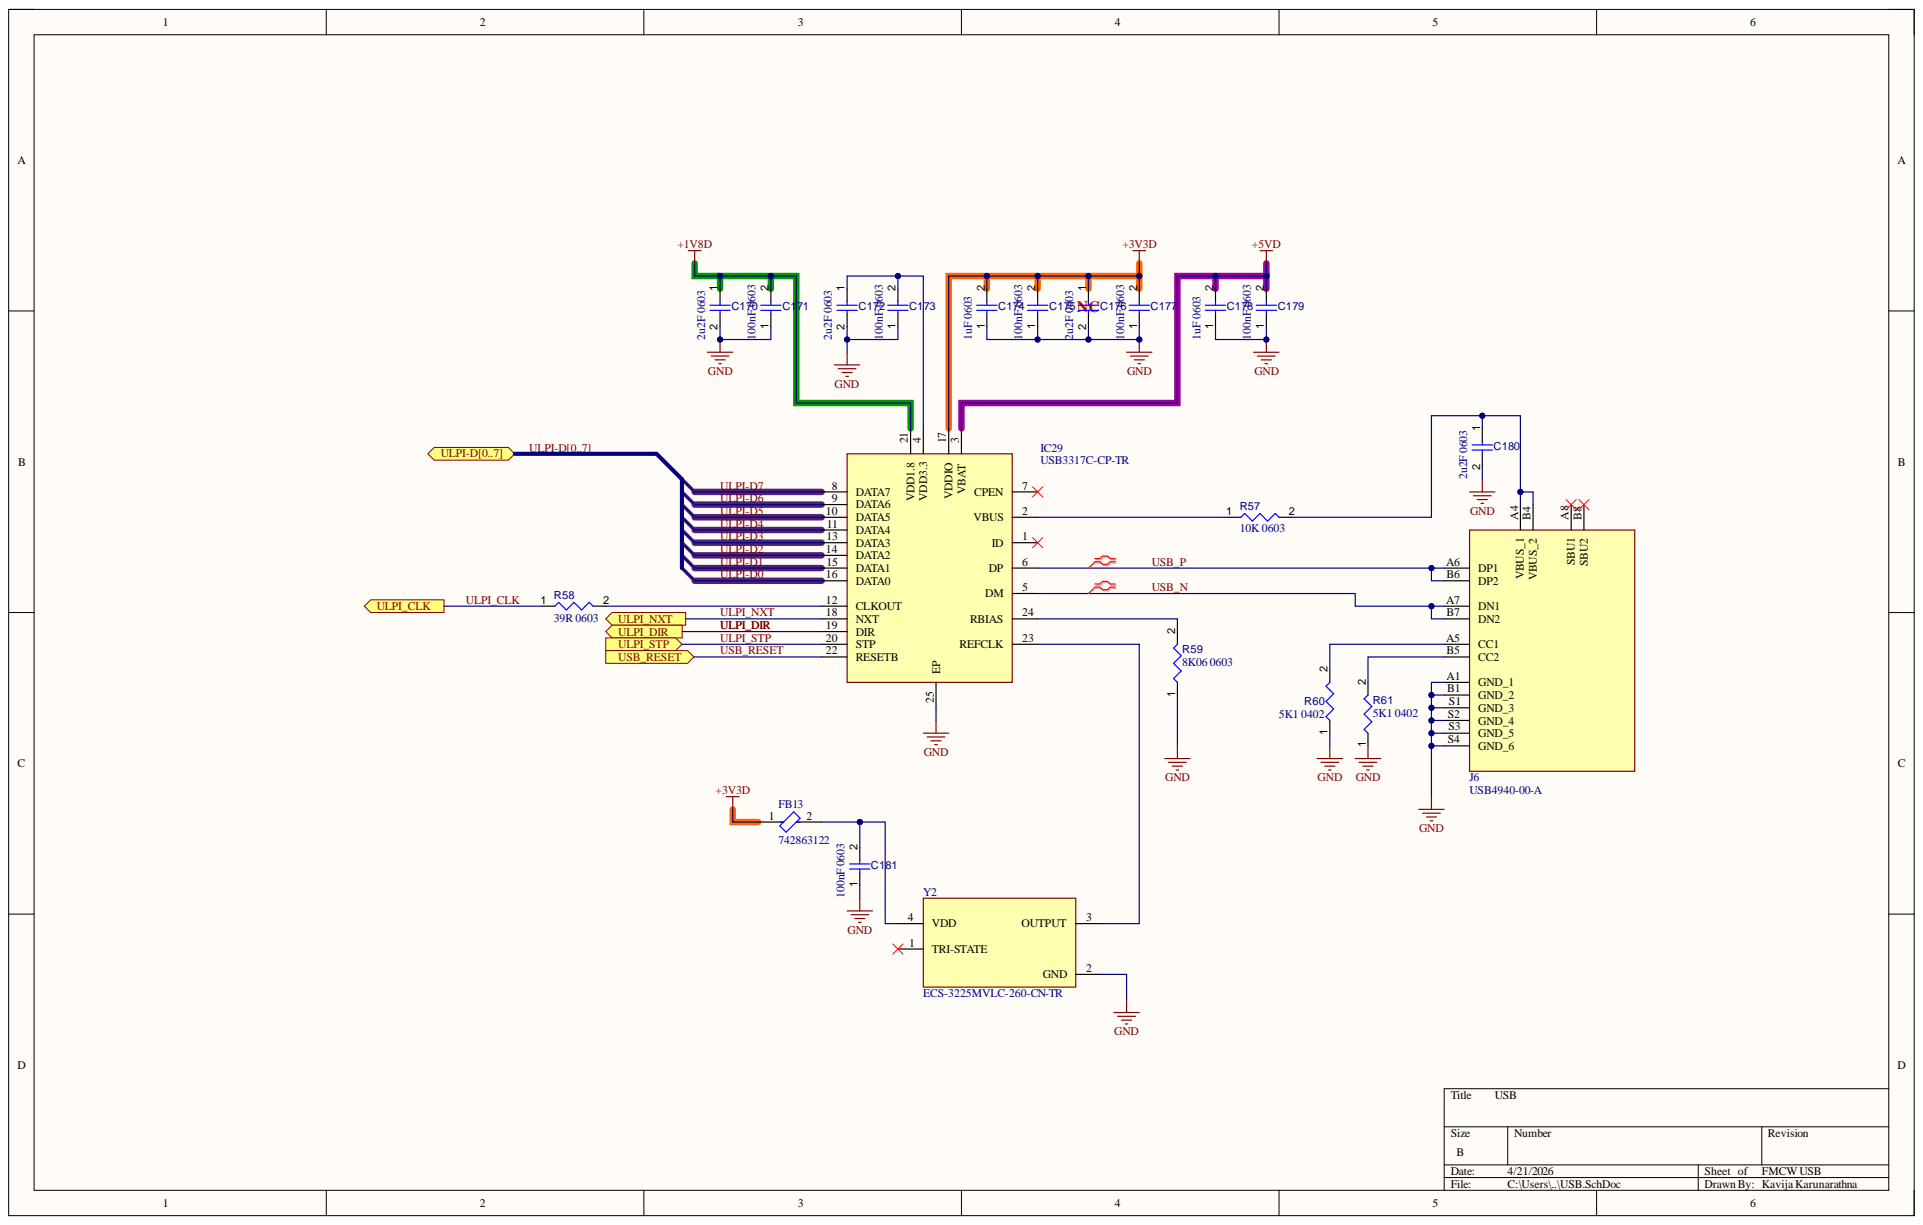
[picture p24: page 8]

Size B | Number | Revision

Date: 4/21/2026 | Sheet of FMCW USB
File: C:\Users\..\USB.SchDoc | Drawn By: Kavija Karunarathna

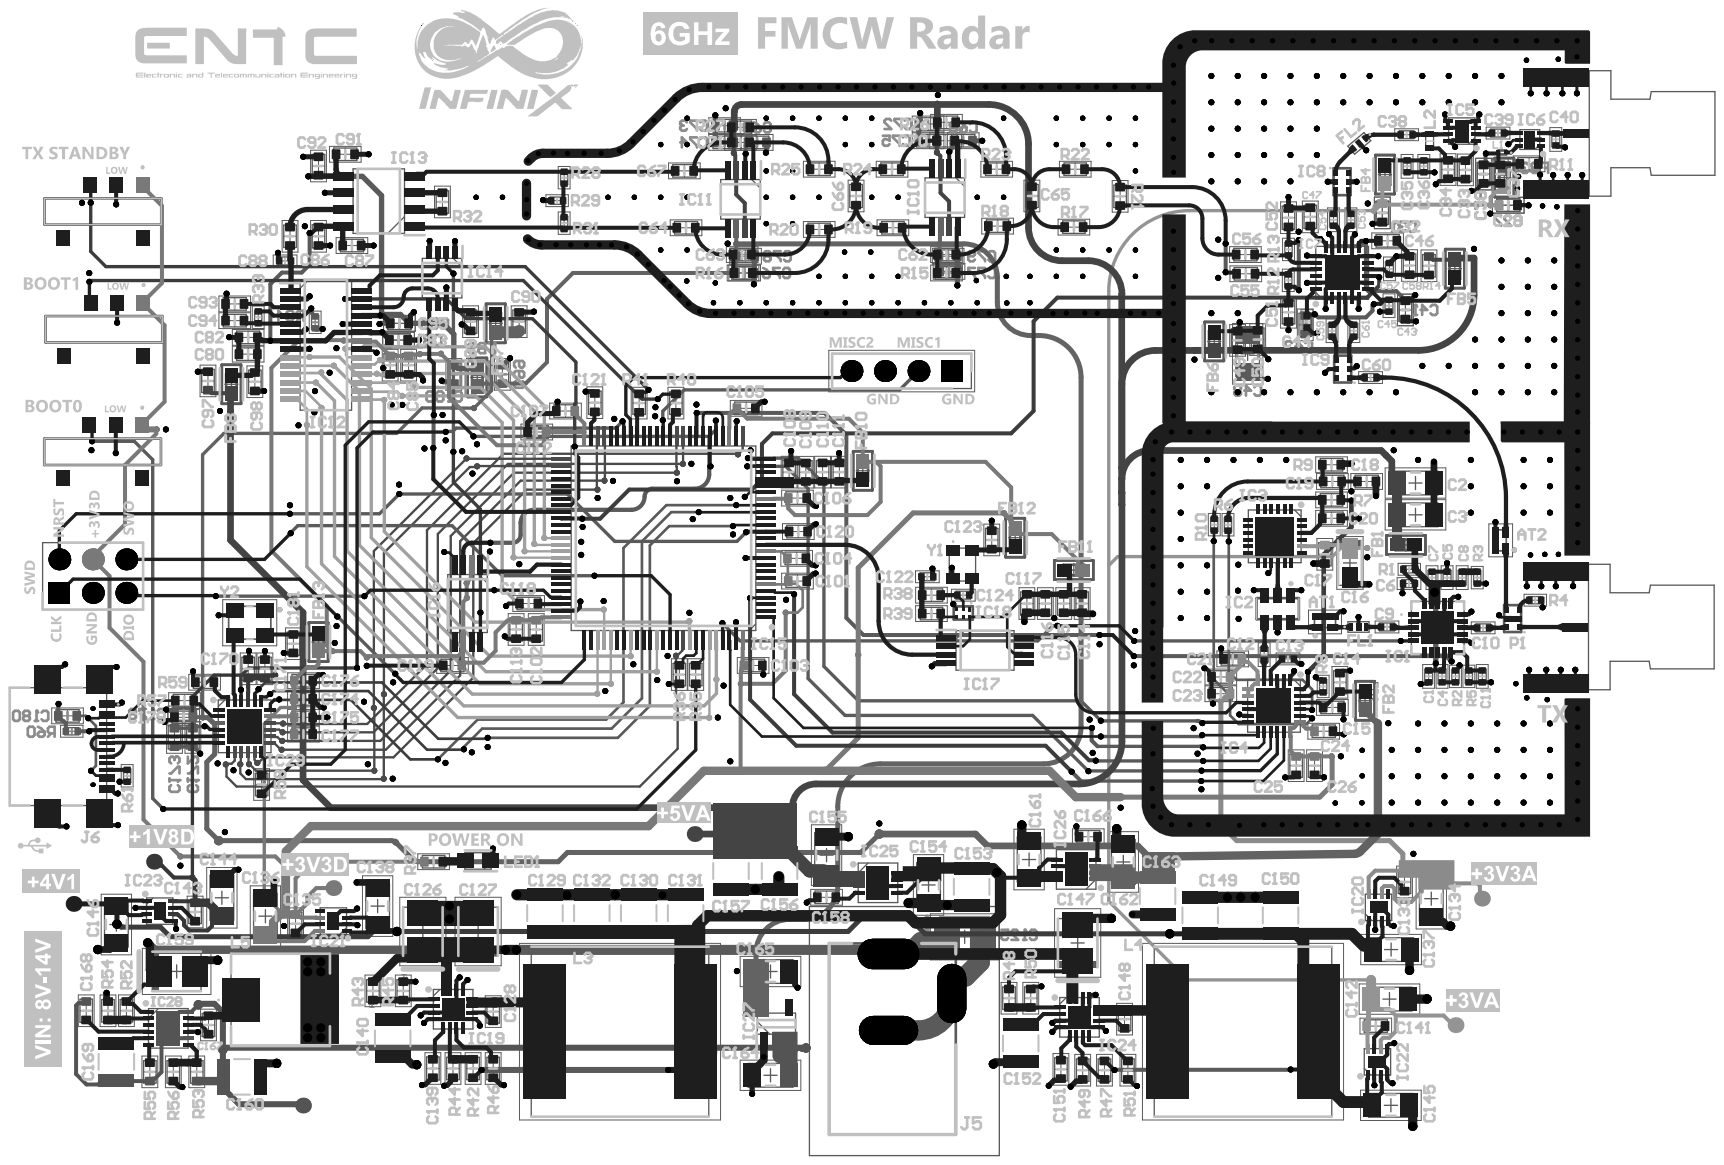
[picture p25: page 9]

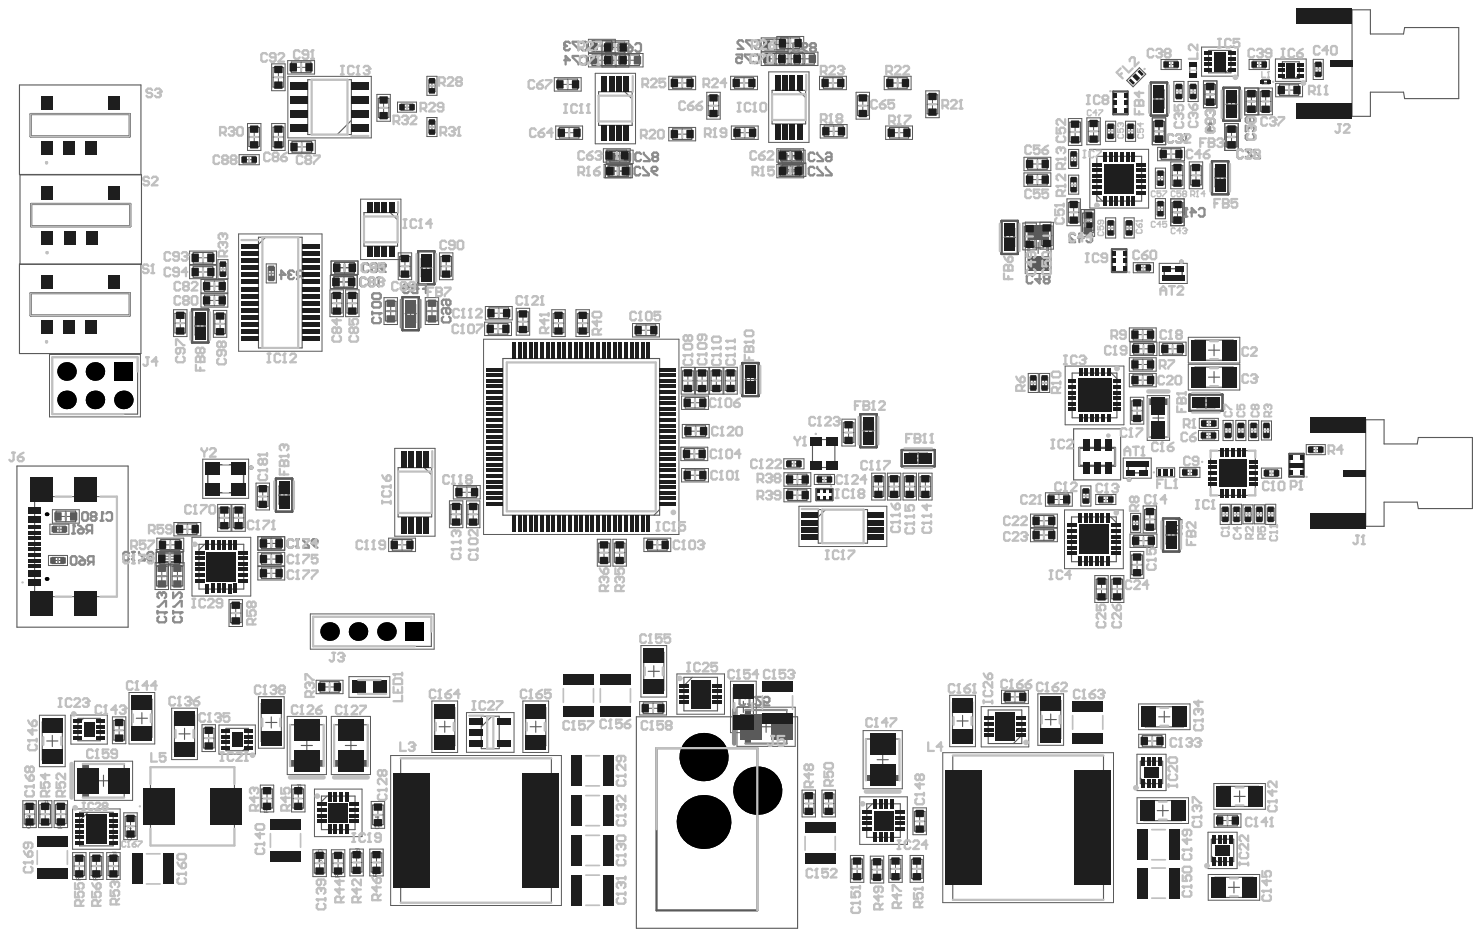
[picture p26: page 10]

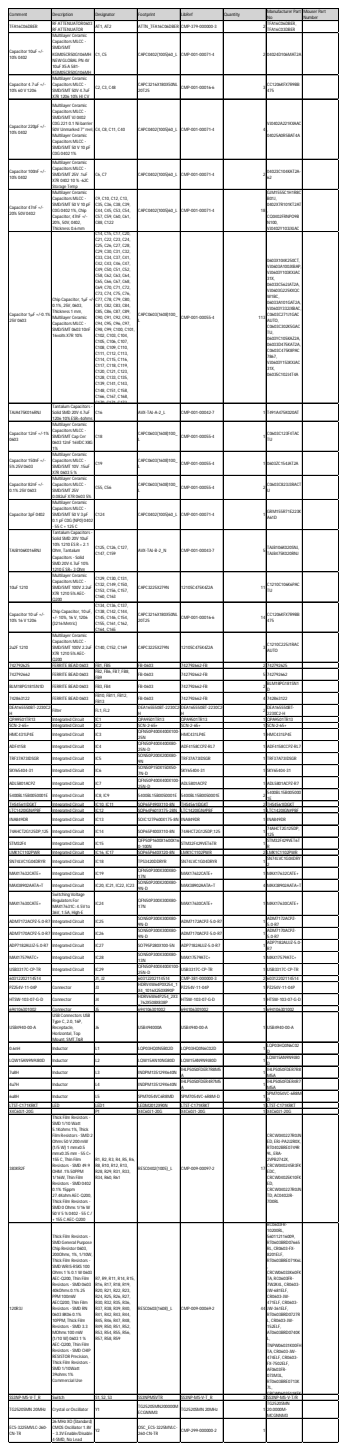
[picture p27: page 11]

Comment | Description | Designator | Footprint | LibRef | Quantity | Manufacturer Part No | Mouser Part Number

TFA16C06DBER | RF ATTENUATOR0603 RF ATTENUATOR | AT1, AT2 | ATTN_TFA16C06DBER | CMP-379-000000-3 | | 2 TFA16C06DBER, TFA16C03DBER

Capacitor 10uF +/-10% 0402 | Multilayer Ceramic Capacitors MLCC -SMD/SMT KGM05CR50G106MH NEW GLOBAL PN 4V 10uF X5 A 581-KGM05CR50G106MH | C1, C5 | CAPC0402(1005)60_L | CMP-001-00071-4 | | 2 04024D106MAT2A

Capacitor 4.7 uF +/-10% 60 V 1206 | Multilayer Ceramic Capacitors MLCC -SMD/SMT 50V 4.7uF X7R 1206 10% HI CV | C2, C3, C48 | CAPC3216X180X50NL 20T25 | CMP-001-00016-6 | | 3 CC1206KFX7R9BB 475

Capacitor 220pF +/-10% 0402 | Multilayer Ceramic Capacitors MLCC -SMD/SMT VJ 0402 C0G 221 0.1 Ni barrier 50V Unmarked 7" reel, Multilayer Ceramic Capacitors MLCC -SMD/SMT 50 V 10 pF C0G 0402 1% | C4, C8, C11, C40 | CAPC0402(1005)60_L | CMP-001-00071-4 | | VJ0402A221KXAAC 4 , 04025A0R5BAT4A

Capacitor 100nF +/-10% 0402 | Multilayer Ceramic Capacitors MLCC -SMD/SMT 25V .1uF X7R 0402 10 % -62C Storage Temp | C6, C7 | CAPC0402(1005)60_L | CMP-001-00071-4 | | 2 04023C104KAT2A-62

Capacitor 47nF +/-20% 50V 0402 | Multilayer Ceramic Capacitors MLCC -SMD/SMT 50 V 10 pF C0G 0402 1%, Chip Capacitor, 47nF +/-20%, 50V, 0402, Thickness 0.6 mm | C9, C10, C12, C13, C35, C36, C38, C39, C44, C45, C53, C54, C57, C59, C60, C61, C88, C122 | CAPC0402(1005)60_L | CMP-001-00071-4 | | GJM1555C1H1R8C B01J, 0402X7R101KT2AT 18 , CQ0402FRNPO9B N100, VJ0402Y103JXJAC

Capacitor 1µF +/-0.1% 25V 0603 | Chip Capacitor, 1µF +/-0.1%, 25V, 0603, Thickness 1 mm, Multilayer Ceramic Capacitors MLCC -SMD/SMT 0603 10nF 16volts X7R 10% | C14, C15, C17, C20, C21, C22, C23, C24, C25, C26, C27, C28, C29, C30, C31, C32, C33, C34, C37, C41, C42, C43, C46, C47, C49, C50, C51, C52, C58, C62, C63, C64, C65, C66, C67, C68, C69, C70, C71, C72, C73, C74, C75, C76, C77, C78, C79, C80, C81, C82, C83, C84, C85, C86, C87, C89, C90, C91, C92, C93, C94, C95, C96, C97, C98, C99, C100, C101, C102, C103, C104, C105, C106, C107, C108, C109, C110, C111, C112, C113, C114, C115, C116, C117, C118, C119, C120, C121, C123, C128, C133, C135, C139, C141, C143, C148, C151, C158, C166, C167, C168, C170, C171, C172, | CAPC0603(1608)100_ L | CMP-001-00055-4 | 113 | 0603X104K250CT, VJ0603A100JXBAP, VJ0603Y103KXJAC 31X, 06033C562JAT2A, VJ0603G225KXQC W1BC, 06033A101GAT2A, VJ0603Y332JXBAC, C0603C271J1GAC AUTO, C0603C302K5GAC TU, 0603YC105KAZ2A, 06033D475KAT2A, C0603C475K8PAC 7867, VJ0603Y153KXJAC 31X, 06035C102J4T4A

TAJA475K016RNJ | Tantalum Capacitors -Solid SMD 20V 4.7uF 1206 10% ESR=4ohms | C16 | AVX-TAJ-A-2_L | CMP-001-00042-7 | | 1 T491A475K020AT

Capacitor 12nF +/-1% 0603 | Multilayer Ceramic Capacitors MLCC -SMD/SMT Cap Cer 0603 12nF 16VDC X8G 1% | C18 | CAPC0603(1608)100_ L | CMP-001-00055-4 | | 1 C0603C123F4TAC TU

Capacitor 150nF +/-5% 25V 0603 | Multilayer Ceramic Capacitors MLCC -SMD/SMT 10V .15uF X7R 0603 5 % | C19 | CAPC0603(1608)100_ L | CMP-001-00055-4 | | 1 0603ZC154JAT2A

Capacitor 82nF +/-0.1% 25V 0603 | Multilayer Ceramic Capacitors MLCC -SMD/SMT 25V 0.082uF X7R 0603 5% | C55, C56 | CAPC0603(1608)100_ L | CMP-001-00055-4 | | 2 C0603C823J3RACT U
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

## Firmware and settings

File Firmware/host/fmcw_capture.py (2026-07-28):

from __future__ import annotations

import argparse
from pathlib import Path
import sys
import time

try:
    import usb.core
    import usb.util
except ImportError:  # pragma: no cover - exercised only on machines without pyusb
    usb = None

try:
    import numpy as np
except ImportError:  # pragma: no cover
    np = None

from fmcw_protocol import (
    FRAME_SIZE,
    HEADER_SIZE,
    MAGIC_BYTES,
    PAYLOAD_SIZE,
    SAMPLES_PER_SLOPE,
    parse_header,
)


def open_bulk_in(vid: int, pid: int):
    if usb is None:
        raise RuntimeError("pyusb is not installed; run `pip install -r host/requirements.txt`")

    dev = usb.core.find(idVendor=vid, idProduct=pid)
    if dev is None:
        raise RuntimeError(f"USB device {vid:04x}:{pid:04x} not found")

    try:
        if dev.is_kernel_driver_active(0):
            dev.detach_kernel_driver(0)
    except (NotImplementedError, usb.core.USBError):
        pass

    dev.set_configuration()
    cfg = dev.get_active_configuration()
    intf = cfg[(0, 0)]
    ep_in = usb.util.find_descriptor(
        intf,
        custom_match=lambda e: (
            usb.util.endpoint_direction(e.bEndpointAddress) == usb.util.ENDPOINT_IN
            and usb.util.endpoint_type(e.bmAttributes) == usb.util.ENDPOINT_TYPE_BULK
        ),
    )
    if ep_in is None:
        raise RuntimeError("bulk IN endpoint not found")
    return dev, ep_in


def read_exact(ep_in, size: int, timeout_ms: int) -> bytes:
    data = bytearray()
    while len(data) < size:
        chunk = ep_in.read(size - len(data), timeout=timeout_ms)
        data.extend(bytes(chunk))
    return bytes(data)


class FrameReader:
    def __init__(self, ep_in, timeout_ms: int):
        self.ep_in = ep_in
        self.timeout_ms = timeout_ms
        self.buf = bytearray()

    def read_frame(self) -> tuple[object, bytes]:
        while len(self.buf) < FRAME_SIZE:
            self.buf.extend(read_exact(self.ep_in, FRAME_SIZE - len(self.buf), self.timeout_ms))

        while True:
            pos = self.buf.find(MAGIC_BYTES)
            if pos < 0:
                self.buf.clear()
                self.buf.extend(read_exact(self.ep_in, FRAME_SIZE, self.timeout_ms))
                continue
            if pos:
                del self.buf[:pos]
            while len(self.buf) < FRAME_SIZE:
                self.buf.extend(read_exact(self.ep_in, FRAME_SIZE - len(self.buf), self.timeout_ms))
            header = parse_header(self.buf[:HEADER_SIZE])
            try:
                header.validate()
            except ValueError:
                del self.buf[0:1]
                continue
            frame = bytes(self.buf[:FRAME_SIZE])
            del self.buf[:FRAME_SIZE]
            return header, frame


def payload_to_samples(payload: bytes):
    if np is None:
        return None
    return np.frombuffer(payload, dtype="<u2", count=SAMPLES_PER_SLOPE) & 0x0FFF


def main(argv: list[str] | None = None) -> int:
    parser = argparse.ArgumentParser(description="Capture STM32 FMCW radar frames over USB HS bulk IN.")
    parser.add_argument("--vid", type=lambda x: int(x, 0), default=0x0483)
    parser.add_argument("--pid", type=lambda x: int(x, 0), default=0x5740)
    parser.add_argument("--frames", type=int, default=0, help="number of frames to capture; 0 means forever")
    parser.add_argument("--timeout-ms", type=int, default=2000)
    parser.add_argument("--raw", type=Path, help="write complete 20,064-byte frames to this file")
    parser.add_argument("--npy", type=Path, help="write uint16 sample matrix to .npy after capture")
    parser.add_argument("--stats", action="store_true", help="print running sequence/flag stats")
    parser.add_argument("--fft", action="store_true", help="print peak FFT bin for each frame")
    args = parser.parse_args(argv)

    if args.npy and np is None:
        raise RuntimeError("numpy is required for --npy")
    if args.fft and np is None:
        raise RuntimeError("numpy is required for --fft")

    _, ep_in = open_bulk_in(args.vid, args.pid)
    reader = FrameReader(ep_in, args.timeout_ms)

    raw_file = args.raw.open("wb") if args.raw else None
    samples = [] if args.npy else None
    frames = 0
    dropped = 0
    last_seq = None
    start = time.monotonic()

    try:
        while args.frames == 0 or frames < args.frames:
            header, frame = reader.read_frame()
            payload = frame[HEADER_SIZE:]
            if raw_file:
                raw_file.write(frame)
            if last_seq is not None and header.slope_seq != last_seq + 1:
                dropped += header.slope_seq - last_seq - 1
            last_seq = header.slope_seq

            if header.flags:
                dropped += 1 if header.flags & 0x01 else 0

            frame_samples = payload_to_samples(payload)
            if samples is not None and frame_samples is not None:
                samples.append(frame_samples.copy())
            if args.fft and frame_samples is not None:
                spectrum = np.fft.rfft(frame_samples.astype(np.float32) - 2048.0)
                peak = int(np.argmax(np.abs(spectrum[1:])) + 1)
                print(f"seq={header.slope_seq} slope={header.slope_id} peak_bin={peak} flags={header.flag_names}")

            frames += 1
            if args.stats and (frames == 1 or frames % 100 == 0):
                elapsed = max(time.monotonic() - start, 1e-9)
                mb_s = (frames * FRAME_SIZE) / elapsed / 1_000_000
                print(
                    f"frames={frames} seq={header.slope_seq} mux={header.muxout_count} "
                    f"flags={header.flag_names or '-'} gaps={dropped} rate={mb_s:.2f} MB/s"
                )
    finally:
        if raw_file:
            raw_file.close()

    if args.npy and samples is not None:
        np.save(args.npy, np.vstack(samples) if samples else np.empty((0, SAMPLES_PER_SLOPE), dtype=np.uint16))

    return 0


if __name__ == "__main__":
    raise SystemExit(main())

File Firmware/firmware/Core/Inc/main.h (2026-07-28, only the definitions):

#define PLL_CLK_Pin GPIO_PIN_2
#define PLL_CLK_GPIO_Port GPIOE
#define PLL_MUXOUT_Pin GPIO_PIN_5
#define PLL_MUXOUT_GPIO_Port GPIOE
#define PLL_DATA_Pin GPIO_PIN_6
#define PLL_DATA_GPIO_Port GPIOE
#define ULP_STP_Pin GPIO_PIN_0
#define ULP_STP_GPIO_Port GPIOC
#define ULPI_DIR_Pin GPIO_PIN_2
#define ULPI_DIR_GPIO_Port GPIOC
#define ULPI_NXT_Pin GPIO_PIN_3
#define ULPI_NXT_GPIO_Port GPIOC
#define PLL_LE_Pin GPIO_PIN_1
#define PLL_LE_GPIO_Port GPIOA
#define PLL_TXDATA_Pin GPIO_PIN_2
#define PLL_TXDATA_GPIO_Port GPIOA
#define ULPI_D0_Pin GPIO_PIN_3
#define ULPI_D0_GPIO_Port GPIOA
#define ULPI_CLK_Pin GPIO_PIN_5
#define ULPI_CLK_GPIO_Port GPIOA
#define PDET_Pin GPIO_PIN_4
#define PDET_GPIO_Port GPIOC
#define ULPI_D1_Pin GPIO_PIN_0
#define ULPI_D1_GPIO_Port GPIOB
#define ULPI_D2_Pin GPIO_PIN_1
#define ULPI_D2_GPIO_Port GPIOB
#define MISC1_Pin GPIO_PIN_7
#define MISC1_GPIO_Port GPIOE
#define TX_STDBY_Pin GPIO_PIN_11
#define TX_STDBY_GPIO_Port GPIOE
#define MISC2_Pin GPIO_PIN_12
#define MISC2_GPIO_Port GPIOE
#define USB_RESET_Pin GPIO_PIN_13
#define USB_RESET_GPIO_Port GPIOE
#define ULPI_D3_Pin GPIO_PIN_10
#define ULPI_D3_GPIO_Port GPIOB
#define ULPI_D4_Pin GPIO_PIN_11
#define ULPI_D4_GPIO_Port GPIOB
#define ULPI_D5_Pin GPIO_PIN_12
#define ULPI_D5_GPIO_Port GPIOB
#define ULPI_D6_Pin GPIO_PIN_13
#define ULPI_D6_GPIO_Port GPIOB
#define ADC_OF_Pin GPIO_PIN_11
#define ADC_OF_GPIO_Port GPIOD
#define ADC_GAIN_Pin GPIO_PIN_12
#define ADC_GAIN_GPIO_Port GPIOD
#define MIXER_EN_Pin GPIO_PIN_13
#define MIXER_EN_GPIO_Port GPIOD
#define SWD_IO_Pin GPIO_PIN_13
#define SWD_IO_GPIO_Port GPIOA
#define SWD_CLK_Pin GPIO_PIN_14
#define SWD_CLK_GPIO_Port GPIOA
#define SWD_SWO_Pin GPIO_PIN_3
#define SWD_SWO_GPIO_Port GPIOB
#define ULPI_D7_Pin GPIO_PIN_5
#define ULPI_D7_GPIO_Port GPIOB
#define PA_EN_Pin GPIO_PIN_0
#define PA_EN_GPIO_Port GPIOE
#define PLL_CE_Pin GPIO_PIN_1
#define PLL_CE_GPIO_Port GPIOE

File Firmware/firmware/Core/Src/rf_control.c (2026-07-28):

#include "rf_control.h"

#include "main.h"

#include <stdio.h>

static void RFConfigurePins(void);

void RFEnable(void)
{
  RFConfigurePins();

  if (HAL_GPIO_ReadPin(TX_STDBY_GPIO_Port, TX_STDBY_Pin) == GPIO_PIN_RESET)
  {
    RFDisable();
    printf("RF: TX_STDBY is low, RF output disabled\r\n");
    return;
  }

  HAL_GPIO_WritePin(MIXER_EN_GPIO_Port, MIXER_EN_Pin, GPIO_PIN_RESET);
//HAL_GPIO_WritePin(PA_EN_GPIO_Port, PA_EN_Pin, GPIO_PIN_SET);
  printf("RF: MIXER_EN=0(active) PA_EN=1\r\n");
}

void RFDisable(void)
{
  RFConfigurePins();
  HAL_GPIO_WritePin(MIXER_EN_GPIO_Port, MIXER_EN_Pin, GPIO_PIN_SET);
  HAL_GPIO_WritePin(PA_EN_GPIO_Port, PA_EN_Pin, GPIO_PIN_RESET);
}

static void RFConfigurePins(void)
{
  GPIO_InitTypeDef gpio = {0};

  __HAL_RCC_GPIOE_CLK_ENABLE();
  __HAL_RCC_GPIOD_CLK_ENABLE();

  gpio.Pin = TX_STDBY_Pin;
  gpio.Mode = GPIO_MODE_INPUT;
  gpio.Pull = GPIO_NOPULL;
  HAL_GPIO_Init(TX_STDBY_GPIO_Port, &gpio);

  gpio.Pin = PA_EN_Pin;
  gpio.Mode = GPIO_MODE_OUTPUT_PP;
  gpio.Pull = GPIO_NOPULL;
  gpio.Speed = GPIO_SPEED_FREQ_LOW;
  HAL_GPIO_Init(PA_EN_GPIO_Port, &gpio);

  gpio.Pin = MIXER_EN_Pin;
  HAL_GPIO_Init(MIXER_EN_GPIO_Port, &gpio);
}

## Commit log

2026-04-24 Designed the transmitter
    [Transmitter.SchDoc]
2026-04-24 Designed the reciever
    [Receiver.SchDoc]
2026-04-24 Designed the mixer
    [Mixer.SchDoc]
2026-04-24 Designed the IF Filter
    [VideoFiltering.SchDoc]
2026-04-24 Designed the STM32 conections
    [MCU.SchDoc]
2026-04-24 Designed the USB transiever
    [USB.SchDoc]
2026-04-24 Designed the Power Supply
    [PowerSupply.SchDoc]
2026-04-24 Designed the ADC
    [ADC.SchDoc]
2026-04-24 Added the completed PCB layout
2026-04-24 Added the final BOM
    [Final BOM.csv]
2026-05-20 Built a foundation to get the project started. Will continue with tweaks and bug fixes
    [fmcw_capture.py, fmcw_protocol.py, main.h]
2026-06-18 Added VDET sensing (Power Amplifier)
2026-06-19 Setup DCMI, and ADC sampling
2026-06-24 Add comprehensive README for Video Filtering simulation with Chebyshev high-pass and passive low-pass filter design
2026-06-24 docs(Video Filtering): update README — clarify bandwidth and group delay; update future improvements (PCB test, adjust INA R19); remove programmable gain stage
2026-06-24 Update README to remove Chebyshev Filter section
    Removed Chebyshev Filter Design Theory from the list.
2026-07-01 Entire chain integrated. Smooth streaming and balanced data rates
2026-07-02 Update README: change filter architecture to passive two-stage high-pass + active 4th-order Chebyshev low-pass
2026-07-02 Update filename in README for LTSPICE schematic
2026-07-06 Revise Distance Measurement
    Updated README to clarify the module's purpose and mathematical principles behind distance measurement using FMCW radar. Added sections on range resolution and algorithmic flow.
2026-07-06 Revise velocity estimation
2026-07-07 Update Hardware/Testing/README.md with selftest, rx, tx, and antenna test details
2026-07-08 Update: Document low-pass filter design using FilterPro by Texas Instruments
2026-07-08 Add images to Video Filtering README documentation
2026-07-09 Damaged folder structure recovered
    [FMCWRadarFirmware.ioc, adf4158.c, fmcw_breathing_view.py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]
2026-07-09 Shifted 2D FFT to PyQT and also removed noise
    [Triangular.py, Triangular_pyqt.py]
2026-07-28 Add SolidWorks Infinix Main Enclosure files
    [3D_PCB_PCB_FMCWPower_2026-06-25_2026-06-25.step, 40x40x10 DC Fan.SLDPRT, Assem12_1.SLDASM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]
2026-08-09 Add README for Antenna Mechanical Models
    Added README.md with details about antenna mechanical models, design preview, files, and manufacturing specifications.
2026-08-09 Rename Copy of Black and White Illustrative Project Proposal Presentation.png to Antenna Design Sketch.png
2026-08-09 Rename Antenna Design Sketch.png to antenna_sketch.png
2026-08-09 Rename Antenna design files to Horn Antenna
2026-08-09 Add README for STEP files in Antenna Mount folder
    This README provides information on the contents and usage of the STEP files.
2026-08-09 move Horn_Antenna_15dBi.STEP file
    [Horn_Antenna_15dBi.STEP]

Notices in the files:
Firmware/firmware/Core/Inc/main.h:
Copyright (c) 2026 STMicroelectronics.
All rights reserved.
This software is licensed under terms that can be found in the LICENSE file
